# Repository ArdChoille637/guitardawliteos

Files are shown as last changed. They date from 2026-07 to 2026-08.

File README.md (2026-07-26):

# GuitarDAWLiteOS

Bare-metal **Raspberry Pi 5** loop recorder / guitarist workbench. I²S audio (PCM1808 ADC + PCM5102A DAC), SD recording, a plain display (no touch) with **5 rotary-encoder knobs + a sustain-pedal footswitch** as the interface — **no OS, no USB in the audio path.** Built on the [Circle](https://github.com/rsta2/circle) bare-metal framework (GPLv3).

> **This is the project front door.** Everything links from here.

## Status — 2026-07-10
- 🎉 **FIRST HARDWARE BOOT — success, first try.** Pi 5 (2GB) booted the M3 audio-engine kernel over HDMI: all 4 cores up, `I2S full duplex (TXRX): RUNNING`, capture counting **exactly 48,000 frames/s**, zero drops, zero ring overruns, storage drain at exactly the audio rate, thermal loop live. Milestone 0 ✅, Spike A ✅ (RP1 proven by the running I²S DMA itself), M3 engine verified live (codecs still to wire).
- ✅ **Research verified.** 29 load-bearing claims checked against primary sources. 6 were wrong; 3 of those change the build. → [docs/claim-verification.md](docs/claim-verification.md)
- ✅ **Spike B done.** Internal MCLK route impossible (`clk_i2s` is claimed by BCLK); an Arduino Nano ESP32 generates 12.2880 MHz instead, bench-verified via its own PCNT peripheral. → [esp32-mclk/](esp32-mclk/)
- ✅ **Milestone 3 code live** — full-duplex I²S monitor path (~1.0 ms worst-case in→out), lock-free SPMC broadcast ring (seqlock reserve/commit; host tests caught a real torn-read bug pre-hardware; passes plain + ThreadSanitizer), 4-core split. Adversarially reviewed (5 lenses, 2 rounds); the review caught a critical `KERNEL_MAX_SIZE` boot-blocker before first boot. → [src/](src/), [tests/](tests/), [planning/build-plan.md](planning/build-plan.md)
- ⏭️ **Next: Milestone 2 wiring** — breadboard the codecs + front-end per [docs/breadboard-build.md](docs/breadboard-build.md) (DAC playback first for the fastest win), Nano ESP32 → PCM1808 SCKI, then the M3 gate: clean tone in→out, 10 min, zero underruns.

## The 6 things verification changed (read before building)
1. **No `≤128` DMA chunk cap** — it's a constructor arg, default **8192**. Ring-buffer/SD batching gets *easier*. The doc was wrong.
2. **Pi 5 SD = BCM2712 SDHCI (`CEMMCDevice`, `0x1000FFF000`), not RP1, not `CSDHCIDevice`.** Tested & supported.
3. **Do NOT add `pciex4_reset=0`** with Circle — Circle brings up the PCIe root complex itself. Stock `config.txt`.
4. **MCLK cannot come from the Pi 5's own GPIO while I²S is running.** `clk_i2s` — the only RP1 clock generator with `pll_audio` as a parent — is already claimed for BCLK. **→ external MCLK generator (Nano ESP32), see Spike B above.**
5. **The two "MIT" libs (simplecodec3, Yin-Pitch-Tracking) are unlicensed** (all-rights-reserved). YIN patent is **expired** → clean-room reimplement from the 2002 paper.
6. **(2026-07-09)** Even the *revised* internal-MCLK mechanism from correction #4 (`clk_i2s→clk_gp0→GPIO4`) turned out to be a resource conflict, not just missing Circle code — see [claim-verification.md](docs/claim-verification.md).

## Hardware (Phase 1)
- Raspberry Pi 5 · microSD (Class-10/UHS-I) · HDMI monitor ≤1080p · USB-serial for the UART debug console.
- PCM1808 ADC (**bus master**, strap-only) · PCM5102A / GY-PCM5102 DAC (strap-only).
- **Arduino Nano ESP32** — external MCLK generator (see [esp32-mclk/](esp32-mclk/)), electrically independent of the Pi 5 except for the MCLK line + shared ground.

**Verified pin map** ([details](planning/build-plan.md#milestone-2--hardware-bring-up-i²s-loopback)) — **the PCM1808 masters the I²S bus** (2026-07-10 pivot: two free-running crystals can't stay fs-locked, so the ADC divides the Nano's MCLK into BCK/LRCK and the Pi runs I²S slave — see [docs/claim-verification.md](docs/claim-verification.md)):

| Source | Signal | → |
|--:|---|---|
| **PCM1808 BCK** | BCLK 3.072 MHz (ADC-driven) | Pi GPIO18 + DAC BCK |
| **PCM1808 LRCK** | LRCLK 48 kHz (ADC-driven) | Pi GPIO19 + DAC LCK |
| PCM1808 DOUT | data IN (capture) | → Pi GPIO20 |
| Pi GPIO21 | data OUT (playback) | → PCM5102A DIN |
| **Nano ESP32 D2/GPIO5** | MCLK 12.288 MHz | → PCM1808 SCKI only |

⚠️ **PCM5102A breakout: set the XSMT pad HIGH (unmute)** — ships muted. ⚠️ **PCM1808: strap MD1=MD0=HIGH (master 256fs), FMT=GND, before power-on** — board-specific pin table in [docs/adc-hookup.md](docs/adc-hookup.md).

## Map
- **[planning/build-plan.md](planning/build-plan.md)** — milestones 0–6, tasks with effort, risk register, pinned dependencies.
- **[docs/claim-verification.md](docs/claim-verification.md)** — full verdict table + 6 consequential corrections with sources.
- **[docs/hardware-review.md](docs/hardware-review.md)** — datasheet-verified BOM, power tree, connection/netlist table, **guitar front-end design**, grounding, risk register.
- **[docs/schematic.md](docs/schematic.md)** — buildable schematic: refdes BOM, net-by-net netlist, **SPICE-verified** front-end, build order, ERC self-check (netlist = rev-A Pi-as-master; see its pivot banner). Sheets: [front-end 5 V](docs/frontend-schematic.svg) · [front-end 9 V TL072 (as-built)](docs/tl072-frontend-schematic.svg) · [codec & clocks (as-built)](docs/codec-power-schematic.svg). Sim: [sim/](docs/sim/).
- **[docs/wiring-diagram.svg](docs/wiring-diagram.svg)** — as-built bench wiring overview (Nano MCLK → PCM1808 **bus master** → Pi 5 slave + PCM5102A; clocks/data/power domains).
- **[kicad/](kicad/)** — openable **KiCad project** (`guitardawliteos.kicad_pro`, KiCad-10-verified) + generated netlist/symbols/BOM from `gen.py` (ERC-checked). See [kicad/README.md](kicad/README.md).
- **[docs/pcb-learning-path.md](docs/pcb-learning-path.md)** — **follow-along PCB-design curriculum + open-hardware roadmap** (M1 board-from-netlist → M4 Pi 5 HAT → M6 rev-B HAT+ → M7 faceplate → M8 retro deck → M9 CM5 carrier), hackability + licensing.
- **[docs/parts-order.md](docs/parts-order.md)** — **DigiKey prototyping order** (verified live 2026-07-01): breadboard + codecs + front-end + tape Level A + Touch Display 2, with MPNs, quantities, substitutions for dead parts, and the not-DigiKey list.
- **[docs/retro-deck-design.md](docs/retro-deck-design.md)** — **Phase-2 architecture (verified; UI pivot 2026-07-23)**: **5 rotary encoders + sustain pedal + display-only panel** (TD2 via `rp1dsi` with `bEnableTouch=FALSE`, zero GPIO — or plain HDMI; SPI TFT ruled out), cassette tape loop as analog insert (Level A ships in rev B, VINR return + REM punch-in), three-layer retro mechanicals, recomputed rev-B GPIO budget (J8 fully allocated + MCP23017 expander).
- **[docs/breadboard-build.md](docs/breadboard-build.md)** + [breadboard-layout.svg](docs/breadboard-layout.svg) — solderless build with the GY modules + a DIP op-amp; placement + step-by-step + gotcha checklist.
- **[docs/adc-hookup.md](docs/adc-hookup.md)** — **bench card: every wire for Pi 5 + PCM1808 + Nano ESP32 capture hookup** (power, ground, straps, clocks, data, order of operations).
- **[docs/tl072-frontend.md](docs/tl072-frontend.md)** — **drawer-parts front-end variant: TL072 on 9 V** (SPICE-verified; two changes from the canonical schematic) + CD4053BE rev-B notes. Schematic sheet: [tl072-frontend-schematic.svg](docs/tl072-frontend-schematic.svg).
- **[docs/build-setup.md](docs/build-setup.md)** — toolchain, build, SD flash, UART.
- **[docs/debug-probe.md](docs/debug-probe.md)** — **Raspberry Pi Debug Probe on the Pi 5**: UART console (mode A) vs. SWD breakpoint debugging of all four cores (mode B), cabling, and the GPIO14/15 conflict with the encoder pinout.
- Original Phase-1 research reference: project `CLAUDE.md` (the GuitarDAWLiteOS research doc).

## Build foundation (pinned)
Circle `develop` @ `22722a7` · `RASPPI=5` → `kernel_2712.img` · FatFs R0.16 (`addon/fatfs`) · YIN clean-room.

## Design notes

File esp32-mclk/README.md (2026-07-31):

# esp32-mclk

Standalone MCLK generator for the PCM1808 ADC, running on an **Arduino Nano
ESP32** (ESP32-S3). This is the resolution to Spike B — the Pi 5 cannot
generate a `pll_audio`-locked 12.288 MHz clock on any GPIO while its I²S
peripheral is running (see [../docs/claim-verification.md](../docs/claim-verification.md),
"Update 2026-07-09"). This board sidesteps the problem entirely by generating
MCLK off-chip.

**✅ Bench-tested 2026-07-09**, without a scope — see "How it was verified"
below. Measured **12.2880 MHz**, exact match to target.

## What it does

`esp32-mclk.ino` configures the ESP32-S3's `i2s_std` peripheral as an
MCLK-only clock source:
- Sample rate 48 kHz, `mclk_multiple = I2S_MCLK_MULTIPLE_256` → 12.288 MHz,
  using the driver's default clock source (`I2S_CLK_SRC_DEFAULT` = the
  general-purpose `PLL_160M`). **Correction:** an earlier version of this
  file said ESP32-S3 has a dedicated Audio PLL (APLL) and that the code
  explicitly selected it. Neither is true — APLL is original-ESP32-only
  (confirmed against the installed SDK's `soc/clk_tree_defs.h`); the S3's
  `i2s_std` clock source options are just `PLL_160M`/`PLL_240M`/`XTAL`. The
  code now just uses the driver's sane default rather than requesting a
  clock source that doesn't exist on this chip.
- BCLK/WS/DATA GPIOs are all `I2S_GPIO_UNUSED` — only the MCLK pin is driven.
  Since the 2026-07-10 clock pivot the **PCM1808 divides this MCLK into
  BCLK/LRCLK** (it straps as bus master) and the Pi 5 runs I²S *slave* on
  GPIO18/19/20/21 — see [docs/adc-hookup.md](../docs/adc-hookup.md); this
  board never touches those signals either way.
- A built-in **self-test**: the ESP32-S3's PCNT (pulse counter) peripheral
  counts edges on D3 (GPIO6) and prints the measured frequency once a
  second — see below.

## How it was verified (no oscilloscope on hand)

Jumper **D2 → D3** (GPIO5 → GPIO6) so the MCLK output loops back into the
chip's own PCNT counter input, then watch the Serial Monitor at 115200 baud:
a fresh reading prints every second, e.g. `Measured MCLK: 12.2880 MHz
(target 12.288000 MHz)`. This confirms the output frequency is correct; it
does **not** characterize jitter or duty cycle the way a real scope would —
not expected to matter for a consumer-grade ADC like the PCM1808, which per
`[CORR-4]`/E2 only needs fs-sync, not phase-lock. **Remove the D2–D3 jumper**
before wiring the board to the real PCM1808 — the self-test loopback isn't
part of normal operation.

## Build & flash

1. Arduino IDE (or `arduino-cli`) with the **esp32:esp32 core v3.x**
   (Espressif's own board index, not Arduino's `arduino:esp32` package —
   that one tops out at ESP-IDF 4.4 and lacks the `driver/i2s_std.h` /
   `driver/pulse_cnt.h` APIs used here). Board index URL:
   `https://raw.githubusercontent.com/espressif/arduino-esp32/gh-pages/package_esp32_index.json`
2. Board: **`esp32:esp32:nano_nora`** ("Arduino Nano ESP32" in the IDE's
   board list under the Espressif index — a different FQBN from the
   Arduino-index entry of the same display name).
3. Open `esp32-mclk.ino`, select the board's port, upload.
   - **This board's native USB has no auto-reset circuit** — uploads don't
     "just work" the way they do on boards with an FTDI/CH340 chip.
     Uploading via `arduino-cli upload` / the IDE's dfu-util path may fail
     with "No DFU capable USB device available." If so, flash directly with
     `esptool` instead (see below) while the board is in **Native Boot
     mode**: short pin **B1 to GND**, press **RESET** once, confirm the
     onboard RGB LED goes solid **purple**, then flash. Afterward, remove
     the B1–GND jumper and press RESET once (single tap) to boot normally.
4. Open the Serial Monitor at 115200 baud — expect a startup banner
   followed by a `Measured MCLK: ...` line every second.

### Manual esptool flash (if dfu-util upload fails)
```sh
arduino-cli compile --fqbn esp32:esp32:nano_nora --build-path /tmp/esp32-mclk-build .

PLATFORM=<arduino15>/packages/esp32/hardware/esp32/3.3.10   # find via: arduino-cli core list
BUILD=/tmp/esp32-mclk-build
PORT=<port shown while the board is in Native Boot mode / solid purple LED>

esptool --chip esp32s3 --port "$PORT" --before default-reset --after hard-reset write-flash -z \
  --flash-mode dio --flash-freq 80m --flash-size 16MB \
  0x0      "$BUILD/esp32-mclk.ino.bootloader.bin" \
  0x8000   "$BUILD/esp32-mclk.ino.partitions.bin" \
  0xe000   "$PLATFORM/tools/partitions/boot_app0.bin" \
  0xf70000 "$PLATFORM/variants/arduino_nano_nora/extra/nora_recovery/nora_recovery.ino.bin" \
  0x10000  "$BUILD/esp32-mclk.ino.bin"
```

## Wiring (to the PCM1808, after the self-test jumper is removed)

| Nano ESP32 pin | Signal | → |
|---|---|---|
| D2 (GPIO5) | MCLK 12.288 MHz | PCM1808 **SCKI (pin 6)** only |
| GND | common ground | tie to the Pi 5 / breadboard ground |

**On the bench: power the Nano ESP32 from its own USB-C.** Do **not** feed the
5 V breadboard rail into VIN — the VIN regulator wants 6–21 V, so 5 V is out of
spec. On the bench it is electrically independent of the Pi 5 audio board except
for the MCLK line and a shared ground.

*(Target build: VIN from the rig's +9 V rail, 7809 off the central 18 V pack —
`docs/power-tree-18v.md`. Not raw 18 V: a fresh pack sits near 20.5 V, too close
to the 21 V ceiling.)*

## Why not the Pi 5 / a Pico / a Si5351

- **Pi 5 GPCLK0 (internal):** ruled out — `clk_i2s` (the only RP1 clock
  generator with `pll_audio` as a parent) is already claimed by the I²S
  peripheral for BCLK the whole time audio runs; no other RP1 clock
  generator can source `pll_audio` at all. See claim-verification.md.
- **Si5351A:** viable alternative (I²C-configured clock-gen chip), but a new
  part to source; not chosen here since a Nano ESP32 covers the same job
  through a documented high-level driver call (`i2s_std`'s `mclk_multiple`)
  instead of hand-computing register values from a datasheet.
- **RP2040/Pico:** also viable — its GPOUT clock divider is functionally
  in the same category as what ESP32-S3 actually has (a plain divider, not
  a dedicated audio PLL — that APLL advantage was a mistaken claim, see
  above). The real reason to prefer the Nano ESP32 here is the same one as
  vs. the Si5351: less hand-rolled clock-register code, not superior clock
  hardware.

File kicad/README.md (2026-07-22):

# GuitarDAWLiteOS — KiCad project files

> ⚠️ **This netlist is rev-A (Pi-as-master) and predates the 2026-07-10 clock pivot.** `gen.py` still routes
> **MCLK from Pi header pin 7 (GPIO4)** into the PCM1808 SCKI and **straps MD0/MD1 to GND (slave)**. The
> as-built bench is the opposite: **MCLK from the Nano ESP32 D2**, **MD0/MD1 to +3.3 V (ADC = bus master)**,
> Pi = I²S slave. Use this project as a **PCB-design learning vehicle only** — do **not** fab a board from it
> until `gen.py` is re-generated for the pivot (rev-B). The as-built truth is [../docs/adc-hookup.md](../docs/adc-hookup.md)
> + the wiring/codec SVG sheets. "Same I²S/clock topology either way" below refers to the *breadboard vs
> bare-chip* choice, **not** to master/slave — that pivot post-dates this board.

An openable KiCad project for the Phase-1 audio board, plus the generated inputs that feed it.

> **To open in KiCad: open `guitardawliteos.kicad_pro`.** A netlist (`.net`) and a symbol library (`.kicad_sym`) are *not* openable projects — that's why the earlier files wouldn't load. New to this? Read [../docs/pcb-learning-path.md](../docs/pcb-learning-path.md).

| File | What it is |
|---|---|
| **`guitardawliteos.kicad_pro`** | **the KiCad project — open THIS** |
| `guitardawliteos.kicad_sch` | schematic (titled blank canvas; draw it per the learning path) |
| `guitardawliteos.kicad_pcb` | board (blank; import the netlist, or lay out from your schematic) |
| `sym-lib-table` | registers the `GuitarDAWLiteOS` symbol lib into the project |
| `gen.py` | generator: defines components + nets, runs ERC-lite, emits the files below. Re-run: `python3 gen.py` |
| `guitardawliteos.net` | **KiCad netlist** (Eeschema export format) — import into the PCB editor |
| `guitardawliteos.kicad_sym` | **custom symbol library** — PCM1808 + PCM5102A (not in stock KiCad libs) |
| `bom.csv` | bill of materials (ref, value, footprint) |
| `validate.py` | parses + schema-checks the `.net` and `.kicad_sym` (stdlib; stands in for `kicad-cli`) |

## What this design is
A **bare-chip carrier board**: discrete **OPA1662** guitar front-end + bare **PCM1808** ADC + bare **PCM5102A** DAC + **AP2112-3.3** LDO + a **2×20 header** to the Pi 5. 41 components, 28 nets. Pinouts are datasheet-verified; the front-end matches [../docs/schematic.md](../docs/schematic.md) and is SPICE-verified.

> **Differs from the breadboard build** ([../docs/breadboard-build.md](../docs/breadboard-build.md)): that one uses the **GY-PCM5102 module** (onboard LDO + output filter). This PCB uses the **bare PCM5102A**, so it includes what the module hides — the AP2112 LDO (5 V→3.3 V), the charge-pump caps (C10/C11 on CAPP/CAPM/VNEG), the LDOO cap (C14), and the output RC (Rol/Col, Ror/Cor). Same I²S/clock/front-end topology either way.

## Use it — two paths

**A. PCB-first (fastest):** the netlist already carries footprints (all stock KiCad libs), so you can skip drawing a schematic.
1. Open `guitardawliteos.kicad_pro` → open the **PCB Editor**.
2. **File → Import → Netlist…** → select `guitardawliteos.net` → *Update PCB*. All 41 parts drop in with footprints + ratsnest.
3. Arrange and route. Keep the analog front-end (U1, J1, the front-end R/C) away from the I²S clocks; single-point star ground; FB1 + C2/C3 right at U2 VCC.

**B. Schematic-first:** to draw the full schematic.
1. **Preferences → Manage Symbol Libraries → add** `guitardawliteos.kicad_sym` (it provides `PCM1808` and `PCM5102A`).
2. Draw using those two symbols + stock `Device:R/C`, `Amplifier_Operational:OPA1662` (or `Device:Opamp_Dual`), `Connector_Generic:Conn_02x20_Odd_Even` (Pi), `Regulator_Linear:AP2112K-3.3`.
3. Annotate → assign footprints (see `bom.csv`) → **Tools → ERC** → generate netlist → PCB.

## Footprints (defaults — reassign freely)
| Part | Footprint |
|---|---|
| U1 OPA1662 | `Package_SO:SOIC-8_3.9x4.9mm_P1.27mm` |
| U2 PCM1808 | `Package_SO:TSSOP-14_4.4x5mm_P0.65mm` |
| U3 PCM5102A | `Package_SO:TSSOP-20_4.4x6.5mm_P0.65mm` |
| U4 AP2112-3.3 | `Package_TO_SOT_SMD:SOT-23-5` |
| R / C | `R_0805` / `C_0805` (10 µF/2.2 µF → `C_1206`) |
| RV1 | `Potentiometer_THT:Trimmer_Bourns_3296W_Vertical` |
| J1/J2 | `PinHeader_1x03` (swap for an audio-jack footprint) |
| J3 Pi | `PinHeader_2x20_P2.54mm` |

Prefer hand-soldering? Reassign R/C to `Resistor_THT` / `Capacitor_THT` in the footprint assignment step.

## Notes & caveats
- **gen.py ERC-lite** checks: every component pin on exactly one net, every net ≥2 nodes, unique refs, footprints present, s-expr balanced. It is clean (it caught two real omissions during authoring — PCM5102A FMT and an unused Pi 3V3 pin). `python3 validate.py` re-parses + schema-checks the outputs (41 components / 28 nets / 129 nodes / 2 symbols — all resolve). Still run **KiCad's own ERC** after drawing the schematic.
- **Validation status: ✅ KiCad-verified.** `kicad-cli` (KiCad **10.0.4**) loaded the symbol library via `sym upgrade` (parsed + re-saved, no warnings) and `sym export svg` rendered both `PCM1808` and `PCM5102A` with all pin names — so the symbols open cleanly in KiCad. The netlist is schema-checked by `validate.py` (41 comp / 28 nets / 129 nodes, all refs resolve); KiCad imports netlists only through the Pcbnew GUI (no CLI path), so confirm that import in the app. The committed `.kicad_sym` uses the portable `20211014` format (reads in KiCad 6–10).
- The Pi header's **3V3 pin is intentionally unused** — this board makes its own 3.3 V via U4 (so don't also wire Pi 3V3 in).
- U4 **EN (pin 3) is tied to VIN** (always enabled).
- Confirm your exact op-amp's pinout matches the standard dual layout (1=OUTA…8=V+) before committing copper.
- This is a **netlist + symbols**, not a finished PCB layout — placement/routing is yours (see the breadboard guide for the placement strategy, which applies to the PCB too).

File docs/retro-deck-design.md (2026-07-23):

# GuitarDAWLiteOS — Retro Deck Design (Phase 2 architecture)

**Date:** 2026-06-30. The three Phase-2 directions — **display**, **cassette analog tracking**, **retro-gear form factor** — researched against primary sources (Circle source at our pinned commit, TI/Tascam datasheets, the official HAT+ spec, maker-community practice) with adversarial verification on the two architecture-deciding claims. Both **confirmed**.

> **UI pivot (2026-07-23, Michael's decision): NO touch.** The interface is **5 rotary encoder knobs
> (with push) + a sustain-pedal footswitch + a plain display**. Touch is dropped as an input method —
> which fits the retro-deck concept better anyway (real knobs on a tape deck). §1 and §1b below are
> rewritten to the new facts (all verified against the pinned Circle tree, 2026-07-23); the GPIO budget
> in §4 is recomputed and now closes only with a zero-GPIO display (DSI display-only or HDMI).

**The product in one sentence:** a cassette-deck-styled open-hardware guitar workstation — Pi 5 + audio HAT+ inside a folded-metal/wood-cheek chassis, a PCB faceplate with real VU meters, illuminated transport keys, **five rotary knobs and a footswitch jack as the interface**, a display as the "cassette window," and an *optional real cassette tape loop* as a lo-fi analog insert.

---

## 1. Display (no touch) — two zero-GPIO options; SPI TFT ruled out ✅ (re-verified 2026-07-23)

**The display is output-only.** Verified against the pinned Circle tree after the UI pivot:

- **Option A (product default): Touch Display 2 as a *display-only* panel.** Circle's `addon/rp1dsi`
  supports this first-class: `CRPiTouchScreen(pInterrupt, nDepth, nDisplay, bEnableTouch=FALSE)`
  (`rpitouchscreen.h:40-42`) — with `FALSE` the GT911 is **never even powered** (CTP_RESET stays
  deasserted, no touch I²C traffic, `rpitouchscreen2.cpp:100-136`), while panel init, DSI DPI-DMA
  autonomous scanout, I²C backlight control, and the vsync callback all still work. LVGL runs fine
  without touch (`CLVGL(CDisplay*)`; the `touch1` lookup is optional/non-fatal, `lvgl.cpp:151`).
  **Zero J8 GPIOs** (video + control I²C ride the dedicated DISP FFC on RP1 bus 6/4; only 5 V/GND from
  pins 2/6) — the property the whole GPIO budget in §4 now depends on. Still portrait-native 720×1280 →
  LVGL 90° software rotation. Yes, we pay for a touch layer we don't use — there is **no non-touch
  official DSI panel**, and `rp1dsi` supports **only** the official panels (hard-coded regulator
  auto-detect at I²C 0x45, `rpitouchscreen.cpp:62-100`; third-party DSI would need a new panel driver).
- **Option B (dev bench, works today): HDMI.** The M3 kernel already renders on HDMI via
  `CScreenDevice`, headless-safe. Unlimited panel choice, zero GPIO, but: firmware framebuffer path is
  the one Circle marks "limited", mode fixed at boot (no hotplug), bulkier inside the chassis, and the
  documented WLAN-vs-HDMI interaction (irrelevant — we use no WLAN). Fine until the faceplate forces
  the decision.
- **SPI TFT: RULED OUT (2026-07-23).** Circle does have ST7789/ILI9341 drivers (`addon/display/`), but
  the pin budget cannot close: 5 encoders + pedal need 16 GPIOs, and a TFT needs SPI0 CE/DC/RST on pins
  the encoders now own — plus the APA102 bargraph shares SPI0 and has **no chip select** (it clocks in
  all bus traffic), so TFT-on-SPI0 corrupts it electrically. Dead option, not a fallback.

**Spike C (re-scoped): display-only + controls bring-up.** Build `sample/28-touchscreen` with
`DSI_DISPLAY=0` and `bEnableTouch=FALSE` on the TD2, then `addon/lvgl/sample` with 90° rotation and
**encoder-driven navigation** (LVGL encoder input group). Gate for committing the faceplate cutout
dimensions. HDMI path needs no spike — already proven live.

---

## 1b. Control surface — 5 rotary encoders + sustain-pedal footswitch (NEW 2026-07-23, verified)

**Hardware on hand:** five digital rotary encoder knobs with integrated push switches (EC11-class or
KY-040-class modules) + (planned) a Yamaha sustain pedal as the footswitch.

**Encoder electrical facts (verified in the pinned Circle tree):**
- RP1 internal pull-ups exist and work: `SetMode(GPIOModeInputPullUp)` (`gpiopin2712.cpp:257-299`).
  Also enable the RP1 **Schmitt trigger** per input (`SetSchmittTrigger`, `gpiopin2712.cpp:301-319`) —
  `SetMode` does *not* do it automatically.
- **KY-040 module gotcha:** the boards carry 10 k pull-ups on A/B to their "+" pin — power "+" from
  **3.3 V only** (5 V would drive 5 V into RP1 pads through those pull-ups). The SW pin usually has
  **no** onboard pull-up → still enable the internal one. Bare EC11: common → GND, internal pull-ups on
  A/B/SW, nothing else needed.
- All pins must be configured on **core 0 during `CKernel::Initialize`** (RP1 southbridge assert,
  `gpiopin2712.cpp:185`), before the secondary cores start.

**Read strategy (decided): poll from core 3, no GPIO interrupts.** Circle *has* full RP1 GPIO IRQ
machinery, but all peripheral IRQs land on **core 0** — the audio DMA/mix core — and 5 fast-turned
encoders emit O(10³) edges/s plus bounce bursts; each would be a PCIe-latency ISR stealing audio
headroom for zero benefit. Instead:
- One `CGPIOPin::ReadAll()` returns the **entire GPIO bank 0 in a single register read**
  (`gpiopin2712.cpp:594-597`) — all 16 inputs in one ~1 µs PCIe round-trip, never 16 separate reads.
- Core 3 (currently the 2 s stats loop) restructures into a **2 kHz tick** (worst-case flicked EC11 ≈
  400 edges/s → ≥1 kHz needed; 2 kHz safe). Cost: **≈0.2–0.5 % of one core** — negligible.
- Quadrature decode via the 16-entry transition table (bounce between adjacent Gray states cancels —
  no time-debounce needed); gate to one count per detent. Push switches + pedal: ~10 ms
  consecutive-sample debounce on the same tick. Events → small SPSC queue to the UI (same pattern as
  the audio ring).

**Sustain pedal (Yamaha FC5/FC4A) — verified facts, incl. the polarity gotcha:**
- ¼″ **TS** plug, passive momentary leaf switch, nothing else inside (no debounce — do it in software).
  (FC3A is the TRS half-damper — different animal, don't buy that one.)
- **Yamaha is NORMALLY CLOSED at rest — pressing OPENS the contact** (teardown + FC4A spec sheets +
  measurement consensus; much web folklore says the opposite and is wrong; Roland DP-series is the
  *same* NC convention, Korg/Casio are the NO camp; Boss FS-5U has a polarity slide).
- **Firmware handles polarity by auto-calibration, like every commercial keyboard:** sample the GPIO at
  boot (and on jack insertion) and latch that level as RELEASED — works for Yamaha NC, Korg-style NO,
  and either FS-5U slide position with zero config. (Yamaha's own FAQ documents this exact power-on
  sampling; a manual invert setting is the fallback, per Roland's "Damper Polarity" menu precedent.)
- Wiring: jack sleeve → GND, tip → GPIO25 with internal pull-up + Schmitt. Caveat: an **unplugged jack
  reads identical to "pressed"** for an NC pedal — use a switched-contact jack on the faceplate if
  plug-detection matters.

**Suggested knob map (v0, Michael's to override):** K1 input trim · K2 monitor/output level · K3 loop
select (push = arm rec/overdub) · K4 feedback/decay · K5 menu-navigate (push = confirm). Pedal =
classic looper semantics: tap = record/overdub toggle, double-tap = stop, hold = clear.

---

## 2. Cassette analog tracking — ship Level A, provision Level B, defer Level C ✅ (skeptic-confirmed w/ corrections)

**Architecture: the tape path is an optional analog *insert*, not the recording medium.** The dry 24-bit loop always stays in DSP; `TAPE OUT` sends the mix to tape, the deck's output returns into the PCM1808's **currently-unused VINR channel**, and the UI blends wet/dry. Cassette S/N (~59 dB) and wow/flutter (0.25 %) are the *product* — hiss, HF saturation, chorus-like warble — exactly the effect the market already validates (Onde Magnetique OM-1, Chase Bliss Generation Loss).

### Level A — external deck interface (**ships in rev B**, ~$5–8 BOM)
| # | Provision | Detail (skeptic-corrected values) |
|---|---|---|
| 1 | **TAPE OUT** RCA pair | PCM5102A 2.1 Vrms → **~17.5 dB pad** to consumer −10 dBV. A 5.6k/1k L-pad alone gives only 16.4 dB → **include the trim pot** (not optional) to hit deck nominal (Tascam 202MKVII: −9 dBu = 0.28 Vrms in, 33 kΩ). |
| 2 | **TAPE IN** jack | → mono-sum → AC-couple → **VINR**, selected by a **jumper** (default = AC-ground, so rev-A behavior is untouched). Deck return ~0.46 Vrms from 1 kΩ drives the 60 kΩ / 3 Vpp input directly with ~7.3 dB headroom. |
| 3 | **REM jack** (2.5 mm TS) | optoMOS relay on **1 GPIO** = contact closure in series with the deck motor supply → **hardware punch-in from the footswitch**, exactly like a Portastudio. Works on portable/Portastudio-class decks (component hi-fi decks don't have REM — hence #4). |
| 4 | **IR-LED footprint** (unpopulated) | second GPIO; for hi-fi decks that only take IR remotes (e.g. 202MKVII's RC-1331). |
| 5 | **TRANSPORT header** (8-pin, unpopulated) | `SOLENOID_DRV, MOTOR_EN, TACH_IN, SW1(tape-present), SW2(rec-inhibit), SW3(stop-pos), V_TRANSPORT(6V/12V jumper), GND` — pin budget proven by the AVRTapeControl project against exactly our candidate mechanisms. |

### Level B — embedded mechanism (**provisioned, populate later**)
New-manufacture Tanashin TN-21ZLG-clone transports are purchasable (~$10–20, AliExpress; the same clone family ships in current TEAC/Tascam dual decks), plus TA7668-based record/play head boards (~$10). Boombox-grade fidelity — which *suits* the lo-fi bus. Level B = mount a mech in the chassis, drive it from the TRANSPORT header, feed it from TAPE OUT/IN. No HAT respin needed.

### Level C — our own record path (**deferred; future daughter-board**)
Playback preamp is well-trodden (Rod Elliott P247-style NAB 3180 µs/120 µs EQ, ~40–46 dB gain, modern op-amps); the **bias/erase oscillator (60–100 kHz) + record amp + calibration** is the genuinely hard analog-tape part. Not on the HAT. Keep the VINR path clean so a future head-preamp board can drop in.

**Firmware:** tape insert = wet/dry blend UI + REM punch-in mapping; Level B adds transport state-machine (solenoid pulse timing, tach-based end-of-tape stop — logic portable from AVRTapeControl).

---

## 3. Retro form factor — three-layer mechanical architecture ✅

The HAT+ spec (2023-12, current 2024-12) **deprecates the rigid 65×56 rule**: a HAT+ needs only the 40-pin connection, ≥1 aligned mounting hole, and the ID EEPROM for branding. Oversized boards are explicitly legal — the **Blokas Pisound (100×56 mm)** is the decade-proven precedent for exactly our use case (¼″ jacks exiting the rear wall).

```
┌──────────────────────────────────────────────────────┐
│  ENCLOSURE  — folded-metal U-chassis + wood cheeks   │  ← open DXF, classic hi-fi build
│  ┌────────────────────────────────────────────────┐  │
│  │ FACEPLATE PCB — the entire front cosmetics     │  │  ← 2.0 mm FR4, silkscreen art,
│  │ VU meters · transport keys · TD2 window ·      │  │    parts' nuts clamp it (no visible
│  │ knobs · (optional cassette door)               │  │    fasteners); rear component PCB
│  └────────────────────────────────────────────────┘  │
│   Pi 5 + Active Cooler + [AUDIO HAT+] + cassette mech │  ← 16 mm standoffs/stacking header
└──────────────────────────────────────────────────────┘
```

1. **Audio core = "GuitarDAW Audio HAT+"** — the rev-B board. Either strict 65×56.5 or a **Pisound-style stretch (~100×56)** so guitar/line/tape jacks exit the rear wall directly. Requirements adopted:
   - **CAT24C32 ID EEPROM** @ I²C 0x50 (Standard class) on ID_SD/ID_SC, 3.9 kΩ pull-ups, nothing else on those pins. Costs <$1; buys the HAT+ wordmark **and** a published Linux device-tree overlay (`simple-audio-card` for PCM1808/PCM5102A) — the same open board then works plug-and-play on Linux too. Bare-metal Circle ignores it at runtime.
   - **16 mm standoffs + 16 mm stacking header** → the official **Active Cooler fits underneath** (this is also the thermal answer, see below).
   - **Left-edge cutout** aligned to the Pi 5 PCIe FFC (keeps NVMe/Hailo expansion open); PoE keep-out per spec; all four holes on the 58×49 grid.
   - Exports to the panel: **buffered L/R line taps** (for meters) + an **SPI + GPIO control bus** connector.
2. **Faceplate PCB** — 2.0 mm FR4 (or copper-poured 1.6 mm against flex), the standard eurorack/pedal-DIY faceplate technique: solder-mask + silkscreen retro graphics, exposed-gold "brushed metal" accents, cutouts for the meters and the TD2 window; pots/jacks/switch nuts clamp faceplate to a rear component PCB carrying switches/LEDs — fastener-free face.
3. **Enclosure** — folded sheet-metal chassis + **wood side cheeks** (both as open DXF for any sheet-metal/CNC service). Hammond 1456CWW (real walnut sides) is a fine *v1 prototype* shell but the walnut line is being discontinued — don't make it the open-hardware dependency.

**Panel hardware (all current-production, open-BOM-safe):**
- **VU meters: real 200 µA moving-coil movements** (sub-$5, current production; the strongest retro cue). Drive: TL072 precision full-wave rectifier off the HAT's buffered line taps, **on the panel PCB**, with damping caps (cheap movements are underdamped — budget up to ~440 µF). 
- **LED bargraph (alternative/addition): NOT LM3915** — discontinued, wrong for an open BOM. Use **APA102/SK9822 SPI-clocked addressable LEDs** driven by firmware (we own the sample stream → true dBFS ballistics), behind silkscreen segment windows = convincing '80s bargraph.
- **Transport keys:** real interlocking piano-key banks are NOS-only → design around **NKK UB-series illuminated square pushbuttons** (current production, momentary; "latching" + lamp state in firmware, which a loop recorder wants anyway) + standard 3PDT footswitches.
- **Thermal:** Pi 5 soft-throttles at 80 °C — a closed box with passive cooling *will* throttle mid-take. **Active Cooler under the HAT** + period-correct **vent grilles** (cassette decks always had them — free styling) + firmware fan curve; the guitar signal path is analog+DMA, so fan PWM noise stays out of the audio.

---

## 4. Rev-B GPIO budget (recomputed 2026-07-23 for the knob-UI pivot — finalize at rev-B schematic)

**The math:** 28 J8 GPIOs − 2 (EEPROM) − 4 (I²S) − 2 (I²C1) − 2 (APA102 data/clk) = 18 native pins;
the new controls need **16** (5 × {A, B, SW} + pedal). It closes **only** because the display is
zero-GPIO (§1) — and only by reclaiming the SPI-TFT fallback pins (7/8/9), the header-UART breakout
(14/15 — the JST-SH debug connector is unaffected), and moving the slow tape-transport signals to an
**MCP23017 expander on I²C1** (the "panel expander option" from the old table, now exercised).

| GPIO | Assignment | Was |
|---|---|-----|
| 0/1 | ID EEPROM (ID_SD/ID_SC) — nothing else (HAT+ rule) | unchanged |
| 2/3 | I²C1 → **MCP23017 panel expander** (transport slow signals + NKK keys + lamps) | "expander option" |
| 4 | **ENC1_A** | free (reclaimed from MCLK) |
| 5 / 6 | ENC1_B / ENC1_SW | REM → 26 · IR_TX → 27 |
| 7 / 8 / 9 | ENC2_A / ENC2_B / ENC2_SW | SPI0 CE1/CE0/MISO (SPI-TFT fallback — **dropped**) |
| 10 / 11 | SPI0 MOSI / SCLK → **APA102 bargraph** (data + clock) | unchanged |
| 12 / 13 | ENC3_A / ENC3_B | spare PWM (lamp dimming → expander or APA chain) |
| 14 / 15 | ENC3_SW / ENC4_A | header UART0 breakout (reclaimed; JST debug console unaffected) |
| 16 / 17 | ENC4_B / ENC4_SW | SOLENOID_DRV / MOTOR_EN (→ expander) |
| 18–21 | I²S (ADC-driven BCK/LRC + data; Pi slave) | unchanged, fixed |
| 22 / 23 / 24 | ENC5_A / ENC5_B / ENC5_SW | aux block |
| 25 | **SUSTAIN_PEDAL** (¼″ TS jack, pull-up + Schmitt, boot auto-polarity — §1b) | aux block |
| 26 | REM optoMOS (punch-in relay) | was 5 |
| 27 | IR_TX footprint (38 kHz carrier — needs a native pin, can't come from the expander) | was 6 |

**On the MCP23017:** SOLENOID_DRV, MOTOR_EN, TACH_IN, SW1–3 (tape-present / rec-inhibit / stop-pos),
NKK UB transport keys, lamp on/off. All slow; acceptable because Level-B tape is "provision, populate
later."

**Honest consequences of closing the budget:**
- **J8 is 100 % consumed — zero spare native GPIOs.** "Broken-out spares" hackability now lives on the
  I²C1 expander bus instead. (Optional recovery: REM is slow — moving it to the expander frees GPIO26
  as the single spare.)
- Solenoid pulse timing and TACH edge-timing from an I²C expander are degraded (poll-only; no free
  native INT pin) — flagged for the rev-B schematic if Level B ever populates.
- PWM lamp dimming is gone; NKK lamps go on/off via expander or ride the APA102 chain.

**Standing rule (amended 2026-07-23):** never reassign 18–21; keep **10/11** for the APA102 (SPI0
data/clock). The old "keep all of 7–11 for SPI0" rule died with the SPI-TFT option; GPIO4's
reservation died with the MCLK reclaim.

## 5. What changes where
- **Rev A (current KiCad project)**: unchanged — it's the learning vehicle. Everything above is **rev B**.
- **`kicad/gen.py`**: rev-B netlist additions (tape pads/jumper, REM optoMOS, TRANSPORT header, EEPROM, line-tap buffers, panel connector) get added behind a clearly-marked REV-B section when we cut that board.
- **Build plan**: Spike C (DSI bring-up) joins Spike A/B in Milestone 1; faceplate + enclosure become new milestones in the learning path (M7/M8).
- **CM5 carrier (phase 3)**: route the same 22-pin DSI FPC + 5 V display power; **rp1dsi is unconfirmed on CM5** (Circle lists CM5 as "reported to work") → its own validation spike.

## 6. Risk register (Phase 2)
| Risk | Severity | Mitigation |
|---|---|---|
| `rp1dsi` is young, unreleased | Med | Spike C (display-only, `bEnableTouch=FALSE`) before faceplate commit; plain-HDMI fallback already proven live |
| TD2 portrait-only scanout | Low | LVGL 90° rotation from day one (unchanged by the touch drop) |
| J8 100 % consumed by the knob UI | Med | Expander bus is the hackability escape hatch; REM→expander frees one spare if needed |
| REM punch-in only fits portable/Portastudio decks | Low | IR footprint + TRANSPORT header cover the rest |
| Piano-key/walnut parts are NOS/discontinued | Med | NKK UB keys + open-DXF wood cheeks in the open BOM; NOS only for personal builds |
| Pi 5 throttling in closed box | High | Active Cooler under 16 mm-standoff HAT + vent grilles + fan curve |
| LM3915 in old references | — | banned from BOM; APA102/SK9822 instead |

**Sources:** Circle `addon/rp1dsi/*`, `lib/usb/usbtouchscreen.cpp`, `lib/input/xpt2046touchscreen.cpp`, README/CHANGELOG @ `22722a76`; GitHub commits API (addon age); raspberrypi.com Touch Display 2 docs + HAT+ spec (2024-12 build) + Pi 5 mechanical drawing; TI SLAS859C / SLES177B; tascam.com 202MKVII specs; Dallas Makerspace REM-jack thread; Fagear AVRTapeControl; Rod Elliott P247; Blokas Pisound docs; Michael Fidler VU-meter measurements; DigiKey TechForum (latching switches); RPi thermal testing + Jeff Geerling case roundup.

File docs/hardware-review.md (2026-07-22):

# GuitarDAWLiteOS — Hardware Review & Wiring

> ⚠️ **Clock pivot (2026-07-10) — parts of this doc are rev-A (Pi-as-master) and were superseded.**
> The as-built bench runs the **PCM1808 as I²S bus master** (MD0=MD1=**HIGH/3.3 V**, 256 fs) driving
> BCK/LRCK, with the **Pi 5 as I²S slave** (`GDAW_I2S_SLAVE`, RP1 I2S1). Wherever this file still says
> *Pi I²S0 master*, *MD0/MD1 → GND / slave mode*, or *BCLK/LRCLK sourced from Pi GPIO18/19*, that is the
> **old topology** — the strap table and clock-direction columns below have been corrected inline, but the
> analog/power/front-end rationale (the reason this doc exists) is unaffected and still current.
> **Wire from [adc-hookup.md](adc-hookup.md) + the as-built SVG sheets; strapping MD0/MD1 to GND with the
> current kernel gives a dual-slave dead bus (no BCK/LRCK, capture frozen at 0).**

**Date:** 2026-06-29 *(strap/clock-direction tables corrected 2026-07-21 for the pivot).* Every electrical value here is datasheet-verified (TI PCM1808 SLES177B, PCM5102A SLAS859C, RP1 Peripherals datasheet, RPi "Using the I²S peripherals" white paper RP-009699-WP-1, RPi 3-pin Debug Connector spec) and the two highest-risk decisions (power rails, front-end gain/bias) were independently re-checked. See also the wiring diagram (rendered in chat / `docs/wiring-diagram.svg`).

## Headline findings
1. **The research doc had no analog front-end. You cannot wire a guitar straight to the ADC.** A passive pickup is ~hundreds of kΩ at its resonant peak and only ~0.1–0.7 Vpp; the PCM1808 input is 60 kΩ and wants ~3 Vpp on a 2.5 V bias. Direct connection = ~14 dB of tone-sucking loading **and** far too quiet. A buffer + gain stage is mandatory (designed below).
2. **PCM1808 analog VCC must be 5 V** (ROC min 4.5 V) — it *cannot* run all-3.3 V. Digital VDD = 3.3 V. Two rails.
3. **No level shifters needed** between PCM1808 (VDD=3.3 V) and Pi 5 3.3 V GPIO, either direction.
4. **Front-end op-amp runs on the 5 V rail**, not 3.3 V — its output must swing up to 4.0 V.
5. **Corrected front-end nominal gain = ×3 (+9.5 dB)**, not ×4 — ×4 clips a hot-humbucker transient.
6. **Don't power the analog side from header 3V3** (pins 1/17 are unspecified/shared/noisy). Take 5 V from header pin 2 and regulate locally.

---

## Bill of materials (Phase 1 audio board)
| Qty | Part | Role | Notes |
|----:|---|---|---|
| 1 | Raspberry Pi 5 | host | **I²S1 slave** (post-pivot), 3.3 V GPIO |
| 1 | PCM1808 (14-pin SSOP) **or** GY-PCM1808 breakout | stereo ADC (capture) | strap-only, **bus master** (256 fs) |
| 1 | GY-PCM5102 (PCM5102A) breakout | stereo DAC (playback) | strap-only, internal PLL |
| 1 | Dual op-amp, RRIO-ish, low-noise, 5 V | guitar front-end | **OPA1662** (best audio) or **OPA2353/OPA2350** (guaranteed single-5 V RRIO) |
| 1 | ¼" mono jack | guitar input | switched/unswitched |
| 1 | 3.5 mm jack or L/R/G pads | line output | on GY-PCM5102 already |
| 0–1 | *(optional)* 3.3 V LDO (MCP1700/LP5907) | clean-VDD upgrade | default = VDD from header 3V3 |
| 1 | Ferrite bead + RC | clean analog 5 V | for PCM1808 VCC + op-amp |
| — | Decoupling: 0.1 µF + 10 µF sets; 1 µF film coupling caps; 1 MΩ/10 kΩ/trimpot; 1 kΩ + 1 nF AA | passives | values below |

Currents are tiny: PCM1808 ≈ 9 mA (analog) + 6 mA (digital); op-amp ≈ 10 mA; PCM5102A ≈ 25 mA. The Pi's 5 V/5 A supply has ample headroom.

---

## Power tree (verified)
```
Header 5V (J8 pin 2) ──┬─► [ferrite + 10µF+0.1µF] ─► ANALOG 5V rail ─┬─► PCM1808 VCC (pin3, analog)
                       │                                            └─► Op-amp V+ (front-end)
                       ├─► PCM5102A module VIN (its onboard LDO → 3.3V)
Header 3V3 (J8 pin 1) ───► PCM1808 VDD (pin4) + U3 XSMT strap   [default; optional local LDO off 5V = extra-clean digital rail]
Header GND (J8 pin 6/9/…) ─► single-point star ground (AGND≡DGND under each chip)
```
- **Why a 5 V analog rail:** PCM1808 ROC = VCC 4.5/5/5.5 V. Full-scale (3 Vpp) and VREF (2.5 V) are *ratiometric to VCC*, so use a clean, stable 5 V (ferrite + bulk + 0.1 µF) — VCC ripple becomes gain error/noise.
- **Why not header 3V3 for analog:** Pi 5 docs publish **no** 3V3 header current spec; it's leftover from the Pi's own regulator and electrically noisy — bad for audio SNR, so the **analog 5 V rail never comes from it.** Digital VDD is different: ~6 mA, and its noise doesn't reach the audio path (VCC is the SNR-critical rail), so by default **VDD runs from header 3V3 pin 1 directly**; a local 3.3 V LDO off 5 V is an optional clean-rail upgrade.
- **Op-amp on 5 V:** the front-end output must reach 1.0–4.0 V (full-scale window). A 3.3 V rail tops out below 4.0 V → it would clip. Run the op-amp from the analog 5 V rail.

---

## Connection / netlist table
Pi physical pins are J8 (40-pin header, identical layout to Pi 4). PCM1808 pins are the 14-SSOP numbers.

### Clocks & data (RP1 **I2S1**, slave; ALT function **a4** — *post-pivot*)
**MCLK is no longer a Pi 5 GPIO signal** — see [claim-verification.md](claim-verification.md) ("Update 2026-07-09"): the Pi 5 has no on-chip path to a `pll_audio`-locked clock on any GPIO while its I²S peripheral is running BCLK. MCLK comes from a separate **Arduino Nano ESP32** board — see [../esp32-mclk/](../esp32-mclk/) — wired to the PCM1808's SCKI, with no Pi 5 GPIO involved. Bench-verified at 12.2880 MHz via the board's own PCNT self-test. **Post-pivot the PCM1808 (bus master) divides SCKI into BCK/LRCK and drives them; the Pi and DAC receive.**

| Signal | Source (drives) | → to (receives) |
|---|---|---|
| **MCLK** 12.288 MHz | Nano ESP32 **D2 / GPIO5** | PCM1808 **SCKI (pin 6)** *only* (PCM5102A self-clocks) |
| **BCLK** 3.072 MHz | **PCM1808 BCK (pin 8)** | → Pi GPIO18 (pin **12**) + PCM5102A **BCK** |
| **LRCLK/WS** 48 kHz | **PCM1808 LRCK (pin 7)** | → Pi GPIO19 (pin **35**) + PCM5102A **LCK** |
| **Capture data** | PCM1808 **DOUT (pin 9)** | → Pi GPIO20 (pin **38**) |
| **Playback data** | Pi GPIO21 (pin **40**) | → PCM5102A **DIN** |

Nano ESP32 and Pi 5 share a common ground (tie Nano ESP32 GND to the breadboard/Pi ground rail); the Nano ESP32 can be powered independently via its own USB.

### Power & ground
| Rail | Pi pin | → to |
|---|---:|---|
| 5 V | **2** | analog-5V (PCM1808 VCC pin 3 via ferrite, op-amp V+), PCM5102A VIN |
| 3.3 V (header pin 1; LDO optional) | 1 | PCM1808 VDD (pin 4) |
| GND | **6**, 9, 14, 20, 25, 30, 34, 39 | common star ground |

### PCM1808 strapping (set before power-on; internal 50 kΩ pulldowns) — *post-pivot: MASTER*
| Pin | Strap | Selects |
|-----|---|---|
| MD0 (10) | → **+3.3 V** | **master mode** (with MD1) |
| MD1 (11) | → **+3.3 V** | **master, 256 fs** → divides 12.288 MHz SCKI into 3.072 MHz BCK + 48 kHz LRCK |
| FMT (12) | → GND | **I²S, 24-bit** |

> The rev-A build strapped MD0/MD1 → GND (slave). Post-pivot that is **wrong**: with the Pi also slave
> (`GDAW_I2S_SLAVE`) nobody would drive the bus. Both mode pins go to **3.3 V**.

### PCM5102A (GY-PCM5102) config
| Item | Set | Why |
|---|-----|-----|
| SCK | → **GND** | enable internal PLL off BCK (no MCLK); needs BCK = 32fs/64fs — Circle gives 64fs (3.072 MHz @ 48k) ✓ |
| FLT pad (H1L) | **L** | normal-latency filter |
| DEMP pad (H2L) | **L** | de-emphasis off |
| **XSMT pad (H3L)** | **H** | **UNMUTE** — ships LOW = silent; #1 gotcha |
| FMT pad (H4L) | **L** | I²S |

### Decoupling (place at the pins)
- PCM1808: **VCC, VDD, VREF each → 0.1 µF + 10 µF**. VREF (pin 1) → AGND. Do **not** drive VREF.
- PCM5102A (module already populates): AVDD/CPVDD/3.3V → 0.1 µF + 10 µF; charge-pump flying caps 2.2 µF; output RC **470 Ω + 2.2 nF** per channel.
- AGND ≡ DGND tied directly under each chip; single return to a Pi GND pin physically near the I²S pins.

---

## Guitar analog front-end (the missing piece)
Mono guitar → **VINL** only. Single 5 V supply, everything biased to an independent **VBIAS = 2.5 V** mid-rail (its own 10k/10k divider + cap — **not** the ADC's VREF pin, which is decouple-only). VBIAS and the ADC's internal 2.5 V are equal, so the AC-coupled handoff to VINL is seamless.

```
 ¼" tip ─┤(Cin 0.1µF)├─┬─────────────[+]\
                       │              op-amp A ── buffer out ──┤(Rg 10k)├──[-]\
                    [R 1MΩ to VBIAS]  (×1, Zin≈1MΩ)                           op-amp B ──┬─┤(Cout 1µF)├─[Rs 1k]─┬─► VINL (pin13)
                       │                                       VREF─[-]ref   (×3 nom)   │                     │
                      VBIAS(2.5V)                              Rf=10k+100k trimpot (×2..×12)              [Ca 1nF to AGND]
 VINR (pin14) ─┤(1µF)├─ AGND   (AC-ground unused R channel; keep its internal 2.5V bias)
```

**Stage roles & values (verified):**
1. **High-Z buffer** — AC-couple the jack (`Cin` 0.1 µF) into a **1 MΩ bias resistor to VBIAS**, then a unity-gain op-amp. The 1 MΩ (not the ADC's 60 kΩ) is what the pickup sees → mimics a guitar amp, preserves the resonant-peak treble. HPF = 1/(2π·1 M·0.1 µF) ≈ **1.6 Hz** (well below low-E 82 Hz).
2. **Trimmable gain** — non-inverting, referenced to VBIAS. `Av = 1 + Rf/Rg`, `Rg = 10 kΩ` fixed, `Rf = 10 kΩ + 100 kΩ trimpot (RV1)` → **×2…×12 (+6…+21.6 dB)**. **Default ×3 (+9.5 dB).**
3. **AC-couple to ADC** — `Cout` 1 µF into VINL (which self-biases to 2.5 V). HPF ≈ 2.7 Hz into 60 kΩ.
4. **Gentle anti-alias** — `Rs` 1 kΩ + `Ca` 1 nF at VINL → fc ≈ 159 kHz (the ΔΣ + on-chip 1.3 MHz AA does the real work; this is just RF cleanup). Keep Rs ≪ 60 kΩ.

**Headroom (×3, output centered at 2.5 V, FS window 1.0–4.0 V):**
| Source | level | at ×3 | % FS |
|---|---:|---:|-----:|
| Single-coil normal | ~0.2 Vpp | 0.6 Vpp | 20% |
| Single-coil hard | ~0.4 Vpp | 1.2 Vpp | 40% |
| Humbucker hard | ~0.7 Vpp | 2.1 Vpp | 70% |
| Hot-HB transient | ~1.0 Vpp | 3.0 Vpp | **100% (exactly FS — no clip)** |

→ Default ×3 is clean even for hot humbuckers; trim **up** for quiet single-coils, **down** if a clip LED triggers. (×4 would put the hot-HB transient at 4 Vpp = 33% over FS → clipping. That's the corrected item.)

**Op-amp:** dual, **5 V single supply**, output must reach within ~1 V of each rail at the load. **OPA1662** (low-noise audio) preferred; **OPA2353/OPA2350** if you want guaranteed input+output rail-to-rail on a single 5 V. Avoid NE5532/TL07x here (won't swing to 1 V on a single 5 V rail).

---

## Level & compatibility summary
- All I²S links are 3.3 V ↔ 3.3 V, either direction (post-pivot the ADC drives BCK/LRCK into the Pi; the Pi drives only DIN→DAC). Pi VOH/PCM1808 outputs all sit at ~3.3 V ≫ the 2 V VIH min. ✓ No level shifters. (SCKI/MD/FMT are 5 V-tolerant; the PCM1808's clock pins are *not*, but nothing here exceeds 3.3 V.)
- PCM1808 DOUT (VOH ≥ 2.8 V) → Pi GPIO (reads >2.0 V high). ✓
- RP1 GPIO is **3.3 V CMOS, not 5 V tolerant** — never feed a 5 V logic signal back into GPIO20. Default drive 4 mA is fine for short traces; bump to 8–12 mA for longer runs / fan-out.

## Risk / gotcha register
| Item | Severity | Mitigation |
|---|---|---|
| Wiring guitar straight to VINL | **High** | front-end buffer+gain (above) — never direct |
| PCM5102A XSMT pad = mute | High | bridge **H3L = HIGH** |
| PCM1808 analog on 3.3 V | High | analog VCC = **5 V**, clean |
| Front-end op-amp on 3.3 V | High | op-amp on **5 V** rail (needs 4.0 V swing) |
| Fixed/high front-end gain clips | Med | **×3 default**, trim + clip LED |
| Header 3V3 for analog | Med | 5 V + local LDO; star ground |
| 5 V on BCK/LRCK/DOUT | Med | never — all from 3.3 V Pi |
| MD/FMT/SCK set after power-on | Low | strap before power-on |

## Sources
TI PCM1808 SLES177B (Pin Functions, §6.1/6.3/6.5, §8.2 Fig 26, §9, §10 Fig 27); TI PCM5102A SLAS859C (Pin Functions, §9.3.5 BCK-PLL, Table 11, output 2.1 Vrms, Fig 33); RP1 Peripherals datasheet §3.1/§3.1.1 Table 4 (I²S0=a2, GPCLK0=a0), §3.1.3 pads; RPi white paper RP-009699-WP-1 Table 3/5; RPi 3-pin Debug Connector spec RP-003139-SP; GY-PCM5102 pad map (mt32-pi wiki, arduino-audio-tools #773, makerguides). Plus this project's [claim-verification.md](claim-verification.md) for the digital-side facts (MCLK, strapping, pin map).

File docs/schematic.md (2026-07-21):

# GuitarDAWLiteOS — Schematic, Netlist & BOM (Phase 1 audio board)

**Date:** 2026-06-29. Buildable schematic for the Pi 5 + PCM1808 (capture, with guitar front-end) + PCM5102A (playback) board. All pins/values are datasheet-verified; the analog front-end is **SPICE-verified** (ngspice, deck in [sim/frontend.cir](sim/frontend.cir), results in [sim/frontend-results.txt](sim/frontend-results.txt)).

> ⚠️ **Clock pivot (2026-07-10):** the netlist below is the **rev-A, Pi-as-master** design and predates the pivot. The as-built bench runs the **PCM1808 as I²S bus master** (MD0=MD1=HIGH, 256 fs) with the **Pi 5 as slave** — straps, BCK/LRCK directions, and the Pi's I²S instance in this doc are stale until rev B is redrawn. Wire from **[adc-hookup.md](adc-hookup.md)**, [wiring-diagram.svg](wiring-diagram.svg), and the as-built sheets below instead.

**Sheets**
- **Front-end (canonical 5 V)** — [frontend-schematic.svg](frontend-schematic.svg): guitar ¼″ → buffer → ×3 gain → AA → VINL, with the VBIAS mid-rail.
- **Front-end (as-built bench, 9 V TL072)** — [tl072-frontend-schematic.svg](tl072-frontend-schematic.svg): drawer-parts variant per [tl072-frontend.md](tl072-frontend.md).
- **Codec & clocks (as-built bench)** — [codec-power-schematic.svg](codec-power-schematic.svg): **redrawn 2026-07-21 to the post-pivot topology** — Nano ESP32 MCLK → CJMCU-1808 master → Pi 5 slave + GY-PCM5102, per-pin with drive directions.
- Supersedes nothing; complements [hardware-review.md](hardware-review.md) (rationale) and [wiring-diagram.svg](wiring-diagram.svg) (overview).

---

## Bill of materials (reference designators)
| Ref | Value / Part | Notes |
|-----|---|---|
| U1 | **OPA1662** (audio) or **OPA2353** (RRIO) dual op-amp, SOIC-8 | front-end; single +5 V |
| U2 | **PCM1808** ADC, SSOP-14 (or GY-PCM1808 breakout) | capture, slave/strap-only |
| U3 | **GY-PCM5102** (PCM5102A) breakout | playback, internal PLL |
| J1 | ¼″ mono jack | guitar in |
| J2 | 3.5 mm jack / 3-pin terminal | line out (on U3 module) |
| RV1 | 100 kΩ trimpot | front-end gain trim |
| R1, R2 | 10 kΩ | VBIAS divider |
| Rbias | 1 MΩ | input bias / Z-in |
| Rg | 10 kΩ | gain set (to VBIAS) |
| Rf | 10 kΩ fixed (+ RV1) | feedback; ≈20 kΩ at ×3 nominal |
| Rs | 1 kΩ | anti-alias series |
| FB1 | ferrite bead (e.g. 600 Ω @100 MHz) | +5 V → U2 VCC |
| Cin | 0.1 µF film | input AC-couple |
| Cout, Cr | 1 µF film | output AC-couple / VINR AC-gnd |
| Ca | 1 nF C0G | anti-alias shunt |
| C1 | 10 µF | VBIAS reservoir |
| C2,C4,C6 | 0.1 µF ceramic | U2 VCC/VDD/VREF bypass |
| C3,C5,C7 | 10 µF | U2 VCC/VDD/VREF bulk |
| C8 | 0.1 µF ceramic | U1 op-amp V+ local bypass (to GND) |

U3 (GY-PCM5102) is self-decoupled and carries its own output RC (470 Ω + 2.2 nF/ch) and LDO.

---

## Netlist (by net)
**Power**
- `+5V` — Pi J8 **pin 2**; U1 V+ (pin 8, + local **C8** 0.1 µF→GND); U3 VIN; **FB1**→U2 VCC (pin 3).
- `+3V3` — Pi J8 **pin 1**; U2 VDD (pin 4); U3 **XSMT pad → H**.
- `GND` — Pi J8 **pin 6** (star); U1 V− (pin 4); U2 AGND(2), DGND(5), MD0(10), MD1(11), FMT(12); U3 GND, SCK, FLT/DEMP/FMT pads; J1 sleeve; all decoupling/bias returns. **AGND ≡ DGND**, single star to one Pi GND.

**I²S0 (RP1 ALT a2; BCLK/LRCLK/data from Pi master)**
- `MCLK` — ⚠️ **no longer from the Pi header.** `GPCLK0`/GPIO4 was ruled out 2026-07-09 (`clk_i2s` is already claimed by BCLK the whole time I²S runs — see [claim-verification.md](claim-verification.md)). MCLK now comes from an **Arduino Nano ESP32** (D2/GPIO5, [esp32-mclk/](../esp32-mclk/), bench-verified at 12.2880 MHz) → U2 **SCKI (6)**. *ADC only. Not SPICE/ERC-reviewed with this source yet — the analog front-end and power/ground nets below are unaffected, but the MCLK net in the KiCad project ([kicad/gen.py](../kicad/gen.py)) still shows the old Pi-header connection and needs updating before fab.*
- `BCLK` — Pi **p12/GPIO18** → U2 **BCK (8)** + U3 **BCK**.
- `LRCLK` — Pi **p35/GPIO19** → U2 **LRCK (7)** + U3 **LCK**.
- `CAPDAT` — U2 **DOUT (9)** → Pi **p38/GPIO20**.
- `PLAYDAT` — Pi **p40/GPIO21** → U3 **DIN**.

**Strapping (no nets — tie at the pin)**
- U2: MD0=MD1=FMT → GND (slave, I²S 24-bit). U2 SCKI driven by MCLK.
- U3 pads: FLT=L, DEMP=L, FMT=L, **XSMT=H (+3V3)**; SCK→GND (internal PLL off 64fs BCLK).

**Analog front-end (sheet 1)**
- `VBIAS` (2.5 V) — R1(+5V)–node–R2(GND); C1 node→GND; Rbias top; Rg bottom. *Independent of U2 VREF.*
- J1 tip → Cin → node nbi (Rbias→VBIAS) → U1A `+`; U1A out → U1A `−` (buffer) and → U1B `+`.
- U1B `−` = ninv: Rg→VBIAS, Rf→U1B out (`feo`).
- feo → Cout → Rs → node `VINL`; Ca: VINL→GND. `VINL` → U2 **VINL (13)**.
- U2 **VINR (14)** → Cr → GND (AC-ground unused channel).
- U2 **VREF (1)** → C6‖C7 → AGND (decouple only — do **not** drive/load).

**Output**
- U3 OUTL/OUTR/GND → J2 (line out, 2.1 Vrms, ground-centered).

---

## Front-end SPICE verification (ngspice)
Deck: [sim/frontend.cir](sim/frontend.cir). Reproduce: `ngspice -b docs/sim/frontend.cir`.

| Measurement | Result | Expected | ✓ |
|---|---|---|---|
| DC bias (vbias, buffer, gain, VINL) | 2.500 V | 2.5 V mid-rail | ✓ |
| Gain @ 1 kHz | **9.54 dB (×3.00)** | ×3 | ✓ |
| Flatness (100 Hz / 20 kHz) | 9.535 / 9.542 dB | flat | ✓ |
| Low −3 dB corner | **2.6 Hz** | ≪ 82 Hz (low-E) | ✓ |
| Hot-HB 1 Vpp transient | feo **0.997–3.997 V** | 1.0–4.0 V, no clip | ✓ |
| Overdrive 1.6 Vpp | clips 0.09 / 4.89 V | rails (validates trim) | ✓ |
| Real op-amp (0.6 V rail margin = OPA1662) | feo 0.996–3.997 V | still no clip | ✓ |

Re-running with `ngspice -b --define VMARGIN=0.6 docs/sim/frontend.cir` models OPA1662's worst-case 0.6–4.4 V swing — the transient is unchanged (0.996–3.997 V), so a real **non-RRIO** audio op-amp suffices (RRIO/OPA2353 is optional). High-frequency rolloff is the passive AA at fc = 1/(2π·1 kΩ·1 nF) ≈ **159 kHz** (the ideal-clamp sim op-amp is flat past 2 MHz, as expected).

---

## Build / assembly order (breadboard or perfboard)
1. **Power & ground first.** Bring in +5 V (Pi p2) and +3V3 (Pi p1); set the single star ground. Add FB1 + C2/C3 to U2 VCC.
2. **DAC playback path** (fastest win): wire U3 (VIN, GND, BCK, LCK, DIN, SCK→GND), set pads **L,L,H,L** (XSMT=H!). Test with Circle `sample/34-sounddevices`.
3. **MCLK (Spike B) — done:** Nano ESP32 D2/GPIO5 = 12.288 MHz → U2 SCKI. Runs independently of the Pi 5's `pll_audio`/BCLK — the PCM1808 only needs fs-sync, not phase-lock (`[CORR-4]`/E2). Frequency bench-verified at 12.2880 MHz (chip's own PCNT self-test, no scope available); remove the self-test jumper before wiring to U2.
4. **ADC capture path**: strap U2 (MD0/MD1/FMT→GND), wire SCKI/BCK/LRCK/DOUT, VCC/VDD/VREF + decoupling. Temporarily feed VINL a line signal to confirm capture (Circle `sample/42-soundinput`).
5. **Front-end last**: build VBIAS (R1/R2/C1), then U1A buffer, U1B gain (Rg, Rf+RV1), Cout/Rs/Ca → VINL; Cr on VINR. Set RV1 to ×3 and check on a level meter (hard strum ≈ −1…−3 dBFS).

## ERC self-check
- Every IC power pin has a net and local decoupling. ✓
- No output drives another output; U2 DOUT is the only driver of `CAPDAT`. ✓
- U2 BCK/LRCK are 3.3 V-domain (VDD) and only ever driven by the 3.3 V Pi (never 5 V). ✓
- VREF is decouple-only (not driven); front-end uses its own VBIAS. ✓
- All strap pins tied (no floating MD0/MD1/FMT or XSMT). ✓

*Adversarial ERC review (3 independent reviewers, 2026-06-29): **no blockers or majors.** I²S connectivity clean; power/ground and front-end minor-only. Applied: VDD from header 3V3 direct (LDO now optional), U1 bypass **C8** added, gain trim ×2…×12, MCLK/BCLK coherence noted. Hard build rule confirmed: U3 must be the GY-PCM5102 **module** (onboard LDO) on the 5 V VIN — never a bare PCM5102A, and never strap XSMT to 5 V.*

## Open option
Front-end is **mono guitar → VINL**; VINR is AC-grounded. To add a **line/aux or second input** (mic, stereo pedal → VINR), duplicate the front-end (or a simpler unity buffer) into VINR and read both I²S channels — ask and I'll extend both sheets.

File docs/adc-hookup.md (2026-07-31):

# ADC capture hookup — Pi 5 + PCM1808 breakout + Nano ESP32 (bench card)

> 🔒 **For the permanent soldered board, [solder-build.md](solder-build.md) overrides this card.**
> This file is the *solderless bench* procedure. Three things differ on the permanent build:
> the analog-5 V RC is **unconditional** (the "before adding parts, measure" gate below is
> unrunnable — the silence FFT needs a working capture path); the 5 V rail **splits**, with the
> DAC tapped upstream of the 10 Ω; and the Nano's **D2→D3 link stays** as a permanent MCLK health
> readout instead of being removed. Straps, pin map and clock topology below are unchanged and correct.

Every wire for the Milestone-2 **capture** side, written for the exact board
on hand: the **purple "CJMCU-1808" PCM1808 breakout** (Rakstore/HiLetgo,
~25×32 mm, four 10 µF electrolytics, two 6-pin headers, no input jack).
Board facts verified against the TI datasheet (SLES177B), the WLED
MoonModules line-in guide, and multiple project writeups (2026-07-10) —
no public schematic of this module exists, so anything single-source is
flagged. The DAC/playback side is in [breadboard-build.md](breadboard-build.md).

## ⚡ Clock topology (changed 2026-07-10 — read first)

**The PCM1808 is the I²S bus master, not the Pi.** It divides the Nano
ESP32's 12.288 MHz into BCK + LRCK itself and *drives* them; the Pi's I²S
runs as slave (already flipped in the kernel — `GDAW_I2S_SLAVE` in
[src/config.h](../src/config.h)). Why: in slave mode the PCM1808 demands
SCKI frequency-locked to LRCK — two free-running crystals (Nano vs Pi)
drift tens of ppm apart, and the chip's resync logic (datasheet §7.4.2)
would mute-and-fade the audio every fraction of a second. An RPi engineer
on the forums called the async arrangement a non-starter; ADC-as-master is
the community-standard fix. One clock domain, rooted in the Nano's crystal.
(The PCM5102A doesn't care — its PLL locks off whatever drives BCK.)

## The module's pins, mapped

| Silkscreen | Chip pin | Role in this build |
|---|---|---|
| **FMT** | 12 | → **GND** (I²S format) |
| **MD1** | 11 | → **3.3 V rail** (master mode…) |
| **MD0** | 10 | → **3.3 V rail** (…at 256 fs: 12.288 MHz ÷ 256 = 48 kHz) |
| **GND** (left) | AGND/DGND | → star ground |
| **3.3** | 4 (VDD) | ← **3.3 V INPUT** — there is **no onboard regulator**; both rails are required |
| **+5V** | 3 (VCC) | ← **5 V INPUT** (analog rail — genuinely needs 5 V; 3.3 V here causes random glitches) |
| **BCK** | 8 | → Pi **J8 pin 12** (GPIO18) — **ADC drives it** (3.072 MHz) |
| **OUT** | 9 (DOUT) | → Pi **J8 pin 38** (GPIO20) — capture data |
| **LRC** | 7 (LRCK) | → Pi **J8 pin 35** (GPIO19) — **ADC drives it** (48 kHz) |
| **SCK** | 6 (SCKI) | ← **Nano ESP32 D2** (12.288 MHz MCLK) |
| **GND** (right) | AGND/DGND | second ground pin — on the **soldered** build use it as the origin of the return conductor bundled with BCK/LRC/OUT ([solder-build.md](solder-build.md) §3); on a solderless bench one pin is enough |
| **3.3V** (right) | 4 (VDD) | duplicate of "3.3" |

⚠️ **Never feed 5 V into the 3.3/3.3V pins** — chip VDD absolute max is 4 V;
5 V risks permanent damage.

**Analog input:** the three plated holes on the board edge (between the
header rows), order **RIN / – / LIN** (right in, audio ground, left in) —
from a reverse-engineered footprint, single source, so **sanity-check
against your board's markings**. Inputs are AC-coupled on-board (two of the
electrolytics) and the chip self-biases them — feed line-level directly to
the pads:

| Pad | Connect to |
|---|---|
| **LIN** | the TL072 front-end output ([tl072-frontend.md](tl072-frontend.md)) via the CopperSound board's output jack. Keep **Rs 1 k + Ca 1 nF** at this pad. For a smoke test: any line-level source. |
| **–** | star ground (this is the input's reference) |
| **RIN** | leave unconnected for now (on-board cap AC-terminates it; rev-B tape return lands here) |

## Power & ground

**Two configurations. The bench runs A today; B is the target.**

**A — BENCH (current, three supplies):**

| Device | Powered by |
|---|---|
| Pi 5 | official 45 W USB-C PD |
| Nano ESP32 | **preferred:** Gator 9 V → **VIN** (in spec: VIN wants 6–21 V) · *fallback:* its own USB-C. **Never 5 V into VIN.** |
| PCM1808 module | **+5V** ← Pi J8 **pin 2** and **3.3** ← Pi J8 **pin 1** — both required |
| TL072 front-end | Gator 9 V → CopperSound DC jack (separate domain, shared ground) |

**B — TARGET (single 18 V pack):** see [power-tree-18v.md](power-tree-18v.md).
Only the *upstream* source differs; the codec rails below are identical in both.

> **Taking the Nano off USB.** The Gator already supplies 9 V on the bench, and
> the Nano's VIN window is 6–21 V, so tapping it for VIN frees the USB slot *and*
> rehearses the target topology (where VIN comes off the 7809 rail). Two
> consequences to plan for:
> 1. **You lose the 1 Hz MCLK health print**, which goes out over the Nano's USB
>    serial. That print is currently the only continuous proof the clock domain is
>    alive — see `esp32-mclk/esp32-mclk.ino`. Replace it with the Pi-side check in
>    [boot-selfcheck.md](boot-selfcheck.md) before unplugging.
> 2. **The Nano now shares the analog 9 V supply with the TL072.** Keep them as
>    separate spokes, rely on the `C_byp` 100 µF ∥ 0.1 µF at U1 pin 8, and disable
>    the ESP32's WiFi/BT radio — this board is a dedicated clock generator and the
>    radio buys nothing but current spikes on an audio rail.
>
> ⚠ **The three-supply bench inherits two rules that config B removes**: the
> power-up ordering in [Order of operations](#order-of-operations) below, and the
> load-bearing star-ground jumper — with independent supplies, a dropped ground
> jumper routes MCLK return plus inter-supply Y-cap leakage through the PCM1808's
> SCKI input clamp. Both matter **now**.

Star ground = Pi J8 **pin 6**: module GND, Nano GND, CopperSound GND rail,
input **–** pad — one **DC** point, no DC ground loops.

> **⚠ Analog-5V filter was dropped from this card — restore it (M2 review A1).** The
> PCM1808's full-scale is *ratiometric* (FS = 0.6·VCC, VREF = 0.5·VCC), so ripple on
> the +5 V pin multiplies onto every sample (Science: 50 mVpp/5 V ≈ −52 dBc sidebands;
> the chip's own floor is ~12 µVrms, so even faint in-band rail coupling can exceed it).
> The original power tree specified a **ferrite + 10 µF + 0.1 µF** at the VCC pin; it
> never made it onto the as-built sheets. **Before adding parts, measure:** record
> silence and FFT it — if the Pi rail is already quiet in-band, you're done. If not, a
> **ferrite alone is ≈0 dB in-band** (Science) — use an **RC (≈10 Ω + 470 µF ∥ 0.1 µF)**
> on the +5 V pin (≈90 mV drop at ~9 mA, still ≥ 4.5 V VCC min).

> **HF clock returns (M2 review A3) — a DC star is right for audio, wrong for MHz clocks.**
> "One point" is a *DC* rule. The 12.288 MHz MCLK (Nano D2→SCK) and the 3.072 MHz
> BCK/LRC/OUT wires want their return current running *beside* them, which the lone star
> spoke doesn't provide. Best practice, and it does **not** break the DC star: run a
> **dedicated ground wire paired/twisted with the MCLK line** (Nano→ADC) and another with
> the BCK/LRC/OUT bundle, each still landing at pin 6 — a paired HF return is *not* a
> forbidden "ground island." Add **~33 Ω series at the Nano D2 pin** (tames edge ringing
> and doubles as the fault-current limit if a ground jumper drops — review B2). Give the
> **Nano two ground wires** so a single dropped jumper never routes clock return through
> the SCK clamp. *(Science: the audio-band residue of this bounce is small — MHz energy
> folds out of band — so these are robustness/EMI hygiene, not a measured-noise fix.)*

## Order of operations

1. Wire everything **unpowered**. Straps: FMT→GND, **MD0 and MD1→3.3 V rail**
   (TI requires mode pins set before power-on). Double-check no 5 V touches
   a 3.3 pin — **and verify it**: with the module's two power leads *not yet
   landed*, bring the supplies up and meter the two rail rows (expect 5.0 V and
   3.3 V), then power down again and connect the module. J8 pins 1 (3.3 V) and 2 (5 V) are
   physically adjacent, so a one-row slip puts 5 V on the 4 V-abs-max VDD pin.
2. **Leave the D2→D3 link in place** — the frozen M2 wiring keeps it as a
   permanent MCLK health readout, tapped *before* the 33 Ω (see the banner at
   the top of this file). *(This step previously said to remove it; that
   predates the freeze.)*
3. **Config A (bench, three supplies) — order matters.** Power the **Nano
   first** (D2 carries 12.288 MHz), then the **Pi**, then the **Gator 9 V**.
   **Power down in reverse** (Gator, Pi, Nano). *(Nano-first is verified safe —
   review B1: the PCM1808's SCK/MD/FMT inputs are rated −0.3…+6.5 V independent
   of VDD, so 3.3 V into an unpowered ADC injects no fault current.)* Before
   touching any wire later, **kill all three supplies first.**
   *(Config B collapses this to one master switch —
   [power-tree-18v.md](power-tree-18v.md).)*
4. Boot log: `I2S full duplex (TXRX, slave - ADC masters the bus): RUNNING`.
   **`cap`/`play` only start counting once the ADC is wired, powered, and
   clocked** — a bare-board boot correctly shows 0s now (unlike the old
   master-mode kernel).
5. Feed LIN a signal → `peak %` comes alive. `starve`/`drop`/`laps` stay 0.

## Debug ladder (capture dead?)

> **Power down all three supplies before reseating any wire or strap.** This ladder
> sends your hands to live rows; a strap jumper slipping from the 3.3 V row into the
> adjacent 5 V row is the exact way the ADC's 4 V-abs-max VDD pin dies.

1. `cap` frozen at 0 → no bus clocks: check SCKI wire (Nano D2), Nano power,
   then MD0/MD1 straps (both must be HIGH or the ADC never masters the bus).
2. `cap` counting but `peak 0%` → clocks fine, no signal: check LIN wiring,
   front-end power, input **–** pad grounded.
3. Interrupting SCKI even briefly auto-powers-down the chip; on resume DOUT
   stays zero for ~1024 SCKI + 8960/fs and then **fades in** over ~1 ms —
   a beat of silence after clock glitches is the chip, not your wiring.
4. Quality caveat from the field: some batches of these modules shipped with
   wrong solder jumpers — if all else fails, inspect the board against the
   pin table above.

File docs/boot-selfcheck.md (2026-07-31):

# Boot landing + clock-domain self-check

**Status: proposal (2026-07-28).** Nothing here is implemented yet.

## The problem it solves

Today `CKernel::Run()` starts the audio engine and reports:

```
I2S full duplex (TXRX, slave - ADC masters the bus): RUNNING
slave mode: cap/play stay 0 until the PCM1808 is wired, powered and fed MCLK - that is expected
```

`RUNNING` here means *the Pi's own I2S peripheral configured itself successfully*
— nothing more. Because the Pi is now the **slave**, that message is printed
identically whether the rest of the rig is perfect or entirely absent. A dead
Nano, an unplugged SCKI wire, an unpowered ADC, a mis-strapped MD0/MD1, and a
correct-but-idle board all produce the same log line and the same `cap/play = 0`.

The one thing that currently distinguishes them is the Nano's 1 Hz PCNT print
over **USB serial** (`esp32-mclk/esp32-mclk.ino`) — which disappears the moment
the Nano is powered from VIN instead of USB, as the bench is moving toward
(see [adc-hookup.md](adc-hookup.md)). Removing the USB cable removes the only
continuous evidence that the clock domain is alive.

So the self-check is not a nicety: it is what replaces that evidence.

## The key observation — no new wires needed

**The ADC masters BCK. BCK only toggles if SCKI is present.**

That makes GPIO18 (J8 p12) an end-to-end health probe for the entire clock
chain — Nano MCLK → 33 Ω → SCKI → PCM1808 divider → BCK — using a pin the
design already owns. Before configuring the I2S peripheral, the landing phase
can claim GPIO18 as a plain input and sample it:

| GPIO18 | Meaning |
|---|---|
| toggling ~3.072 MHz | clock domain healthy — proceed to start I2S |
| static high/low | clock domain dead — Nano stopped, SCKI open, ADC unpowered, or MD0/MD1 strapped wrong |

Then, once I2S is running:

| BCK | frames | Diagnosis |
|---|---|---|
| toggling | counting | healthy |
| toggling | 0 | clock fine, **data path** broken — DOUT wire, DMA, or format |
| static | 0 | clock domain dead — do not blame the data path |

That split is the whole value. It converts "cap/play stay 0, that is expected"
into a specific, actionable diagnosis, and it costs zero hardware.

Sampling detail: at 3.072 MHz a poll loop will alias badly, so sample for a
fixed window (say 1 ms) and look for *any* edge, rather than trying to measure
frequency. Presence/absence is all that is needed — the Nano's own PCNT already
verifies the frequency at source.

## Phase 2 — the reset line (this is the "reboot command")

Detection alone tells you the clock is dead; it cannot fix it. One wire adds
recovery:

```
Pi GPIO ──► Nano ESP32 RST      (active low, pulse ~10 ms)
```

The landing sequence becomes:

1. Sample BCK. If alive → start I2S, done.
2. If dead, wait ~1 s (the Nano's Arduino boot is slower than the Pi's
   bare-metal boot — on a single master switch the Pi *will* usually win the
   race), re-sample.
3. Still dead → pulse Nano RST, wait for its boot, re-sample.
4. After N attempts → stop and display a specific fault on the landing screen
   rather than booting into a silently dead rig.

Step 2 matters more than it looks: **it removes the power-up ordering rule as a
correctness requirement.** The current "Nano first, then Pi, then Gator" exists
precisely because nothing downstream tolerates a late clock. A retry loop makes
the order a convenience rather than a constraint — which is exactly what the
single-master-switch 18 V target needs.

### GPIO cost — and the honest problem with it

`retro-deck-design.md` §4 allocates **all 28** J8 GPIOs. There is no free pin.
Three options, in order of preference:

1. **Borrow GPIO10 or 11** while the APA102/SK9822 bargraph is deferred
   (2026-07-28). Free today, but it collides with the standing rule to keep
   10/11 for SPI0, and would have to move when the strip returns.
2. **Put RST on the MCP23017 expander** (I²C1, GPIO2/3). Costs no J8 pin. The
   objection is bootstrap ordering — the expander must be up before the clock
   check can recover anything — but I²C is cheap to bring up early in bare
   metal, and this is a slow signal.
3. **Skip phase 2 entirely.** Phase 1 alone delivers the diagnosis; a human can
   press the Nano's reset button. Worth considering, since a wedged ESP32 has
   not actually been observed — the failure this guards against is
   hypothetical, while the *detection* it depends on is not.

**Recommendation: build phase 1 now, defer phase 2** until either a wedged Nano
is observed in practice or the expander lands. Phase 1 is free, has no GPIO
argument to settle, and is what restores the visibility lost when the Nano's USB
cable comes out.

## What "landing" should show

A boot screen that reports each check pass/fail before entering the audio loop:

| Check | Method | Failure means |
|---|---|---|
| Screen / serial | existing `m_bScreenOK` / `m_bSerialOK` | no console — already handled |
| **Clock domain** | BCK edge probe on GPIO18 | Nano, SCKI wire, ADC power, or MD straps |
| I2S peripheral | existing `m_AudioEngine.Start()` | Pi-side config fault |
| **Frames advancing** | `cap`/`play` counters non-zero after ~100 ms | data path: DOUT, DMA, format |
| Thermal | existing `CCPUThrottle` | cooling |

Failing checks should not necessarily halt — the existing design deliberately
lets the thermal loop run with dead audio — but they must be **stated**, not
inferred from a zero counter.

## Open questions

1. Does the Circle bare-metal GPIO API allow claiming GPIO18 as an input and
   then handing it to the I2S peripheral cleanly, or does the I2S driver need to
   own the pin mux for the whole run? This decides whether the probe can be a
   pre-flight step or has to be a one-shot at the very start.
2. Is a wedged-Nano failure mode real, or hypothetical? That decides phase 2.
3. If phase 2 goes ahead: borrow GPIO10/11, or expander?

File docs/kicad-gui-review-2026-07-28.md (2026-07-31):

# KiCad GUI review — 2026-07-28

Findings from opening the KiCad project for a visual review of the prototype
wiring. **Three problems, one of them electrical.**

## 1. There is no schematic

`kicad/guitardawliteos.kicad_sch` is **455 bytes**: a title block, an empty
`(lib_symbols)`, and nothing else. No symbols, no wires, no sheets.

```
(title "GuitarDAWLiteOS audio HAT")
(comment 2 "Draw the schematic by following docs/pcb-learning-path.md")
```

It is a deliberate placeholder for the learning exercise, not a drawing. So
there is no GUI schematic to review, and `gen.py` really is the only electrical
representation the project has — which is what
[pinmap-plan-revB.md](pinmap-plan-revB.md) concluded from the other direction.

## 2. RV1 is missing from the board — and it breaks the gain network

`gen.py` emits RV1 (100 k gain trimmer) correctly and it is present in
`guitardawliteos.net`. It is **absent from `guitardawliteos.kicad_pcb`**, so the
board carries 40 footprints against the netlist's 41. Consequences:

| Net | gen.py rev A | On the board |
|---|---|---|
| `FEO` | U1.7, RV1.2, RV1.3, Cout.1 | U1.7, Cout.1 — **RV1 gone** |
| `MIDF` | Rf.2, RV1.1 | Rf.2 only — **one-node net, Rf feeds nothing** |

`MIDF` reduced to a single node means the gain-setting rheostat leg is dangling:
the front-end's feedback network is incomplete on the board. This is not a
cosmetic staleness issue.

The netlist is right, so the loss happened at **import time in KiCad**, not in
`gen.py`. The likely cause is the `Potentiometer_THT:Trimmer_Bourns_3296W_Vertical`
footprint failing to resolve during "Import Netlist", which skips the component
silently.

**Nothing in the repo would have caught this.** `gen.py`'s `erc()` proves the
netlist is self-consistent and `validate.py` checks the `.net` — but neither
looks at the board. Added [`check_pcb.py`](../kicad/check_pcb.py) to close that
gap; it fails on exactly this today.

## 3. The board is an unrouted import, not a layout

0 track segments, 0 vias, no `Edge.Cuts` outline. The 40 footprints sit in the
default import grid, never arranged. What the GUI shows is a ratsnest over a
component pile — useful as a connectivity check, not as a layout.

PCB rev A as imported

## Rev A vs rev B on the board

The board is rev A and is **3 components and 6 nets** away from rev B
(`GDAW_REV=B`):

- missing `J4` (Nano MCLK header), `R_mclk` (33 Ω), and `RV1`
- still carries `U4`/`Cli`/`Clo` (the AP2112K LDO that rev B drops)
- `MD0`/`MD1` still on `GND` instead of `+3V3`
- `MCLK` still sourced from `J3.7` (Pi GPIO4), the route ruled out 2026-07-09

## Tooling note

The project files are **KiCad 10** (`generator_version "10.0"`); this container
only had KiCad 7 available, which refuses them outright
(`Unknown token 'generator_version'`). The KiCad PPA and `downloads.kicad.org`
are both blocked from this environment, so the review was done with two
purpose-built stdlib scripts rather than the GUI:

- [`render_pcb.py`](../kicad/render_pcb.py) — parses the board and draws
  footprints, pads and the ratsnest to SVG
- [`check_pcb.py`](../kicad/check_pcb.py) — diffs board against `gen.py` for
  either rev; `--rev A` currently exits 1

Run on a machine with KiCad 10, the GUI will show the same thing.

## Recommended order

1. **Re-import the netlist** in pcbnew and confirm RV1 lands. If it does not,
   fix the footprint library reference in `gen.py` — that is the root cause.
2. Run `python3 kicad/check_pcb.py --rev A` until it exits 0.
3. Only then consider laying out or moving the board to rev B.

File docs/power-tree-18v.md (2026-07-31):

# Power tree — single 18 V source

> ## Status: TARGET architecture — **not** what the bench runs today
>
> The bench currently runs **config A**: official 45 W USB-C PD → Pi, Gator 9 V →
> TL072, Nano ESP32 on its own USB-C. That is documented in
> [adc-hookup.md](adc-hookup.md) and is the configuration to follow for bench
> work, **including its power-up ordering (Nano → Pi → Gator, down in reverse)
> and its load-bearing star-ground jumper.** No 18 V source exists yet.
>
> Everything below describes **config B**, the target once an 18 V pack is on
> hand. Adopt it as a unit — the ordering relief and the ground-hazard relief
> described here are consequences of having a *single* source, and do not apply
> to the three-supply bench.

**Design decision (2026-07-28):** when built, the rig runs from **one** central
18 V tool battery — no Gator 9 V, no USB-C bricks. Every rail derives on-board.

Codec rails are identical in both configurations; only the *upstream* source
differs, so bench results carry over unchanged.

## The tree

```
Ryobi 18 V pack  (15.0–20.5 V over discharge)
  │
  ├─ FUSE 3–5 A blade, within 10 cm of the pack
  ├─ low-voltage cutoff module, trips at 15.0 V
  ├─ MASTER SWITCH (SPST, ≥3 A)
  │
  ├──► 7809 linear regulator ──► +9 V rail
  │        (100 nF in, 10 µF out, clip-on heatsink)
  │        ├──► TL072 front-end V+ (pin 8)        [was: Gator 9 V]
  │        └──► Nano ESP32 VIN                    [was: its own USB-C]
  │
  └──► 5 V buck converter, ≥5 A, input rated ≥24 V
           └──► Pi 5                              [was: 45 W USB-C PD]
                  └─ Pi J8 p2 (5 V)  → PCM1808 VCC, PCM5102A VIN
                     Pi J8 p1 (3.3 V) → PCM1808 VDD, MD0/MD1 straps, XSMT
                     Pi J8 p6         → star ground
```

The codec rails are unchanged: they still come off the Pi's header exactly as
[adc-hookup.md](adc-hookup.md) specifies. Only the *upstream* source changed.

## Why each choice

**Nano ESP32 from the +9 V rail, not from 18 V and not from 5 V.** Its VIN
regulator wants **6–21 V**. 5 V is below the minimum — the long-standing "never
feed the 5 V rail into VIN" rule still holds. Raw 18 V is nominally inside the
window, but a freshly charged pack sits near 20.5 V, which is uncomfortably
close to the 21 V ceiling. The 9 V rail sits mid-window at every state of
charge. Cost: the Nano's onboard regulator drops 9 V → 3.3 V at ~50–100 mA,
so ~0.6 W in a small package — expect it warm, not hot.

**Pi 5 via header pins 2/4 — with eyes open.** Two ways to get the pack's
energy into the Pi:

| | Header injection (p2/p4) | 18 V → USB-C **PD source** board |
|---|---|---|
| Parts | one buck | buck + PD-source module |
| PD negotiation | none | real 5 V/5 A handshake |
| Pi input protection / polyfuse | **bypassed** | retained |
| USB peripheral budget | firmware caps total USB at 600 mA unless `usb_max_current_enable=1` | full |

Header injection is documented here as the default **because this build hangs
nothing off USB** — the audio path is I²S, and the design rule is explicitly "no
USB in the audio path." The 600 mA cap therefore costs nothing today. If USB
peripherals are ever added, switch to the PD-source board rather than raising
the cap.

What header injection *does* cost is the Pi's input protection. Compensate with
the pack-side fuse, the low-voltage cutoff, and wiring that cannot be reversed
by construction (keyed connector or polarised header).

**Buck sizing.** Spec **≥5 A** even though this workload will draw far less.
The Pi 5 pulls large current transients, and a buck sized to the average will
brown it out on a spike. Add bulk capacitance at the Pi end of the 5 V run.

## What got better

Collapsing three supplies into one **removes a hazard** the M2 bench review
flagged. Previously the star-ground jumper was load-bearing for the Nano→ADC
clock line: if it dropped, MCLK return current plus inter-supply Y-capacitor
leakage had to find its way home through the PCM1808's SCKI input clamp. With a
single supply there is no second supply to leak against, and no inter-supply
potential to develop.

The paired/twisted HF returns (MCLK, and the BCK/LRC/OUT bundle) and the ~33 Ω
series resistor at the Nano's D2 are still wanted — those are EMI hygiene, not
supply-isolation fixes, and they are unaffected by this change.

## What got worse

**Everything now shares one ground and one source**, so the analog front-end no
longer enjoys any isolation from the Pi's current transients or the buck's
switching residue. Two consequences:

1. Keep the 9 V branch and the 5 V branch as **separate spokes from the star**,
   not daisy-chained through each other.
2. The analog-rail R on the PCM1808's VCC is **no longer conditional** — the
   frozen M2 wiring already splits J8 p2 into *branch A → DAC VIN direct* and
   *branch B → 10 Ω → ADC +5 V*. Keep that split. Consolidating supplies makes
   it more valuable, not less, and the companion bulk (470 µF ∥ 0.1 µF) is now
   worth fitting rather than deferring. **Never run the DAC through the 10 Ω:**
   34 mA × 10 Ω = 340 mV, which drops ADC VCC to 4.41 V on a sagged rail —
   under its 4.5 V minimum.

## Runtime

| Load | Draw |
|---|---|
| Pi 5, bare-metal audio workload | ≈ 6–8 W |
| Nano ESP32 + analog front-end | ≈ 1 W |
| **Total, current build** | **≈ 9 W** → ~1.9 h on a 2 Ah pack (36 Wh), ~3.8 h on 4 Ah |

### Deferred — not in the current build (2026-07-28)

- **SK9822 / APA102 LED bargraph** — parked. When it returns it needs **its own
  buck branch off the 18 V rail**, never the Pi's header: 60 LEDs at full white
  is ≈ 3.6 A / 18 W, which would dominate this entire budget and roughly halve
  runtime. It also needs a 3.3 → 5 V buffer (74AHCT125) on data and clock, since
  the part's V<sub>IH</sub> ≈ 0.7 × V<sub>DD</sub> = 3.5 V and the Pi drives
  3.3 V. Pin reservation (SPI0, GPIO10/11) stays as-is in
  [retro-deck-design.md](retro-deck-design.md) — nothing here reassigns it.
- **SN74HC595 shift register** — parked; no role assigned. Note for whenever it
  is picked up: it is **HC**, not AHCT, so its own V<sub>IH</sub> at 5 V is
  ≈ 3.5 V. It cannot serve as a 3.3 V → 5 V level shifter, for the LED strip or
  anything else.

Stop discharging at **15.0 V**. The cutoff module is not optional on a lithium
tool pack.

## Order of operations

Unchanged in principle — the Nano must clock before the ADC is expected to
master the bus — but there is now **one switch** instead of three supplies to
sequence:

1. Wire everything **unpowered**. Straps first: FMT→GND, MD0/MD1→3.3 V.
2. **Leave the D2→D3 link in place** — the frozen M2 wiring keeps it as a
   permanent MCLK health readout, tapped *before* the 33 Ω.
3. **Meter the rails before landing the codec leads.** With the module's two
   power leads *not yet connected*, close the master switch and confirm +9 V,
   +5 V, and the Pi's J8 p1/p2 at 3.3 V/5.0 V. J8 pins 1 and 2 are physically
   adjacent and VDD is 4 V abs-max — a one-row slip kills the ADC.
4. Open the master switch, land the codec leads, close it again.
5. Before touching any wire later: **open the master switch first.** One switch
   now kills every rail, which is the main ergonomic win of this change.

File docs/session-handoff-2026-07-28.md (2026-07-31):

# Session handoff — 2026-07-28

State of the hardware-documentation work at the end of this session, for
whoever (or whatever) picks it up next. Delete this file once its contents have
been absorbed into the permanent docs.

## Landed on `main`

| Commit | What |
|---|---|
| `6d259fb` (#3) | `kicad/gen.py` rev-B variant behind `GDAW_REV=B`; `kicad/test_rev.py` gate (23/23, mutation-tested) |
| `f2a9662` (#4) | Single-18 V power tree + `docs/power-tree-18v.md` |

**Rev A is still the default and regenerates byte-identically** —
`retro-deck-design.md` §5 keeps it as the learning vehicle, so rev B lives
behind a flag and writes its own `-revB` artifacts. Run
`GDAW_REV=B python3 kicad/gen.py`; verify with `python3 kicad/test_rev.py`.

Encoded in rev B: MD0/MD1 → `+3V3` (ADC is bus master), MCLK from Nano
`J4.1` → 33 Ω → `U2.6` SCKI, GPIO4 removed from J8, 3.3 V from **J8 pin 1**
(user decision), AP2112K LDO not populated.

## Open pull requests

| PR | State | Blocker |
|---|---|---|
| **guitardawliteos#5** | bench power restore, 45 W PSU, Nano-off-USB, `boot-selfcheck.md` | ready to merge; nothing pending |
| **guitardawliteos#2** | `docs/pinmap-plan-revB.md` — the pin-for-pin diagram plan | **stale**: written before #3/#4. Its §1 step 1 (the `gen.py` patch) is now **done**. Its power references still describe three supplies. Rebase + reconcile before merging. |
| **guitardawliteos#1** | analog pedal wiring docs moved in from `pedal-workshop` → `docs/pedal-wiring/` | **decision pending** (below), and stale for the same reason |
| **pedal-workshop#2** | removes `docs/wiring/gdawlitos/` from the app repo | land guitardawliteos#1 **first** so the docs are never absent from both |

## Decisions still needed

1. **guitardawliteos#1, figs 5–6.** They were drawn assuming a USB-powered Pi
   recording through a **USB audio interface** — which contradicts this project
   outright (bare metal, I²S, "no USB in the audio path"). They are currently
   *flagged* with a banner, not corrected. Either rework them to the real
   architecture or drop them and keep figs 1–4, which are architecture-neutral
   (analog stompbox harness only) and stand on their own.
2. **Circle GPIO/I²S pin mux.** Does Circle allow claiming GPIO18 as a plain
   input and then handing it to the I²S driver, or must I²S own the mux for the
   whole run? This decides whether the clock-domain probe in
   [boot-selfcheck.md](boot-selfcheck.md) can be a pre-flight step or must be a
   one-shot at startup. **Blocks implementing phase 1.**
3. **Boot self-check phase 2** (Pi → Nano RST line). J8 has no free GPIO —
   `retro-deck-design.md` §4 allocates all 28. Borrow GPIO10/11 while the
   bargraph is deferred, put it on the MCP23017, or skip. Recommendation: skip
   for now; a wedged Nano has not been observed.
4. **Power-up order in `wiring-diagram.svg`.** It previously read
   `1. Pi · 2. Nano · 3. Gator`, contradicting `adc-hookup.md`'s **Nano-first**
   rule and its review-B1 justification. Resolved toward Nano-first. Confirm
   Pi-first was not deliberate.

## Bench vs target — do not conflate

The bench runs **three supplies**: official **45 W** USB-C PD → Pi, Gator 9 V →
TL072, Nano on its own USB-C (moving to Gator 9 V → VIN). No 18 V source exists
yet. The three-supply bench keeps its **power-up ordering** and its
**load-bearing star-ground jumper** — both of those rules are relieved *only* by
having a single source. `power-tree-18v.md` carries a status banner saying so.

Codec rails are identical in both configurations, so bench measurements carry
over unchanged.

## Parked

- **SK9822 / APA102 bargraph** — needs its own buck branch off 18 V (≈3.6 A at
  full white) and a 74AHCT125 buffer (part V<sub>IH</sub> ≈ 3.5 V vs the Pi's
  3.3 V). SPI0 GPIO10/11 reservation stands.
- **SN74HC595** — no role assigned. It is **HC, not AHCT**, so it cannot
  level-shift 3.3 V → 5 V.
- **CD4053BE** — in the drawer, notes in `tl072-frontend.md`, not in any netlist.
- **2N2222A** — suited to NKK transport lamps (low-side switch), not to the
  `SOLENOID_DRV` on the TRANSPORT header.
- **4N35** — suited to the REM jack punch-in (`retro-deck-design.md` item 3),
  with the caveat that it is a phototransistor output: DC-only and
  polarity-sensitive, where a true optoMOS (AQY212/TLP222A) is bidirectional.

## Largest outstanding gap

The **physical module survey** is still unwritten. `pinmap-plan-revB.md`
identified **23 pin-level facts no document states** — chiefly the GY-PCM5102
module's header pin order, the Nano's D2/GND header positions, and the as-built
status of the M2 hardening items. A bench photo of the layout exists but was
never captured into a doc. Until that survey lands, any "pin-for-pin" wiring
diagram is partly guesswork at the module level.

Also outstanding: the `.kicad_pcb` is stale even for rev A (RV1 footprint
absent) and was not touched by #3.

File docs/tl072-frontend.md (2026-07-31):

# TL072 front-end variant — single 9 V (drawer-parts build)

The canonical front-end ([schematic.md](schematic.md)) runs an MCP6002/OPA1662
on the Pi's 5 V rail. A **TL072 cannot do that** — but on a **9 V pedal supply
or battery** (its natural habitat) it works beautifully, and the topology is
otherwise identical. SPICE-verified: [sim/frontend-tl072-9v.cir](sim/frontend-tl072-9v.cir)
→ [sim/frontend-tl072-9v-results.txt](sim/frontend-tl072-9v-results.txt).

## Why the TL072 can't run the 5 V design

Three independent dealbreakers on a 5 V single rail (classic TL072CP specs):
1. **Minimum supply ~7 V** — 5 V is simply out of spec.
2. **JFET input common-mode must stay ≥ V− + 4 V** — the 2.5 V mid-rail bias
   sits 1.5 V below that; risk of the notorious TL07x phase-reversal.
3. **Output swings only to ~1.5 V from each rail** — the design needs 4.0 V
   peaks on a 5 V rail; the TL072 tops out around 3.5 V.

## The 9 V variant — two changes from schematic.md

| What | 5 V canonical | 9 V TL072 |
|---|---|---|
| U1 supply (pin 8 / pin 4) | +5 V / GND | **+9 V** / GND |
| VBIAS divider R1/R2 | 10 k / 10 k → 2.5 V | **10 k / 12 k → 4.9 V** (keeps the JFET inputs ≥ 4 V from ground with margin) |

Everything else is unchanged: Cin 0.1 µF → Rbias 1 M → U1A buffer → U1B
non-inverting ×3 (Rg 10 k to VBIAS, Rf 10 k + trim), Cout 1 µF → Rs 1 k +
Ca 1 nF → VINL. **Cout isolates the 9 V domain from the ADC** — the PCM1808
self-biases its input after the cap, so the ADC side doesn't know or care
what rail the op-amp runs on. TL072 is pin-compatible with the MCP6002
(standard dual op-amp DIP-8), so the breadboard layout is unchanged too.

## Add a supply bypass cap (M2 review, 2026-07-22)

**`C_byp` = 100 µF electrolytic ∥ 0.1 µF ceramic at U1 pin 8 → GND.** The as-built
docs had *no* supply bypass, and the SPICE deck modeled the 9 V supply as ideal,
so rail ripple was never analyzed. **This matters more since 2026-07-28**, because
the 9 V now comes from a 7809 fed by the same pack that runs the Pi's buck, rather
than from an isolated wall PSU. It matters more than it looks anyway, because
**VBIAS ripple is not common-mode here** — at 120 Hz Cin (0.1 µF ≈ 13 kΩ) shunts the
gain stage's + input toward the low-impedance guitar, so ripple on VBIAS gets
*inverting-amplified* by Rf/Rg, not cancelled.

Cross-checked in ngspice (rail → ADC-pin transfer, ideal low-Z source = plugged-in guitar):

| Trim | rail → ADC transfer | 10 mVpp rail ripple → |
|---|---|---|
| default ×3 (Rf = 20 k) | **−31.7 dB** | ~−81 dBFS (inaudible) |
| max trim ×12 (Rf = 110 k) | **−16.9 dB** | ~−66 dBFS (audible hum) |

So the hum only bites when you crank the trim for a weak pickup — but that's a real
operating point. `C_byp` at the op-amp pin cuts the switching-residual path outright
and is standard practice for an op-amp on the end of a wall-wart cable; add it.
*(This corrects the review's own "common-mode ×1" downgrade — the ×1 assumption only
holds for an open input; a plugged-in guitar sees the Rf/Rg path.)*

## SPICE results (ngspice-46, 2026-07-10)

| Check | Result | Pass bar |
|---|---|---|
| DC bias | 4.909 V, all nodes centered | ~4.9 V |
| Gain | 9.54 dB (×3.00), flat 100 Hz–20 kHz | ~9.5 dB |
| Low corner | 2.7 Hz | ≤ 20 Hz |
| Hot humbucker 1 Vpp → ADC pin | **1.02–3.97 V** | inside 1.0–4.0 V full-scale |
| JFET common-mode minimum | 4.41 V | ≥ 4.0 V (guaranteed limit) |
| Op-amp headroom | no clip even at 1.6 Vpp overdrive | ADC full-scale clips first → set the trim so hard strums peak just under it |

## Bench notes

- **Power:** 9 V pedal PSU (preferred) or battery. ⚠️ Boss-style pedal supplies are
  **center-negative** — check polarity before it checks you. ⚠️ **Keep the rail ≥ 8.3 V.**
  VBIAS = 0.545·V_rail, so below ~8.3 V a 1 Vpp hot-humbucker drives the JFET input
  under its guaranteed common-mode floor (V− + 4 V) → progressive distortion first,
  and the notorious TL07x output latch-up only at a much lower rail. A fresh 9 V is
  fine; a half-dead battery drifts into the distortion zone — prefer the PSU, or
  swap the battery early.
- **Ground:** the 9 V negative terminal joins the same star ground as
  everything else (Pi pin 6 rail). Two supply domains, one ground.
- The 9 V rail powers **only U1**. The PCM1808's VCC stays on the Pi's 5 V
  per [adc-hookup.md](adc-hookup.md) — do not put 9 V anywhere near the ADC.

## Bench setup: CopperSound DIY breadboard (medium) + Gator 9 V PSU

The whole front-end lives on the CopperSound board — it exists for exactly
this kind of circuit:

- **Gator 9 V →** the CopperSound board's **DC jack**. Both sides are
  standard Boss-style center-negative, so polarity is handled by using
  them as intended. Its power rails become the front-end's +9 V and GND
  (check the board's own rail labels).
  *(Target build swaps the Gator for a 7809-derived +9 V rail off the
  central 18 V pack — [power-tree-18v.md](power-tree-18v.md). Everything
  downstream of the DC jack is identical either way.)*
- **Guitar →** the board's **input jack** → Cin 0.1 µF → Rbias 1 M →
  TL072 buffer → ×3 gain stage → **Cout 1 µF → the board's output jack**.
- **Output jack → PCM1808 side** with a regular instrument cable (or a
  wire pair). Put **Rs 1 k + Ca 1 nF at the ADC end**, right at the VINL
  pin — the anti-alias RC belongs at the pin it protects, not on the
  pedal board.
- **One explicit ground wire** from the CopperSound GND rail to the star
  ground (Pi pin 6 rail). The cable's sleeve nominally carries ground
  too, but the audio reference shouldn't hang off a patch cable.

On the bench: two supply domains, one ground — the Gator 9 V feeds only the
TL072 board; the Pi's 5 V/3.3 V feed the PCM1808 per
[adc-hookup.md](adc-hookup.md). In the target build both rails come off the same
18 V pack and must stay **separate spokes from the star**, not daisy-chained
([power-tree-18v.md](power-tree-18v.md)).

This rig doubles as the pedal-development platform for the Pedal Workshop
merge — same board, pedals prototyped between the guitar and this front-end.
A pedal under test wants its own 9 V feed or a dedicated rail spoke, not a
daisy-chain through the front-end's.

## Also in the drawer: CD4053BE

Not needed for the M2 capture path — **park them for rev B**, where they're
a great fit (GPIO-controlled analog switching: the tape-insert wet/dry path,
input source select, punch-in routing — and they're the classic
Boss/Ibanez-style bypass-switching chip, relevant to the pedal-workshop
merge). One catch to remember when that day comes: at VDD = 5 V a CD4053's
select pins want VIH ≈ 3.5 V, which the Pi's 3.3 V GPIO doesn't reach — run
the 4053 at VDD = 3.3 V (fine, but signals must then stay within 0–3.3 V) or
level-shift the select lines.

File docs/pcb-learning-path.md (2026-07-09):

# GuitarDAWLiteOS — PCB design learning path & open-hardware roadmap

A follow-along curriculum that teaches PCB design **by turning GuitarDAWLiteOS into a hackable open-hardware board**. Each milestone is a real, finishable step with a deliverable.

---

## First: how KiCad files actually work (this is why the earlier files wouldn't open)
KiCad's **File → Open** wants a **project**, not a netlist or a symbol library:

| File | What it is | How you use it |
|---|---|---|
| `*.kicad_pro` | **the project** — open *this* | double-click / File → Open |
| `*.kicad_sch` | the schematic | opens inside the project (Eeschema) |
| `*.kicad_pcb` | the board | opens inside the project (Pcbnew) |
| `*.kicad_sym` | a **symbol library** (parts you place) | registered via a sym-lib-table, *not* opened |
| `*.net` | a **netlist** (connections export) | *imported* into a board, not opened |

`kicad/` now contains a real, openable project (verified with `kicad-cli`): **open [`kicad/guitardawliteos.kicad_pro`](../kicad/guitardawliteos.kicad_pro)**. It comes up to a titled blank schematic with the `GuitarDAWLiteOS` symbol library (PCM1808, PCM5102A) already registered, plus the generated `guitardawliteos.net` / `bom.csv` as inputs.

---

## Two ways in
- **See it instantly (5 min):** open the project → **PCB Editor** → *File → Import → Netlist…* → `guitardawliteos.net` → all 41 footprints drop in with a ratsnest. Great for seeing what a board *is*.
- **Learn it (the path below):** draw the schematic yourself from the reference, then lay out the board. This is where the skills come from.

Your reference / "answer key" while you draw: [schematic.md](schematic.md) (net-by-net), [frontend-schematic.svg](frontend-schematic.svg), [codec-power-schematic.svg](codec-power-schematic.svg), [bom.csv](../kicad/bom.csv).

---

## Curriculum (each milestone = one sitting)

### M1 — KiCad orientation & a board from the netlist  ·  *learn the tool end-to-end*
Open the project, tour Eeschema/Pcbnew, import `guitardawliteos.net` to a board, draw a rectangular **Edge.Cuts** outline, run **DRC**, export **Gerbers** (`File → Fabrication Outputs`). You won't route yet — the goal is the full loop: project → board → fab files.
**Deliverable:** a zip of Gerbers for a (blank-routed) board. You'll have touched every KiCad area once.

### M2 — Draw the schematic  ·  *the core skill*
Start with the **front-end** (the SPICE-verified part): place `Device:R`/`Device:C`, the op-amp (`Amplifier_Operational:OPA1662` or `Device:Opamp_Dual`), wire it per [frontend-schematic.svg](frontend-schematic.svg). Then add `PCM1808`/`PCM5102A` (from the `GuitarDAWLiteOS` lib), the `AP2112K-3.3`, and the Pi header (`Connector_Generic:Conn_02x20_Odd_Even`). Use **global labels** for `+5V`, `+3V3`, `GND`, `MCLK`, `BCLK`, `LRCLK`, `CAPDAT`, `PLAYDAT` instead of long wires. Annotate, **assign footprints** (see bom.csv), run **ERC** to zero.
**Deliverable:** your own `.kicad_sch` that ERCs clean — compare its netlist to `guitardawliteos.net`.

### M3 — Layout & routing  ·  *the craft*
Update PCB from schematic. Place: keep the **analog front-end and its star ground away from the BCLK/LRCLK/MCLK** runs; `FB1`+`C2`/`C3` hard against U2 VCC. Route power first (use the **Power** net class = wider tracks), then signals; add a **ground pour**. Run **DRC** to zero.
**Deliverable:** a routed 2-layer board + 3D view (`Alt+3`).

### M4 — Make it a Raspberry Pi HAT  ·  *the form factor*
Set the board outline to the **HAT mechanical spec** (65 × 56 mm, the 4 mounting holes at the standard coordinates), align the 2×20 header to the Pi, and add the optional **ID EEPROM** (24Cxx on GPIO0/GPIO1 = ID_SD/ID_SC) so the HAT self-identifies. Add the hackability features below.
**Deliverable:** a mountable HAT that physically fits a Pi 5 and **ships with GuitarDAWLiteOS** (HAT + Pi 5 + the SD card you already built).

### M5 — Open-hardware release  ·  *ship it*
Add a `LICENSE` for the hardware (recommend **CERN-OHL-S v2** — strongly reciprocal, the hardware analogue of the GPLv3 your Circle firmware already uses). Export the release set: schematic PDF, Gerbers + drill, BOM, pick-and-place, a 3D render, and the **editable KiCad sources**. Tag a version.
**Deliverable:** a `hardware/releases/v0.1/` folder anyone can fabricate from — true open hardware.

### M6 — Rev B: the "GuitarDAW Audio HAT+"  ·  *your second board*
Re-spin the audio HAT with the Phase-2 features from [retro-deck-design.md](retro-deck-design.md): the **tape loop** (TAPE OUT pad + trim, TAPE IN→VINR jumper, REM optoMOS jack, unpopulated TRANSPORT header + IR footprint), the **ID EEPROM** (CAT24C32 @0x50 — makes it an official HAT+ *and* Linux-dual-use), buffered line taps + panel connector, 16 mm stacking for the Active Cooler, and optionally the **Pisound-style 100×56 stretch** so jacks exit the rear wall. This is where `gen.py` earns its keep: add the rev-B section, regenerate, re-import.
**Deliverable:** rev-B board — the one that ships in the deck.

### M7 — Faceplate PCB + panel electronics  ·  *the retro face*
A 2.0 mm FR4 faceplate (silkscreen retro graphics, exposed-gold accents) with cutouts for **real VU meters** (200 µA movements + TL072 rectifier drivers), **NKK UB illuminated transport keys**, knobs, and the **Touch Display 2 window** (portrait panel mounted sideways); rear component PCB carries switches/LEDs/APA102 bargraph, clamped by the panel hardware — no visible fasteners. PCB-as-front-panel is standard synth-DIY practice; this milestone is where the deck gets its face.
**Deliverable:** faceplate + panel PCB pair.

### M8 — Enclosure + integration  ·  *the deck*
Folded sheet-metal U-chassis + CNC wood side cheeks (both published as open DXF), Active Cooler venting through period-correct grilles, Pi 5 + HAT+ + panel + (optionally) a Tanashin-clone cassette mechanism inside. Hammond 1456CWW is a fine prototype shell (walnut line is being discontinued — not an open-BOM dependency).
**Deliverable:** the assembled retro deck, shipping GuitarDAWLiteOS.

### M9 — (stretch) Embed the Pi: CM5 carrier  ·  *advanced*
Once HAT skills are solid, design a carrier for the **Compute Module 5** (the real "embedded Pi"). Genuinely advanced — high-speed differential pairs, power sequencing, the two 100-pin connectors — a *phase 3*, not a first board. Route the same 22-pin DSI FPC + display power; note `rp1dsi` is **unconfirmed on CM5** (validation spike required). Same audio subcircuit, now on your own mainboard.

---

## Designing for hackability (build these into M3–M4)
- **Break out the spares:** spare GPIO, the I²C bus, and UART to a labeled header — invite hacking.
- **Test points** on `VBIAS`, `MCLK`, `BCLK`, `VINL`, `+5V`, `+3V3` — so the board is probeable (and you can scope Spike B).
- **Option jumpers:** input-source select, front-end bypass, gain-range — so behavior is reconfigurable without a respin.
- **Sockets:** an SOIC-8 socket (or DIP + adapter) for the op-amp lets people roll their own front-end.
- **Silkscreen everything:** pin-1 dots, net names at headers, the XSMT/MD-strap reminders — the board should be self-documenting.
- **Publish editable sources**, not just Gerbers. Open hardware = others can *modify*, which needs the `.kicad_*` files + this repo.

## Workflow you now have (and how to refine it)
- **Circuit-as-code:** [`kicad/gen.py`](../kicad/gen.py) defines components + nets in Python and emits the netlist/symbols/BOM with a built-in ERC. Edit the circuit there → `python3 gen.py` → re-import. Pairs code review with schematic capture.
- **Headless validation:** `kicad-cli sch erc` / `pcb drc` / `sch export svg` let you check designs from the terminal or CI — no GUI needed. (`kicad/validate.py` does the same for the generated files.)
- **Version control:** commit the `.kicad_*` sources; KiCad files are text and diff reasonably. Keep `gen.py` as the source of truth for the netlist.
- **Next refinement:** add a `make` target that runs gen.py + kicad-cli ERC/DRC + Gerber export, so a board release is one command.

## Recommended direction
**Start at M1→M4 as a Pi 5 HAT.** It's the right first PCB (beginner-feasible, immediately ships with the OS, genuinely open hardware), and the audio subcircuit is identical to what a future CM5 carrier (M6) would carry — so nothing is wasted. "Embedded Pi" (CM5) is a great *phase-2 goal* once the HAT skills land. If you'd rather aim straight at CM5, say so and I'll restructure M4 around the CM5 connectors instead — but I'd still prototype the audio as a HAT first.

> Licensing stack for the open-hardware release: **hardware** → CERN-OHL-S v2 · **firmware** → GPLv3 (Circle) · **docs** → CC-BY-SA 4.0.

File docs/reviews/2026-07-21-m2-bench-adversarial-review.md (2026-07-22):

# M2 Bench — Adversarial Review (2026-07-21)

Adversarial review of the **as-built M2 bench package** (post clock-pivot `f524c7d`, sheets redrawn
`40a6248`): the wiring diagram, the two schematic sheets, `adc-hookup.md`, and the supporting docs the
builder wires from. Method: a 6-lens multi-agent finder fan-out (clocking · analog · power · firmware
contract · doc-consistency · bench-procedure) → per-finding refuting verifiers → completeness critic.

## ⚠️ Read this first — the run was incomplete

The session token limit was hit mid-run (resets nightly). **Only 3 of 6 finder lenses completed** —
`power`, `consistency`, `procedure`. The **`clocking`, `analog`, and `firmware-contract` lenses died before
returning**, as did the completeness critic and **most of the refuting verifiers**. Consequences:
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

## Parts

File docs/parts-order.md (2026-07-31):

# GuitarDAWLiteOS — DigiKey Prototyping Order

**Verified against live DigiKey listings 2026-07-01** (stock counts are snapshots — reverify at checkout). Search DigiKey by the **MPN** column. Covers: breadboard prototype (Milestone 2), spikes A/B/C, guitar front-end, tape-loop Level A, and a rev-B PCB stock-up. Skip any section you don't need yet.

## 1. Pi platform & debug *(skip what you already own)*
| Qty | MPN | Item | ~$ | Note |
|--:|---|---|---:|---|
| 1 | **SC0889** | Raspberry Pi Debug Probe | 12 | **Get this** — the UART console via the Pi 5 3-pin JST-SH debug connector; cables included. Replaces a generic USB-serial + guesswork. |
| 1 | **SC1148** | Pi 5 Active Cooler | 5 | Needed for the closed retro box later; nice on the bench now. |
| 1 | — | official **45 W** USB-C PD supply | — | **In use on the bench** (supersedes the 27 W SC1158 originally listed). Target build replaces it with a 5 V buck off the 18 V pack (`docs/power-tree-18v.md`); keep it for bench work either way. |
| (1) | SC1432 | Raspberry Pi 5, 8 GB | **175** | ⚠️ DRAM-shortage pricing (was $80 MSRP). **If you already have a Pi 5, skip**; if buying spares for the project, decide whether to wait out the memory price surge. |

## 1b. MCLK generator (Spike B, added 2026-07-09)
| Qty | MPN | Item | ~$ | Note |
|--:|---|---|---:|---|
| 1 | **ABX00083** | Arduino Nano ESP32 (ESP32-S3, with headers) | ~19 | **Skip if you already own one.** Generates the 12.288 MHz MCLK for the PCM1808 off-board — the Pi 5's internal `GPCLK0` route was ruled out (`clk_i2s` conflicts with BCLK). See [claim-verification.md](claim-verification.md), [../esp32-mclk/](../esp32-mclk/). Price is a search-derived estimate, not checkout-verified like the rest of this doc — reverify at DigiKey before ordering. |

## 2. Breadboard infrastructure
| Qty | MPN | Item | ~$ | Note |
|--:|---|---|---:|---|
| 1 | **BB830** | 830-pt solderless breadboard | 9 | ⚠️ Order DigiKey PN **4526-BB830-ND** (DigiKey-direct) — there's a marketplace duplicate listing of the same MPN. |
| 1 | **2028** (Adafruit) | Pi T-Cobbler Plus + ribbon, 40-pin | 8 | Only 68 in stock — order early. |
| 1 | TW-E012-000 | 140-pc jumper wire kit | 7 | |
| 2 | A 08-LC-TT | DIP-8 socket | 0.4 | For the MCP6002 (MPN really has the space). |
| 3 | PRPC040SAAN-RC | 1×40 breakaway male header | 1.7 | Snap to length for the TSSOP adapters. |

## 3. Audio codecs + adapters (breadboard path = bare chips on adapters)
| Qty | MPN | Item | ~$ | Note |
|--:|---|---|---:|---|
| 3 | **PCM1808PWR** | ADC, TSSOP-14 (cut tape) | 4.8 | ×3 = soldering practice spares. 4,990 in stock. |
| 3 | **PCM5102APWR** | DAC, TSSOP-20 (cut tape) | 11.4 | PWR cut-tape is ~half the tube price. |
| 1 | **1210** (Adafruit) | TSSOP-14→DIP adapter, 6-pack | 5 | For the PCM1808. |
| 1 | **1206** (Adafruit) | TSSOP-20→DIP adapter, 3-pack | 4.5 | For the PCM5102A. ⚠️ 1207 is the 16-pin version — wrong. Only 61 in stock. |
| 1 | 111X (Switchcraft) | ¼″ mono guitar jack, panel | 4.6 | The classic amp jack. |

> Alternative if you'd rather not solder TSSOP yet: **Adafruit 6250** (PCM5102 breakout) is in DigiKey's channel; the GY-PCM5102/GY-PCM1808 modules themselves are **AliExpress/Amazon only** (see §8).

## 4. Guitar front-end
| Qty | MPN | Item | ~$ | Note |
|--:|---|---|---:|---|
| 3 | **MCP6002-I/P** | dual RRIO op-amp, DIP-8 (breadboard) | 1.2 | 11k+ in stock. |
| 3 | **OPA1662AID** | dual audio op-amp, SOIC-8 (rev-B PCB) | 8.2 | In stock (tube). ⚠️ The fallback "OPA1678AID" doesn't exist and OPA1678ID is backorder-only — OPA1662 is the part. |
| 1 | **3296W-1-104LF** | 100 k 25-turn trimmer (RV1 gain) | 2.4 | |
| 1 | 3296W-1-102LF | 1 k trimmer (tape-out level, §6) | 2.4 | |

## 5. Passives (audio path + decoupling) — all verified in stock
| Qty | MPN | Item | ~$ | Note |
|--:|---|---|---:|---|
| 5 | **MKS2D031001A00MSSD** | 0.1 µF/100 V WIMA box film (Cin) | 2.8 | ⚠️ The ±10 % sibling (…KSSD) is discontinued — order this ±20 % one. |
| 5 | **B32529C0105K000** | 1 µF/63 V TDK box film (Cout, Cr) | 3.3 | ⚠️ **All WIMA MKS2 1 µF variants are dead at DigiKey**; this EPCOS/TDK is the stocked 5 mm part. |
| 3 | FG28C0G1H102JNT06 | 1 nF C0G disc (Ca anti-alias) | 0.8 | |
| 3 | C320C222J1G5TA | 2.2 nF C0G (DAC output RC) | 1.6 | |
| 10 | ECA-1EM100 | 10 µF/25 V electrolytic (bulk decoupling, VBIAS) | 1.9 | |
| 2 | **74275022** | Würth THT ferrite bead (FB1) | 0.8 | Closest stocked TH ~600 Ω-class bead (512 Ω@100 MHz, 3 A). Only 282 in stock. |
| 10 ea | (generic) | 1 % ¼ W metal-film resistors: **1 M, 10 k, 5.6 k, 3.9 k, 1 k, 470 Ω** | ~6 | Commodity — e.g. Yageo MFR-25 series; or a resistor kit if you don't have one. 0.1 µF ceramic decoupling (0.1 µF X7R radial ×10) too if not on hand. |

## 6. Tape loop — Level A (rev-B provisions, breadboard-testable now)
| Qty | MPN | Item | ~$ | Note |
|--:|---|---|---:|---|
| 2 | **AQY212GH** | PhotoMOS relay (REM punch-in), 60 V/1.1 A | 5.6 | ⚠️ **TLP222A is obsolete** (whole family discontinued) — AQY212GH is the pick; TLP240A(F) is the cheaper stocked alt ($2.16). |
| 1 | SJ1-2503A | 2.5 mm jack (REM) | 0.7 | It's TRS (no true TS part stocked): wire **tip+sleeve**, leave ring floating. |
| 4 | **PJRAN1X1U01X** | Switchcraft RCA jack, PCB right-angle | 5.7 | Tape in/out pairs. ⚠️ Same Sky RCJ-014/041 are 0-stock/15-wk backorder — don't spec them. |

## 7. Rev-B PCB stock-up (optional now — cheap, and you'll need them)
| Qty | MPN | Item | ~$ |
|--:|---|---|---:|
| 3 | AP2112K-3.3TRG1 | 3.3 V LDO, SOT-25 | 0.7 |
| 2 | **CAT24C32WI-GT3** | HAT+ ID EEPROM, SOIC-8 | 0.9 |

## 8. Display
| Qty | MPN | Item | ~$ | Note |
|--:|---|---|---:|---|
| 1 | **SC1635** | **Touch Display 2, 7″** (720×1280 DSI) | 60 | The Spike-C / retro-deck default — **used display-only** (`bEnableTouch=FALSE`; UI pivot 2026-07-23: knobs, not touch). No non-touch official DSI panel exists and `rp1dsi` only drives the official panels, so the touch layer is paid for but unused. Plain HDMI = the $0 bench alternative. ⚠️ Earlier docs guessed SC1148 — that's the Active Cooler; **SC1635** is the 7″ TD2. |
| (1) | SC1975 | Touch Display 2, 5″ | 40 | Compact-build variant — optional (also display-only). |

### 8b. Control surface (UI pivot 2026-07-23 — knobs Michael already owns + pedal additions)
| Qty | Part | What | ~$ | Note |
|----:|---|---|---:|---|
| 5 | EC11-class encoder w/ push (e.g. Bourns **PEC11R-4215F-S0024**) | rotary knob + push | ~1.50 ea | **Michael already has 5 knob-button encoder modules** — buy nothing unless they prove to be 5 V-only boards. KY-040 modules: power "+" from **3.3 V only**; SW pin needs the internal pull-up. |
| 1 | ¼″ TS panel jack (Switchcraft 111X pattern) | sustain-pedal input | ~3 | Second ¼″ jack beyond the guitar input. Switched-contact tip if plug-detection wanted. |
| 1 | Yamaha **FC5** (or FC4A) | sustain-pedal footswitch | ~20 | TS momentary, **normally-closed at rest** — firmware auto-polarity at boot handles it (and any NO pedal). Avoid FC3A (TRS half-damper, not a switch). |
| 1 | **MCP23017-E/SP** | I²C1 panel expander (rev-B) | ~2 | Absorbs the slow tape-transport signals + NKK keys; required by the recomputed GPIO budget (J8 is fully consumed by the knob UI). |

## NOT from DigiKey (order elsewhere)
- **GY-PCM5102 / GY-PCM1808 modules** — AliExpress/Amazon (~$3–8). Fastest breadboard path; §3's bare-chips-on-adapters is the DigiKey-only equivalent.
- **Cassette mechanism** (Tanashin TN-21ZLG clone, ~$10–20) + **TA7668 head-preamp board** (~$10) — AliExpress. Level B, not needed yet.
- **200 µA VU meter movements** (~$5–15) — AliExpress/Amazon. M7 faceplate, not needed yet.
- **NKK UB illuminated switches** — DigiKey *does* carry them (~$10+ each) but they're M7 panel parts; don't buy until the faceplate design.
- **Bench tools**: Spike B (12.288 MHz MCLK) is **done** — frequency-verified 2026-07-09 via the Nano's own PCNT self-test, no scope needed. A scope/LA (≥25 MHz, e.g. Digilent or used) is now **optional**, only for the open *jitter-characterization* question (see the M2 review) — not required to build or bring up the bench.

## Rough totals
- **Core prototype** (§2–§6, no Pi/display): **~$95–110**
- **+ Debug Probe & Active Cooler** (§1, no Pi): +$29
- **+ Nano ESP32 MCLK generator** (§1b, skip if you already own one): +$19
- **+ 7″ Touch Display 2**: +$60
- Everything incl. a new Pi 5: ~$380 (of which $175 is shortage-priced Pi)

### Checkout gotchas recap
1. BB830: pick the **DigiKey-direct** listing (4526-…), not marketplace.
2. Low-stock items to grab first: Adafruit **1206** (61), T-Cobbler **2028** (68), Würth bead **74275022** (282).
3. TLP222A, WIMA 1 µF MKS2, Same Sky RCA jacks, ±10 % MKS2 0.1 µF: all dead/backordered — substitutes above are the verified picks.

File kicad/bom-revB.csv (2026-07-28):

Ref | Value | Footprint
C1 | 10uF | Capacitor_SMD:C_1206_3216Metric
C10 | 2.2uF | Capacitor_SMD:C_0805_2012Metric
C11 | 2.2uF | Capacitor_SMD:C_0805_2012Metric
C12 | 0.1uF | Capacitor_SMD:C_0805_2012Metric
C13 | 10uF | Capacitor_SMD:C_1206_3216Metric
C14 | 0.1uF | Capacitor_SMD:C_0805_2012Metric
C15 | 0.1uF | Capacitor_SMD:C_0805_2012Metric
C16 | 10uF | Capacitor_SMD:C_1206_3216Metric
C2 | 0.1uF | Capacitor_SMD:C_0805_2012Metric
C3 | 10uF | Capacitor_SMD:C_1206_3216Metric
C4 | 0.1uF | Capacitor_SMD:C_0805_2012Metric
C5 | 10uF | Capacitor_SMD:C_1206_3216Metric
C6 | 0.1uF | Capacitor_SMD:C_0805_2012Metric
C7 | 10uF | Capacitor_SMD:C_1206_3216Metric
C8 | 0.1uF | Capacitor_SMD:C_0805_2012Metric
C9 | 0.1uF | Capacitor_SMD:C_0805_2012Metric
Ca | 1nF | Capacitor_SMD:C_0805_2012Metric
Cin | 0.1uF | Capacitor_SMD:C_0805_2012Metric
Col | 2.2nF | Capacitor_SMD:C_0805_2012Metric
Cor | 2.2nF | Capacitor_SMD:C_0805_2012Metric
Cout | 1uF | Capacitor_SMD:C_0805_2012Metric
Cr | 1uF | Capacitor_SMD:C_0805_2012Metric
FB1 | FerriteBead | Inductor_SMD:L_0805_2012Metric
J1 | Guitar_6.35mm | Connector_PinHeader_2.54mm:PinHeader_1x03_P2.54mm_Vertical
J2 | Line_out | Connector_PinHeader_2.54mm:PinHeader_1x03_P2.54mm_Vertical
J3 | RPi5_GPIO | Connector_PinHeader_2.54mm:PinHeader_2x20_P2.54mm_Vertical
J4 | Nano_ESP32_MCLK | Connector_PinHeader_2.54mm:PinHeader_1x03_P2.54mm_Vertical
R1 | 10k | Resistor_SMD:R_0805_2012Metric
R2 | 10k | Resistor_SMD:R_0805_2012Metric
RV1 | 100k | Potentiometer_THT:Trimmer_Bourns_3296W_Vertical
R_mclk | 33 | Resistor_SMD:R_0805_2012Metric
Rbias | 1M | Resistor_SMD:R_0805_2012Metric
Rf | 10k | Resistor_SMD:R_0805_2012Metric
Rg | 10k | Resistor_SMD:R_0805_2012Metric
Rol | 470 | Resistor_SMD:R_0805_2012Metric
Ror | 470 | Resistor_SMD:R_0805_2012Metric
Rs | 1k | Resistor_SMD:R_0805_2012Metric
U1 | OPA1662 | Package_SO:SOIC-8_3.9x4.9mm_P1.27mm
U2 | PCM1808 | Package_SO:TSSOP-14_4.4x5mm_P0.65mm
U3 | PCM5102A | Package_SO:TSSOP-20_4.4x6.5mm_P0.65mm

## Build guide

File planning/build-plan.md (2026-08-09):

# GuitarDAWLiteOS — Build Plan & Task Tracker

**Phase 1 scope:** bare-metal Pi 5, I²S capture+playback (PCM1808 ADC + PCM5102A DAC), SD recording, HDMI framebuffer UI, GPIO footswitch. No USB in the audio path.
**Foundation:** [Circle](https://github.com/rsta2/circle) (GPLv3), `RASPPI=5`, `kernel_2712.img`.
**This plan supersedes the research doc's Build Sequence** where they conflict — corrections from [claim-verification.md](../docs/claim-verification.md) are folded in and flagged `[CORR-n]`.

Legend: `[ ]` todo · `[~]` in progress · `[x]` done · `[!]` blocked/risk.
Effort: S ≤ half-day · M ~1–2 days · L ~3–5 days.

---

## Milestone 0 — Toolchain & first boot
**Status: ✅ COMPLETE — first physical boot 2026-07-10** (Pi 5 2GB, revision `b04170`): the M3 kernel booted first try over HDMI, all 4 cores up, thermal loop live. See [docs/build-setup.md](../docs/build-setup.md).

- [x] **0.1 Cross-compile environment** (S) — `aarch64-elf-gcc 16.1.0` + binutils 2.46.1 via Homebrew (`brew install aarch64-elf-gcc aarch64-elf-binutils`), prefix `aarch64-elf-`. (Circle's blessed `aarch64-none-elf` 15.2.Rel1 is the fallback if an addon link-fails.)
- [x] **0.2 Clone & configure Circle for Pi 5** (S) — `develop` pinned to `22722a76` at `circle/`; `./configure -r 5 -p aarch64-elf- -f` → `RASPPI=5/AARCH=64`. **Core lib + `sample/03-screentext` built & linked clean → `kernel_2712.img` (108 KB).** Reproducible via `scripts/build.sh`.
- [x] **0.3 SD boot card** (S) — GDAWBOOT card (FAT32/MBR) flashed with [`sdcard/`](../sdcard/) contents, byte-verified. **Booted 2026-07-10.** Note: `config.txt` carries `device_tree_address=0x2000000` (keeps the firmware's DTB placement clear of the 16 MB kernel region) — build.sh preserves it.
- [x] **0.4 UART debug console** (S) — boot log shows `Serial: OK` alongside the screen (log target tty1); the documented `cmdline.txt.uart` switch stays available when a headless session needs it.

**Gate: ✅ PASSED** — boot log over HDMI, timestamped, all subsystems reporting.

---

## Milestone 1 — De-risking spikes (do these BEFORE wiring the full audio board)

These two spikes retire the highest-uncertainty items surfaced by verification. Cheap to do; expensive to discover late.

- [x] **1.1 `[SPIKE A]` RP1 peripheral access smoke test** (S) — **passed 2026-07-10, by a stronger proof than planned:** the first hardware boot ran the full M3 I²S0 engine (RP1 DMA + RP1 pin muxing) with stock `config.txt` — capture counted exactly 48,000 frames/s, confirming RP1 peripherals are fully live on entry to `main()`. Confirms `[CORR-3]` on our board/firmware.
- [ ] **1.15 `[SPIKE C]` Display-only + controls bring-up** (M) — *(re-scoped 2026-07-23: touch DROPPED — UI = 5 rotary encoders + sustain pedal + plain display)*. Build `sample/28-touchscreen` with `DSI_DISPLAY=0` and **`bEnableTouch=FALSE`** on the Touch Display 2 as a display-only panel (GT911 never powered; zero 40-pin GPIOs holds), then `addon/lvgl/sample` with **90° software rotation** and **LVGL encoder-group navigation**. Plus the input spike: 5× EC11/KY-040 quadrature + pedal read via one `CGPIOPin::ReadAll()` at a 2 kHz core-3 tick (transition-table decode, Schmitt on, boot auto-polarity for the pedal — [retro-deck-design.md](../docs/retro-deck-design.md) §1/§1b). Gates the faceplate cutout. Fallback: plain HDMI (already proven live).
- [x] **1.2 `[SPIKE B]` 12.288 MHz MCLK generation** (M) `[CORR-4]` **← highest-value spike — internal route ruled out 2026-07-09, resolved via external generator, frequency confirmed 2026-07-09.** The originally-planned `clk_i2s → clk_gp0 → GPIO4` route doesn't work: `clk_i2s` is a single physical clock generator already claimed exclusively by Circle's I²S peripheral for BCLK (`64fs` = 3.072 MHz @ 48 kHz, the whole time audio runs) — MCLK needs `256fs` = 12.288 MHz, 4× that rate, from the same block, at the same time. No other RP1 clock generator has `pll_audio` as an available parent either. Full writeup: [docs/claim-verification.md](../docs/claim-verification.md).
  - **Resolution:** generate MCLK **off-chip** on an **Arduino Nano ESP32** (ESP32-S3), wired directly to PCM1808 SCKI, independent of the Pi 5's `pll_audio`. Firmware: [esp32-mclk/](../esp32-mclk/). Note: ESP32-S3 has **no** dedicated Audio PLL (APLL is original-ESP32-only, confirmed against the installed SDK's `soc/clk_tree_defs.h`) — an earlier version of this note wrongly assumed it did. It uses the general-purpose `PLL_160M` source instead, via the ESP-IDF `i2s_std` driver's `mclk_multiple` config.
  - **Verified:** no scope on hand, so measured with the chip's own PCNT (pulse counter) peripheral instead — a self-test mode in the same firmware loops the MCLK pin (D2/GPIO5) back into a counter pin (D3/GPIO6) via a jumper and prints the measured frequency once a second. Result: **12.2880 MHz**, exact match to target, repeatable across multiple readings (some readings undercounted from a loose self-test jumper, not the generator — readings were exact whenever the jumper made solid contact). This confirms frequency correctness; it does **not** characterize jitter/duty-cycle, which still needs a real scope if that level of verification ever becomes necessary — not expected to matter for a consumer-grade ADC per `[CORR-4]`/E2.

**Gate:** ✅ met — the Nano ESP32's output pin carries a correct 12.288 MHz MCLK, confirmed via the firmware's own PCNT self-test (see above). Wire it to the PCM1808 whenever Milestone 2 hardware is on the bench.

---

## Milestone 2 — Hardware bring-up: I²S loopback
**Full electrical review + wiring diagram done:** [docs/hardware-review.md](../docs/hardware-review.md), [docs/wiring-diagram.svg](../docs/wiring-diagram.svg). Key additions beyond the pin map below: PCM1808 needs a **5 V analog rail** (not 3.3 V), a **guitar front-end** (buffer → ×3 gain → bias-to-VBIAS mid-rail → AA) is mandatory, op-amp runs on 5 V, no level shifters. Analog rail off header 5 V (**never** header 3V3 *for analog*); ADC digital VDD from header **pin 1 direct** — the CJMCU breakout has no onboard regulator and the "local LDO" applies only to the KiCad bare-chip board. **For the permanent soldered build see [solder-build.md](../docs/solder-build.md), which freezes every open choice.** **Buildable schematic** ([docs/schematic.md](../docs/schematic.md), SPICE-verified + ERC-reviewed), **KiCad netlist + symbols** ([kicad/](../kicad/), bare-chip, ERC-checked), and a **breadboard build guide** ([docs/breadboard-build.md](../docs/breadboard-build.md)) are done.

**Pin map (updated 2026-07-10 — ADC is the bus master; see claim-verification.md and [docs/adc-hookup.md](../docs/adc-hookup.md)):**

| Source | Signal | Direction | Connects to |
|---:|---|---|---|
| **PCM1808 BCK** | BCLK 3.072 MHz | **ADC → Pi + DAC** | Pi GPIO18, PCM5102A BCK |
| **PCM1808 LRCK** | LRCLK/FS 48 kHz | **ADC → Pi + DAC** | Pi GPIO19, PCM5102A LCK |
| PCM1808 DOUT | data **IN** (capture) | ADC → Pi | Pi GPIO20 |
| Pi GPIO21 | data **OUT** (playback) | Pi → DAC | **PCM5102A DIN** |
| **Nano ESP32 D2/GPIO5** | MCLK/SCKI 12.288 MHz | ESP32 → ADC | **PCM1808 SCKI** only |

The **PCM1808 is I²S master** (divides SCKI to BCK/LRCK); the Pi runs slave (`GDAW_I2S_SLAVE`, Circle RP1 **I2S1** instance, same GPIO18-21 pads via AltFn4). Rationale: two free-running crystals can't stay fs-locked; the chip's §7.4.2 resync would mute audio continuously in the Pi-master arrangement. `[CORR-2]` SD and HDMI are on the BCM2712 and independent of this bus.

- [ ] **2.1 PCM1808 strapping** (S) — **before power-on**: **MD1=HIGH, MD0=HIGH (MASTER, 256fs → SCKI/256 = 48 kHz)**, FMT=GND (I²S, 24-bit). SCKI←**Nano ESP32 D2**, BCK→Pi GPIO18, LRCK→Pi GPIO19, DOUT→Pi GPIO20. Board-specific pin table (purple CJMCU-1808 breakout: no onboard regulator — both 5 V and 3.3 V rails required; analog in = RIN/–/LIN edge pads): [docs/adc-hookup.md](../docs/adc-hookup.md).
- [ ] **2.2 PCM5102A (GY-PCM5102 module) strapping** (S) `[CORR-5]` — solder pads: FLT=L, DEMP=L, **XSMT=H (UNMUTE — the #1 silent-output gotcha)**, **FMT=L (I²S)**. SCK→GND (internal PLL; no MCLK needed). DIN←GPIO21, BCK←GPIO18, LCK←GPIO19. Power per module (3.3 V).
- [ ] **2.3 Playback smoke test** (S) — run Circle `sample/34-sounddevices` (I²S/PCM5102A) on Pi 5; confirm a test tone out of the PCM5102A. Validates `[CORR-5]` strapping + BCLK/LRCLK.
- [ ] **2.4 Capture smoke test** (M) — run/adapt Circle `sample/42-soundinput`; confirm the PCM1808 produces non-zero samples (depends on Spike B MCLK). Format is fixed standard-I²S 24-in-32 `[CORR C3]` — no format selection to get wrong.
- [ ] **2.5 Hardware I²S loopback** (M) — full-duplex `DeviceModeTXRX`: capture ADC → write straight to DAC. Confirms simultaneous in+out on the single **I²S1 (slave)** instance (post-pivot; `GDAW_I2S_SLAVE`).

**Gate:** clean tone in (PCM1808) → out (PCM5102A) with no dropouts.

---

## Milestone 3 — Audio engine core
**Status 2026-07-10: engine verified live on hardware** (no codecs yet). First boot ran the full engine: `I2S full duplex (TXRX): RUNNING`, capture counting **exactly 48,000 frames/s**, `starve` frozen at the one-time 16-frame startup priming, `drop 0`, `laps 0/0` (no ring overruns), storage drain at exactly 384 KB/s in 256 KB blocks, 48+ s observed clean. Remaining for the gate: real audio through real codecs (M2 wiring) + the 10-min soak. Source: [src/](../src/), host tests: [tests/](../tests/).

- [~] **3.1 Live monitor path** (M) — **implemented** in [src/audioengine.cpp](../src/audioengine.cpp): full-duplex `DeviceModeTXRX` on one `CI2SSoundBaseDevice` (the `test/sound-controller/soundshell.cpp` pattern — the only TXRX usage in the Circle tree), overriding `GetChunk`/`PutChunk` directly (lowest-latency path; both run on core 0 in DMA-completion IRQ context under the driver's spinlock). Chunk = 32 words = 16 frames = 333 µs → worst-case in→out ≈ 3 chunks = **1.0 ms**, inside the 0.67–1.33 ms target. Key driver contract honored: `GetChunk` must always return the full word count (returning short permanently stops the stream); starve/drop counters are the only underrun visibility (the RP1 cyclic DMA has none in hardware).
- [~] **3.2 Lock-free SPMC ring buffer** (M) — **implemented + host-verified** in [src/ringbuffer.h](../src/ringbuffer.h): single producer broadcasting to independent per-reader cursors, wait-free writer (never inspects readers, overwrites oldest), seqlock-style **reserve/commit index pair** for torn-read detection. The first version validated against the commit index only — the host stress test caught real torn reads (writer scribbles payload before publishing); the reserve index fixed it. [tests/ringbuffer_test.cpp](../tests/ringbuffer_test.cpp) passes clean under plain `-O2` and ThreadSanitizer (1 writer + 3 readers, 20 M words, forced overruns, zero corruption). Freestanding-safe: no std headers, GCC `__atomic` builtins only (no `<atomic>` in Circle's `-nostdinc++` build; no libc `<string.h>` either — that one silently broke the build via the `-MG` dep-file trap).
- [~] **3.3 Multi-core assignment** (S) — **implemented** in [src/cores.cpp](../src/cores.cpp): Core 0 = I²S IRQ callbacks + thermal/heartbeat loop (M0 behavior retained); Core 1 = analysis (level meter now, YIN in M6); Core 2 = storage drain in 256 KB blocks (FatFs lands in M4 — FatFs is spinlock-guarded but must never be called from IRQ); Core 3 = 2 s stats reporter (UI in M5). Workers hold on an atomic start flag until core 0 releases them. **Build-critical:** `ARM_ALLOW_MULTI_CORE` changes `CSpinLock`'s class layout and atomic strength, so it must cover the whole Circle tree — [scripts/build.sh](../scripts/build.sh) appends it to `Config.mk` and forces a clean lib rebuild the first time.

**Adversarial review (2026-07-10), applied:** a multi-agent review of the M3 code found one **critical boot-blocker** — the 4 MiB BSS ring pushed the kernel past Circle's default `KERNEL_MAX_SIZE` (2 MB), which would have put all four cores' stacks *inside* the ring buffer: a silent, pre-output boot crash on first hardware boot, invisible in the 146 KB `.img` (BSS is NOBITS). Fixed tree-wide with `-DKERNEL_MAX_SIZE=0x1000000` in `Config.mk` + a whole-tree clean rebuild, and [scripts/build.sh](../scripts/build.sh) now has a **post-link guard** (fails if `_end` ≥ `MEM_KERNEL_END`). Also applied: `src/*.o` now depend on `Config.mk` (stale-object trap), DEFINE/toolchain changes force a whole-tree clean (poisoned-archive trap that would otherwise bite at M4 when FatFs libs get linked), SD staging verifies the boot-critical DTBs/cmdline exist, and the ring tests gained a deterministic overrun/resync test, an exact value==absolute-index integrity invariant, anti-vacuous-pass assertions, and bounded-drain hang detection. `SignExtend24` was also corrected to the low-24-bit wire format (Circle `ConvertReadSoundFormat` + `GetRangeMin/Max` = ±(2²³−1) are the evidence).

**Gate (unchanged, needs hardware):** stable real-time monitor mix, measured latency, zero underruns over 10 min.

---

## Milestone 4 — SD recording

- [ ] **4.1 FatFs integration** (S) `[CORR F1]` — use Circle `addon/fatfs` (FatFs R0.16, 1-clause BSD) on **`CEMMCDevice`** (BCM2712 SDHCI @ `0x1000FFF000` — *not* `CSDHCIDevice`, *not* RP1).
- [ ] **4.2 Background block-write queue** (M) — Core 2 drains the ring buffer in large DMA-aligned blocks (64–256 KB) → `f_write`. Never write per-interrupt. Budget: 288 KB/s/track, 1.15 MB/s ×4, ~8.7× headroom on Class-10 `[CORR F3]`.
- [ ] **4.3 Session file format** (S) — `/sessions/session_NNN/{session.json, track_NN.pcm (24-bit signed interleaved 48k), notebook.txt}`; reserve `tabs/` for Phase 2.
- [ ] **4.4 Safe shutdown** (S) — GPIO power-button IRQ / watchdog flushes open handles. Raw PCM loss on crash = acceptable; JSON corruption = not.

**Gate:** record 4 tracks simultaneously for 10 min, files intact, re-importable.

---

## Milestone 5 — Display & UI

- [ ] **5.1 Framebuffer init** (S) `[CORR G1]` — `CBcmFrameBuffer` / `CScreenDevice` via VideoCore mailbox (not `CFrameBuffer`). 1024×600 or 1280×800, 32-bit. Wired HDMI ≤1080p avoids the "limited" caveats.
- [ ] **5.2 Waveform renderer** (L) — per pixel column, draw min→max peak of the sample window. Core 3, ~30 fps.
- [ ] **5.3 Session timeline UI** (M) — tracks, transport, record/play state.

**Gate:** live waveform + transport render at 30 fps with no audio impact.

---

## Milestone 6 — Guitarist tools

- [ ] **6.1 Tuner (YIN)** (M) `[CORR-6]` — **clean-room reimplement YIN from the 2002 JASA paper** (do *not* ship `ashokfernandez/Yin-Pitch-Tracking` as MIT — it's unlicensed). **No patent barrier** (FR2825505B1 expired). 2048-sample window @ 48k on Core 1 (~0.5–2 ms). Difference fn → CMND → threshold (0.1–0.15) → parabolic interp.
- [~] **6.2 Tuning-aware display** (S) — **implemented + host-verified** in [src/tuning.h](../src/tuning.h): open-string freq tables (Standard E, Drop D, DADGAD, Open G, Open D, D Standard — equal temperament, A4=440 Hz) plus `NoteFromFrequency()` (chromatic nearest-note + signed cents off a measured Hz) and `NearestString()` (nearest open string within a specific tuning, compared in cents so tunings that repeat a note across octaves — e.g. DADGAD's three D strings — aren't confused by note name alone). Freestanding-safe (`<stdint.h>`/`<math.h>` only, no libc++), same as ringbuffer.h/audiostats.h, so it also compiles host-side: [tests/tuning_test.cpp](../tests/tuning_test.cpp), wired into [tests/run-tests.sh](../tests/run-tests.sh). Not yet wired to a caller (needs 6.1's YIN output) or the display (M5).
- [ ] **6.3 Metronome** (S) — sample-accurate click mixed into the DAC on Core 0.
- [ ] **6.4 BPM tap + scale/chord/interval reference** (S) — static data, no audio dependency.
- [ ] **6.5 Session notebook** (S) — text buffer → `notebook.txt`.
- [ ] **6.6 Controls input handler** (M) — 5× rotary encoders (A/B/SW) + sustain-pedal footswitch: one `ReadAll()` bank read per 2 kHz core-3 tick, quadrature transition table + 10 ms switch debounce, SPSC event queue to the UI; pedal polarity auto-calibrated at boot (Yamaha FC-series is normally-closed — [retro-deck-design.md](../docs/retro-deck-design.md) §1b). Map: knobs = trim/level/loop-select/feedback/menu (draft), pedal = record/overdub tap · double-tap stop · hold clear.

**Gate:** tuner locks E2–E6 accurately; metronome sample-accurate; footswitches drive modes.

---

## Risk register (from verification)

| Risk | Severity | Status | Mitigation |
|---|---|---|---|
| Internal GPCLK MCLK route infeasible (`clk_i2s` shared with BCLK) `[CORR-4]` | High | **Mitigated 2026-07-09** | External MCLK: Arduino Nano ESP32 (ESP32-S3, **PLL_160M via `i2s_std`** — the S3 has *no* APLL) → PCM1808 SCKI, decoupled from Pi 5 `pll_audio` |
| PCM5102A XSMT shipped muted `[CORR-5]` | Med | Open | Verify XSMT=H pad at 2.2 |
| Accidentally adding `pciex4_reset=0` w/ Circle `[CORR-3]` | Low | Mitigated | Stock `config.txt`; documented |
| Shipping unlicensed YIN/board files `[CORR-6]` | Med (legal) | Mitigated | Clean-room YIN; simplecodec3 = study-only |
| Pi 5 framebuffer "limited" caveats `[CORR G1]` | Low | Mitigated | Wired HDMI ≤1080p |
| GPLv3 obligation (Circle) | Low | Accepted | Personal/open-source project |

## Dependencies pinned
- Circle `develop` @ `22722a7` (2026-06-08), `RASPPI=5` → GPLv3
- FatFs R0.16 (`addon/fatfs`) → 1-clause BSD
- YIN → clean-room from JASA 2002 (patent expired; no repo dependency)
- Hardware: PCM1808 (slave, strap-only) + PCM5102A/GY-PCM5102 (strap-only) — no driver code
- Hardware: Arduino Nano ESP32 (ESP32-S3) — external MCLK generator only, no data/BCLK/WS connection to Pi 5

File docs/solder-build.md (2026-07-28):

# M2 Audio Board — FINALIZED SOLDER SPEC

**Status: frozen 2026-07-28.** This is the single authoritative document for the permanent
soldered M2 audio board. Every value here is decided — nothing is gated on a later measurement,
nothing says "optional", nothing says "or". Where an earlier doc defers a choice, **this file
overrides it**.

**Build style (confirmed with Michael 2026-07-28):** breadboards are layout aids only; this is a
solder-first build. Modules are **soldered directly to perfboard**, not socketed. Front-end rail
stays **9 V** (no 12 V output available on the Gator).

Supersedes, where they conflict: `adc-hookup.md` (the "measure first" gate), `breadboard-build.md`
(single shared 5 V rail), `hardware-review.md` (ferrite filter, LDO option), `schematic.md`
(rev-A netlist — already bannered), `build-plan.md:39` (the "local LDO" line).

Prior review basis: [2026-07-21](reviews/2026-07-21-m2-bench-adversarial-review.md) ·
[2026-07-28 schematic review](reviews/2026-07-28-schematic-wiring-review.md) · plus a 19-agent
pre-solder freeze audit and a fresh ngspice re-verification of the front-end.

---

## ⛔ STOP — three things to do before the iron is hot

These are the irreversible ones. Because the modules are soldered down, each of these becomes a
desoldering job if you skip it.

### S1. Prove the I²S **slave** path boots — it has never run on this hardware

This is the single biggest risk in the build and it is not a wiring question.

The one recorded successful audio boot (`de2fb53`, 2026-07-10) ran the **master-mode** kernel —
it predates the clock pivot (`f524c7d`) that introduced `GDAW_I2S_SLAVE`. The log it recorded,
`I2S full duplex (TXRX): RUNNING`, does not even have the slave suffix the current kernel prints.
So **RP1 I2S1, AltFn4, slave clocking has never once executed on this Pi.** Every wire you are
about to make permanent assumes it works.

Do a temporary clip-lead hookup of the ADC first — Nano MCLK, the four I²S lines, both rails,
ground — and boot the current image. Pass criteria, both required:

```
I2S full duplex (TXRX, slave - ADC masters the bus): RUNNING
```
and the `gdawcores` stats line showing `cap` climbing by ~48,000/s between two 2-second reports.

If `cap` stays frozen at 0, **do not solder** — see D2 below, then the debug ladder.

### S2. Set the GY-PCM5102's config pads **before** the module goes down

The four config pads (FLT / DEMP / XSMT / FMT) are on the module's **underside** and ship bridged
**all-low**. XSMT low = **permanently muted DAC**. Once the module is soldered flat to perfboard
you cannot reach them.

They are 3-way pads (H island — centre — L island). Setting a pad high is **two operations**:

1. Wick away the factory **centre→L** bridge.
2. Bridge **centre→H** only. *Never bridge H to L — that shorts the module's 3.3 V to ground.*

| Pad | Set to | Meaning |
|-----|---|---|
| FLT | **L** (leave factory bridge) | normal filter roll-off |
| DEMP | **L** (leave factory bridge) | de-emphasis off |
| **XSMT** | **H** — wick centre→L, bridge centre→H | **UNMUTE. The #1 silent-output gotcha.** |
| FMT | **L** (leave factory bridge) | I²S format |

Verify with a meter **before mounting**: XSMT centre reads ~0 Ω to the module's 3.3 V node and
open to GND; FLT / DEMP / FMT centres each read ~0 Ω to GND. Also confirm `SCK` (a header pin, not
a pad) will be tied to GND.

> Set by **chip pin**, not by pad number, if there is any doubt: XSMT = PCM5102A pin 17,
> FMT = 16, FLT = 11, DEMP = 10. The H1L…H4L position map in `hardware-review.md:88-95` comes from
> third-party wikis, not the datasheet.

### S3. Meter the CJMCU-1808's straps and analog pads before wiring them

`adc-hookup.md:126` warns that some batches ship with wrong solder jumpers — but it buries this in
the *debug* ladder, i.e. after the board is built. Do it first, module unpowered and in your hand:

- **MD0, MD1, FMT to GND** must each read **~50 kΩ** (the chip's internal pulldowns). A reading
  near **0 Ω** means that pin is factory-bridged to ground and cannot be strapped high — that
  module will never master the bus. Reject it.
- **Analog pads (RIN / – / LIN):** the documented order is single-source and reverse-engineered.
  Ohm each of the three edge holes to a module GND header pin — **the one reading ~0 Ω is "–"**.
  The outer two are the inputs. Confirm which outer pad is LIN before soldering the front-end to it.

---

## 1. Nets — the complete solder list

Seven wires to the Pi, and that is all that touches J8.

| Net | From | To | Notes |
|-----|---|----|----|
| `MCLK` | Nano **D2** → **33 Ω** | ADC **SCK** | 12.288 MHz. Twist with its own ground return. |
| `BCLK` | ADC **BCK** → **100 Ω** | Pi **J8 p12** (GPIO18) **and** DAC **BCK** | 3.072 MHz, **ADC drives**. Two wires out of the ADC pin — star at the source, do not daisy-chain. |
| `LRCLK` | ADC **LRC** → **100 Ω** | Pi **J8 p35** (GPIO19) **and** DAC **LCK** | 48 kHz, **ADC drives**. Same star-at-source rule. |
| `CAPDAT` | ADC **OUT** | Pi **J8 p38** (GPIO20) | capture data |
| `PLAYDAT` | Pi **J8 p40** (GPIO21) | DAC **DIN** | playback data |
| `+5V_RAW` | Pi **J8 p2** | DAC **VIN** | **direct — never through the 10 Ω** |
| `+5V_ADC` | Pi **J8 p2** → **10 Ω** | ADC **+5V** | ADC analog only. See §2. |
| `+3V3` | Pi **J8 p1** | ADC **3.3** pin, ADC MD0, ADC MD1 | direct wire, no regulator, no series R |
| `GND` | star island | Pi **J8 p6** | one wire. See §3. |

**Straps** (set before power-on; tie directly, no series resistors — the internal 50 kΩ pulldowns
mean any series R above ~20 kΩ reads LOW = slave = dead bus; each strapped pin draws ~66 µA):

- ADC **MD0 → +3V3**, **MD1 → +3V3** (master, 256 fs), **FMT → GND** (I²S).
- DAC **SCK pin → GND** (hard tie, shortest link — internal PLL locks off BCK).
- DAC pads per **S2**.

### Why the 100 Ω on BCK and LRCK

`circle/lib/sound/i2ssoundbasedevice-rp1.cpp:164-165` selects the GPIO mode from a single boolean:
`m_bSlave ? GPIOModeAlternateFunction4 : GPIOModeAlternateFunction2`. In **non**-slave mode
GPIO18/19 become **push-pull outputs** — driving straight into the PCM1808's own push-pull clock
outputs. One wrong SD card, one stale kernel image, one undefined `GDAW_I2S_SLAVE`, and you have
two CMOS drivers fighting on a permanent board.

100 Ω at the **ADC pin end** caps that contention at ~16 mA per line. Cost: ~2.5 ns RC into ~25 pF
of pad and wire, against a 325 ns bit period. It buys damage protection for nothing.

---

## 2. Power — the 5 V rail splits into two branches

This is the change most likely to be got wrong, because every older doc draws **one** shared 5 V rail.

```
Pi J8 p2 (5 V) ──┬──────────────────────────────────► DAC VIN        (branch A, ~25 mA, RAW)
                 │
                 └── 10 Ω ──┬── node A ─────────────► ADC "+5V"      (branch B, ~9 mA, FILTERED)
                            │
                            ├── 470 µF / 16 V ──► star   (watch polarity)
                            └── 0.1 µF X7R ─────► star   (both physically AT the ADC's +5V pin)

Pi J8 p1 (3.3 V) ───────────┬──────────────────────► ADC "3.3" (VDD)
                            ├──────────────────────► ADC MD0, MD1 straps
                            └── 0.1 µF X7R ────────► star (at the ADC's 3.3 pin, leads < 10 mm)
```

**Never run the DAC through the 10 Ω.** Both loads together are 34 mA → 340 mV drop → ADC VCC
**4.41 V** on a −5 % sagged header, **below the PCM1808's 4.5 V minimum**. Worse, the DAC's
charge-pump current pulses would land on the rail the ADC uses as its *ratiometric* reference
(FS = 0.6·VCC), which is the exact mechanism the filter exists to stop.

Branch B alone: 9 mA × 10 Ω = **90 mV**, VCC ≈ 4.91 V. Comfortable.

**The filter is unconditional.** `adc-hookup.md:74` says "before adding parts, measure" — that
gate is unrunnable here, because the silence-FFT it calls for needs a working capture path, which
needs the soldered board. Build it in; run the FFT afterwards as verification, not as a gate.

**No ferrite, no LDO.** The Würth 74275022 beads are optional RF hygiene only — a ferrite alone is
≈0 dB in-band against this mechanism. The "optional local 3.3 V LDO" in `hardware-review.md` and
`build-plan.md:39` is **closed**: ADC VDD runs from J8 p1 direct. The "not header 3V3" rule in
those docs applies to the **analog** rail only and lost its qualifier.

---

## 3. Ground — build a real star island

Every doc names "Pi J8 pin 6" as the star. That is an *electrical* node, not a *physical* one, and
up to eight conductors are ordained to land on it. You cannot solder eight wires to one 0.1″
header pin.

**Build the star as a copper island on the board:** a length of bare 18–20 AWG solid wire (or
copper tape) bridging one contiguous perfboard row, ~25–40 mm, sited next to the ADC. Everything
returns there. **Exactly one** wire leaves the island for Pi J8 p6, kept short.

Tie order along the island, quietest first, closest to the ADC:

1. ADC `–` input-reference pad, and the ADC's **left** GND header pin
2. ADC decoupling returns (the 470 µF, both 0.1 µF)
3. ADC **right** GND header pin → this one is the origin of the return conductor bundled with the
   BCK/LRC/OUT wires *(use **both** ADC GND pins — the old "either one, one is enough" note
   predates the paired-return mandate and contradicts it)*
4. MCLK paired return (twisted with the D2 wire), and the Nano's second, separate ground
5. DAC GND
6. CopperSound 9 V-domain ground
7. → the single spoke to Pi J8 p6

Paired/twisted HF returns beside MCLK and the clock bundle are **required** and are *not*
forbidden "ground islands" — that wording is retired. The one-point rule is a **DC** rule.

---

## 4. Front-end — 9 V, values unchanged, one part added

**Keep every existing value.** `R1 = 10 k`, `R2 = 12 k` (VBIAS 4.91 V), `Rbias = 1 M`,
`Cin = 0.1 µF`, `Rg = 10 k`, `Rf = 10 k + trim`, `Cout = 1 µF`, **`Rs = 1 k`**, `Ca = 1 nF`.

**Add `C_byp` = 100 µF electrolytic ∥ 0.1 µF ceramic at U1 pin 8 → GND.** Mandated since the
2026-07-22 review but missing from the schematic sheet until today. Without it, VBIAS ripple is
*inverting-amplified* by Rf/Rg (−16.9 dB at max trim ≈ −66 dBFS of hum).

> **`Rs` stays 1 kΩ.** The "1 k → 1.5 k" upgrade was floated as optional and was **rejected on
> review**: 1 k is stated identically in nine places across every wire-from doc, both schematic
> sheets, and both SPICE decks. Changing only some of them desynchronizes the set for a margin
> improvement nobody needs.

### The headroom finding — set your trim accordingly

Re-verified in ngspice today (tanh macromodel validated against the repo's own deck to 5 significant
figures). **On 9 V there is no bias point that satisfies both constraints:**

| VBIAS | Output swing (guaranteed-min part) | JFET input CM floor |
|---|---|---|
| ≥ 4.5 V required | ≤ 4.5 V required | — |

The window is exactly zero wide. The as-built 4.91 V deliberately favours the **input common-mode**,
and that is the right call — CM violation on a TL07x means **phase inversion**, a far nastier
failure than clipping. Do **not** "fix" this by moving to 10 k/10 k.

The cost, measured:

| Part | Peak before op-amp clips | Usable level at the ADC |
|---|---|---|
| typical (swings 1.5 V from rail) | 6.41 V — no clip | full scale reachable |
| **guaranteed-min** (3.0 V from rail) | **6.00 V — clips** | **−2.9 dBFS**, positive peaks only |

**So: set the gain trim so hard strums peak at −6 dBFS.** You have comfortable margin there on any
part, and you should be tracking at −6 dBFS anyway. The docs' old unqualified "no clip even at
1.6 Vpp overdrive" was a *typical*-part result mislabeled as worst-case.

*(If a 12 V supply ever becomes available: change R2 12 k → 10 k for a 6.0 V mid-rail and every
constraint passes with 1.5 V margin, at zero cost in level. One resistor.)*

---

## 5. Nano ESP32 — reflash before mounting

Two firmware changes are already applied in [`esp32-mclk/esp32-mclk.ino`](../esp32-mclk/esp32-mclk.ino).
**Flash this version before the board goes in.**

1. `StartMclk()` moved to the **first** line of `setup()`. It previously ran after
   `Serial.begin()` + `delay(2000)`, leaving a **2-second dead-MCLK window on every reset,
   brownout and USB re-enumeration** — and interrupting SCKI auto-powers-down the PCM1808.
2. The two `ESP_ERROR_CHECK`s in `loop()` are now soft errors. `ESP_ERROR_CHECK` **panics and
   reboots**, which would drop the clock for the whole rig because a *diagnostic* counter hiccuped.

**Keep the D2→D3 link permanently** (tap on the Nano side of the 33 Ω, so the counter reads the
source while the resistor still damps the run to the ADC). `adc-hookup.md:99` says remove it —
that is right for a bench jumper and wrong here. On a soldered board with no scope, the sketch's
1 Hz `Measured MCLK: 12.2880 MHz` print is your **only** continuous proof the clock root is alive.

The Nano keeps its own USB-C supply. Mount it with the USB-C port overhanging the board edge and
put a cable-tie anchor behind it — that connector is now a permanent part of the system.

---

## 6. Parts you do not have yet

Verified against `parts-order.md` — **none of these are in any BOM in the repo.** A solder session
is one sitting; a missing 12 k stops it.

| Qty | Part | For |
|----:|---|-----|
| 10 | **12 kΩ** ¼ W metal film | **R2, the as-built VBIAS divider.** `parts-order.md:55` runs 1 M / 10 k / 5.6 k / 3.9 k / 1 k / 470 Ω — 12 k was never ordered |
| 10 | **100 Ω** ¼ W metal film | BCK + LRCK contention protection (§1) |
| 10 | **33 Ω** ¼ W metal film | Nano D2 series (§1) |
| 10 | **10 Ω** ¼ W metal film | analog-5 V RC (§2) |
| 4 | **470 µF / 16 V** low-ESR radial | analog-5 V RC bulk (§2) |
| 4 | **100 µF / 16 V** radial | `C_byp` at TL072 pin 8 (§4) |
| 20 | **0.1 µF X7R** ceramic | ADC VCC + VDD decoupling, `C_byp` HF half |
| 1 | 2×20 female header **or** IDC socket + ribbon | the only Pi J8 interface |
| 1 | 3.5 mm or ¼″ PCB-mount jack | front-end cable lands here |
| — | FR4 perfboard | prefer a **Perma-Proto-style board with etched power rails** — the rails give you the §3 star island for free and transfer your breadboard layout 1:1 |

---

## 7. Design in test points now

In slave mode `RunI2S()` has **no failure path** — its only `return FALSE` sits inside
`if (!m_bSlave)`. `Start()` returns TRUE with the ADC unpowered, unclocked, or miswired. At least
six distinct faults all produce the identical symptom: `cap` frozen at 0.

Solder an **8-way 0.1″ test header** before you mount the modules, tapping **SCKI, BCK, LRCK,
DOUT, DIN, +3V3, +5V, GND**. Put the SCKI/BCK/LRCK taps on the **ADC side** of the series
resistors so you measure what the chip actually sees. This is the cheapest thing in the build and
the difference between a five-minute diagnosis and pulling a soldered module.

---

## 8. Build order

1. **S1, S2, S3** above. Do not skip.
2. Perfboard: 2×20 header, then the §3 ground island, then the two 5 V branches and the 3.3 V wire.
3. Test header (§7).
4. ADC down: straps first (MD0/MD1 → 3V3, FMT → GND), then decoupling at its pins, then the four
   I²S lines with their series resistors and paired returns.
5. DAC down (pads already set per S2): VIN from raw 5 V, SCK → GND, BCK/LCK/DIN.
6. Front-end: `C_byp` at U1 pin 8, then Rs + Ca **at the ADC LIN pad**, not on the pedal board.
7. Nano: reflashed per §5, 33 Ω in the D2 lead, two ground wires, D2→D3 link kept.

**Power-up order: Nano → Pi → Gator 9 V. Power down in reverse.** Kill all three before touching
any wire. Nano-first is verified safe (PCM1808 SCK/MD/FMT inputs are rated −0.3…+6.5 V independent
of VDD).

**First boot expectation:** `I2S full duplex (TXRX, slave - ADC masters the bus): RUNNING`, `cap`
climbing ~48,000/s, `starve`/`drop`/`laps` at 0, `peak %` responding when you play.

---

## 9. If capture is dead — diagnosis step 0

Before suspecting a solder joint, check this. `write32(m_ulBase + CCR, 0x10)` — the register that
sets the I²S word-select size to 32 bits — sits **inside `if (!m_bSlave)`** at
`i2ssoundbasedevice-rp1.cpp:373-381`. In the as-built slave configuration **it is never written**,
so CCR keeps its reset value.

If the bus clocks are confirmed good at the test points (SCKI 12.288 MHz, BCK 3.072 MHz, LRCK
48 kHz) but `cap` is frozen or the data is misaligned, move that `write32` outside the `if` block,
rebuild and retry. It is harmless in master mode — the same value the master path already writes.

Then the normal ladder: SCKI wire → Nano power → MD0/MD1 straps (both must be HIGH or the ADC
never masters the bus) → LIN wiring → front-end power → `–` pad grounded.

---

*Frozen by Claude Code, 2026-07-28. Front-end numbers re-verified in ngspice-46 against a
macromodel validated to the repo's own published results. Firmware claims verified against the
Circle and `esp32-mclk` sources and the git record.*

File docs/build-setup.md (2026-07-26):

# GuitarDAWLiteOS — Build Setup, Flash & UART Guide

Records the working build environment (Milestone 0) and the hands-on steps to boot it on a Pi 5.

## Environment (verified working 2026-06-29, this Mac)
- **Host:** macOS 27 (arm64), GNU Make 3.81, Homebrew 6.0.5.
- **Toolchain:** `aarch64-elf-gcc` **16.1.0** + `aarch64-elf-binutils` (`ld` 2.46.1), via `brew install aarch64-elf-gcc aarch64-elf-binutils`. Prefix `aarch64-elf-`.
  - Circle's *blessed* toolchain is ARM's `aarch64-none-elf` 15.2.Rel1; the Homebrew `aarch64-elf` one is the "distro toolchain" Circle says "may work — test yourself." It **does** work here (full core lib + sample built & linked clean). If a future addon (e.g. `circle-stdlib`/newlib) link-fails, fall back to ARM's [aarch64-none-elf 15.2.Rel1](https://developer.arm.com/downloads/-/arm-gnu-toolchain-downloads) and re-`configure -p aarch64-none-elf-`.
- **Circle:** `rsta2/circle`, branch `develop`, pinned to commit **`22722a76`** (the commit verification was done against), at `circle/`.
- **Config:** `circle/Config.mk` → `RASPPI = 5`, `AARCH = 64`, `PREFIX64 = aarch64-elf-`.

## Build (reproducible)
```bash
scripts/build.sh                        # builds sample/03-screentext -> kernel_2712.img, refreshes sdcard/
scripts/build.sh sample/02-screenpixel  # any other sample
scripts/build.sh --libs                 # core lib only
```
Under the hood: `./configure -r 5 -p aarch64-elf- -f` → `cd lib && make -j` → `cd <sample> && make` → copies `kernel_2712.img` + `config.txt` into `sdcard/`.
**Output of the toolchain validation build:** `kernel_2712.img`, 108 KB, from `03-screentext` (renders text to the HDMI framebuffer; inits serial @115200 too).

## SD boot partition — what goes on it
Pi 5 boots its firmware from the on-board EEPROM, so the FAT partition needs only a few files. The complete, ready set is staged in **`sdcard/`**:

| File | Purpose |
|---|---|
| `config.txt` | from Circle `boot/config64.txt`; has `arm_64bit=1` + `[pi5] kernel=kernel_2712.img` |
| `kernel_2712.img` | the Circle application (currently the `03-screentext` demo) |
| `bcm2712-rpi-5-b.dtb` | device tree, original Pi 5 |
| `bcm2712d0-rpi-5-b.dtb` | device tree, D0-stepping Pi 5 (covers newer boards) |
| `overlays/bcm2712d0.dtbo` | required D0 overlay |
| `cmdline.txt.uart` | *not active by default* — see UART section |

DTBs/overlay were pulled from the firmware revision Circle pins (`0641c5bf…`); all three validated with the `d00dfeed` device-tree magic.

## Flash it (hands-on — your part)
1. Insert the microSD in the Mac. In **Disk Utility**, erase it as **MS-DOS (FAT)**, scheme **Master Boot Record**. (≥ 2 GB card; the whole card as one FAT partition is fine.)
2. Copy the **contents** of `sdcard/` (not the folder itself) to the root of the card, preserving the `overlays/` subfolder. e.g.:
   ```bash
   cp -R guitardawliteos/sdcard/. /Volumes/<YOUR_SD_NAME>/
   ```
   (Don't copy `cmdline.txt.uart` as-is unless you want the UART console — see below.)
3. Eject, insert into the Pi 5, attach an **HDMI monitor** (≤1080p), power on.
4. **Expected first boot:** within a couple seconds the screen shows Circle log text (compile time, system notices). That confirms Milestone 0 end-to-end: firmware → device tree → `kernel_2712.img` → framebuffer.

## UART debug console (Milestone 0.4 — optional, for headless/log capture)
The HDMI default needs no extra hardware. To route the log to a serial console instead:
1. Rename the staged file on the card: `cmdline.txt.uart` → **`cmdline.txt`** (contents: `logdev=ttyS11`). On Pi 5 the serial log device is **`ttyS11`**.
2. Connect the **Raspberry Pi Debug Probe** ("**U**" port) to the Pi 5's **dedicated 3-pin UART/debug connector** (the small JST connector, *not* the 40-pin header) using the JST-SH↔JST-SH cable from the Probe box. It is **straight-through, pin 1 to pin 1** — no TX/RX swapping, the crossover is built into the connector spec. No VCC. (A generic 3.3 V USB-serial adapter also works: adapter **RX ← Pi TX**, **TX → Pi RX**, **GND ↔ GND**, VCC unconnected.)
3. On the Mac, open the console at **115200 8N1**:
   ```bash
   ls /dev/cu.usbmodem*   # the Probe is a CDC device, e.g. /dev/cu.usbmodem11402
   screen /dev/cu.usbmodem11402 115200       # (quit: Ctrl-A then k)
   ```
4. Power on; the Circle log streams over serial. (Ref: Circle `doc/bootloader.txt`, `doc/cmdline.txt`.) If the dedicated connector gives nothing, the fallback is GPIO14=TXD/GPIO15=RXD on the 40-pin header.

> For SWD breakpoint debugging over the *same* connector (Probe "**D**" port, `enable_jtag_gpio=1`, OpenOCD + GDB on all four cores), see **[debug-probe.md](debug-probe.md)**. The two modes are mutually exclusive per boot.

## Notes / gotchas carried from verification
- **Do NOT add `pciex4_reset=0`** to `config.txt` — Circle brings up the PCIe RC itself (see [claim-verification.md](claim-verification.md) #3).
- For 4K HDMI you'd need `hdmi_enable_4kp60=1`; at ≤1080p the framebuffer "limited" caveats don't bite.
- The toolchain prefix lives in `Config.mk`; `scripts/build.sh` exports `/opt/homebrew/bin` on PATH so the brew toolchain is found in non-login shells.

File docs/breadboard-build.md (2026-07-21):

# GuitarDAWLiteOS — Breadboard / Perfboard Build Guide

The fast, solderless way to bring up the Phase-1 audio hardware before committing to the [KiCad PCB](../kicad/). Uses **breakout modules** (GY-PCM5102 DAC, GY-PCM1808 ADC or a bare PCM1808 on a TSSOP→DIP adapter) and a **DIP op-amp**, so everything plugs into a breadboard.

See the placement diagram (rendered in chat / [breadboard-layout.svg](breadboard-layout.svg)).

> ⚠️ **Clock pivot (2026-07-10): the PCM1808 is now the I²S bus master** — strap **MD0=MD1=HIGH (3.3 V)**, FMT=GND; the ADC divides the Nano's 12.288 MHz MCLK into BCK/LRCK and the **Pi 5 runs I²S slave** (`GDAW_I2S_SLAVE` in [src/config.h](../src/config.h)). The old MD-to-GND / Pi-as-master instructions are gone from this doc. For the as-built bench wire-by-wire card use **[adc-hookup.md](adc-hookup.md)** + [wiring-diagram.svg](wiring-diagram.svg) + [codec-power-schematic.svg](codec-power-schematic.svg); for the 9 V TL072 drawer-parts front-end use [tl072-frontend.md](tl072-frontend.md) + [tl072-frontend-schematic.svg](tl072-frontend-schematic.svg).

## Why this differs from the PCB
The [KiCad board](../kicad/) uses **bare** PCM1808 + PCM5102A and includes the DAC's charge-pump caps, LDO, and output filter. On the breadboard, the **GY-PCM5102 module hides all of that** (onboard 3.3 V LDO, charge pump, and a 3.5 mm output jack), so the breadboard parts count is much lower. Same I²S/clock/front-end topology.

## Parts (breadboard-friendly)
| Qty | Part | Note |
|----:|---|---|
| 1 | Raspberry Pi 5 | + a 40-pin **GPIO breakout / T-cobbler** + ribbon (much more reliable than 8 loose jumpers) |
| 1 | **GY-PCM5102** module | DAC; has onboard LDO + 3.5 mm out |
| 1 | **GY-PCM1808** module (or bare PCM1808 on a TSSOP-14→DIP adapter) | ADC |
| 1 | **MCP6002** (DIP-8) | op-amp; RRIO, single-5 V, breadboard-friendly. *(OPA1662/OPA2353 for the PCB.)* |
| 1 | ¼″ mono jack + short leads | guitar in |
| 1 | **100 kΩ** trimpot (RV1, e.g. Bourns 3296W) | gain trim — in series with Rf 10 k → ×2…×12 |
| — | R: 1 MΩ, 2×10 kΩ, 10 kΩ, 1 kΩ | Rbias, R1/R2, Rg, Rf, Rs |
| — | C: 0.1 µF×(Cin, C8, +PCM1808 VCC/VDD/VREF 0.1 µF), 1 µF×(Cout, Cr), 1 nF (Ca), 10 µF×(C1 + PCM1808 bulk) | film/ceramic + a couple electrolytics |
| 1 | breadboard + jumper kit | |

> A passive guitar pickup needs the front-end — **don't plug the guitar into the ADC directly** (see [hardware-review.md](hardware-review.md)).

## Power rails on the breadboard
| Rail | From | Feeds |
|---|---|---|
| **+5 V** (red) | Pi header **pin 2** | GY-PCM5102 VIN, PCM1808 VCC, op-amp V+ |
| **+3.3 V** (a spare row) | Pi header **pin 1** | PCM1808 VDD only (digital) |
| **GND** (blue) | Pi header **pin 6** | everything; single star tie |

(On the breadboard the GY-PCM5102's own LDO handles its 3.3 V, so header 3V3 only carries PCM1808's ~6 mA — well within budget.)

## Placement (left → right; keep analog away from the clocks)
1. **Pi cobbler / power-in** — left edge. Land +5 V→red rail, +3V3→a row, GND→blue rail.
2. **Guitar front-end** (analog zone) — ¼″ jack → `Cin` → `Rbias`(to VBIAS) → MCP6002 buffer → gain (`Rg`,`Rf`+`RV1`) → `Cout`→`Rs`→`Ca` → ADC VINL. `VBIAS` divider (`R1`/`R2`/`C1`) and `C8` bypass nearby. Keep this cluster **left and away** from the BCLK/LRCLK/MCLK jumpers.
3. **PCM1808 (ADC)** — middle. Straps **MD0/MD1→3.3 V** (master, 256 fs), FMT→GND. Decoupling 0.1 µF+10 µF at VCC, VDD, VREF.
4. **GY-PCM5102 (DAC)** — right. Pads **FLT=L, DEMP=L, XSMT=H, FMT=L**; SCK→GND. Out via its 3.5 mm jack.

## Build order (with test checkpoints)
Post-pivot the ADC drives every bus clock — **nothing plays or captures until the Nano + ADC are up**, so they come first.
1. **Rails + cobbler.** Wire +5 V / +3.3 V / GND. Double-check polarity before powering.
2. **MCLK (Spike B) — done:** the **Arduino Nano ESP32** ([esp32-mclk/esp32-mclk.ino](../esp32-mclk/)) generates 12.288 MHz on its own **D2 (GPIO5)** pin, independent of the Pi 5. Flashed and bench-verified via the chip's own PCNT self-test (no scope needed) at 12.2880 MHz, exact match. (The Pi-internal `GPCLK0` route was ruled out — `clk_i2s` is already claimed by BCLK the whole time I²S runs; see [claim-verification.md](claim-verification.md).)
3. **ADC (bus master):** strap **MD0/MD1→3.3 V, FMT→GND**; VCC←5 V (+0.1 µF&10 µF), VDD←3.3 V (+0.1 µF&10 µF), VREF→0.1 µF&10 µF to GND; SCKI←**Nano ESP32 D2**; the ADC then **drives** BCK→GPIO18, LRCK→GPIO19, DOUT→GPIO20. Boot the M3 kernel: the HDMI stats line's capture counter should tick at 48,000 frames/s. Temporarily feed VINL a line-level signal to see non-zero samples. (Wire-by-wire card: [adc-hookup.md](adc-hookup.md).)
4. **DAC playback:** GY-PCM5102 VIN←5 V, GND, **BCK/LCK ← the same ADC-driven bus** (rows shared with Pi GPIO18/19), DIN←GPIO21, **SCK→GND**, pads **L/L/H/L**. With the monitor path live you should hear the VINL signal at the 3.5 mm out. *No sound? Check **XSMT=H** first.*
5. **Front-end:** build VBIAS (R1/R2/C1 → 2.5 V), then the MCP6002 buffer + gain (Rg=10 k, Rf=10 k + RV1), Cin/Rbias, Cout→Rs→Ca→VINL, Cr on VINR, C8 bypass on the op-amp. Jack → Cin. Set RV1 to **×3**; check a hard strum peaks ≈ −1…−3 dBFS on a level meter.

## Common-mistake checklist
- [ ] **XSMT pad = HIGH** on the GY-PCM5102 (ships LOW = muted → silence).
- [ ] PCM1808 **MD0/MD1 HIGH (3.3 V), FMT to GND** *before power-on* (selects I²S **master**, 256 fs — the 2026-07-10 pivot; MD-to-GND slave mode is the old, wrong strap).
- [ ] PCM1808 **VCC = 5 V**, **VDD = 3.3 V** (not both 3.3 V — analog needs 5 V).
- [ ] **GPIO20 = capture-in** (ADC DOUT), **GPIO21 = playback-out** (DAC DIN) — not swapped.
- [ ] **MCLK from the Nano ESP32** present (12.288 MHz on its D2 pin) before expecting ADC data — this no longer comes from a Pi GPIO.
- [ ] Guitar goes through the **front-end**, never straight to VINL.
- [ ] Op-amp on **5 V** (so it can swing to 4.0 V); MCP6002 is RRIO so it's fine.
- [ ] Single **star ground**; AGND≡DGND on the PCM1808.

Once this works on the breadboard, the [KiCad netlist](../kicad/) turns it into a fabbable board.

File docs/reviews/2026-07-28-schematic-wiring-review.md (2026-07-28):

# Schematics & Wiring — Adversarial Review (2026-07-28)

Review of the drawing set a builder actually wires from: `wiring-diagram.svg`,
`codec-power-schematic.svg`, `tl072-frontend-schematic.svg`, `frontend-schematic.svg`,
`schematic.md`, `adc-hookup.md`, `breadboard-build.md`, `hardware-review.md`, the ngspice decks,
and the `kicad/` netlist. Method: 6 parallel finder lenses (wiring · power/ground · analog front-end ·
KiCad netlist · buildable schematic · clocking & logic levels) → merge/triage → one adversarial
refuting verifier per surviving finding.

**This run also closes the gap left by [2026-07-21](2026-07-21-m2-bench-adversarial-review.md)**, which
died on a token limit with the `clocking`, `analog`, and `firmware-contract` lenses never run and most
verifiers never executed. All three of those lenses ran to completion here, and every finding below
carries a real verifier verdict.

**Result: 8 findings triaged from 30 raw · 6 CONFIRMED · 2 REFUTED.** Nothing here blocks first light.
No finding is a wiring error: the post-pivot topology (Nano MCLK → ADC master → Pi slave + DAC), the
pin map, and the strap tables are consistent across every as-built sheet. The defects are **stale
guidance in the surrounding docs and two fixes that landed in prose but never on the drawings.**

---

## CONFIRMED

### 1. MAJOR — `C_byp` is missing from the TL072 sheet (regression from the 2026-07-22 fix)

[`tl072-frontend.md:32-52`](../tl072-frontend.md) mandates **`C_byp` = 100 µF ∥ 0.1 µF at U1 pin 8 → GND**,
added because the ngspice rail→ADC transfer is **−16.9 dB at max trim** (≈ −66 dBFS hum). That fix landed
in the prose only: `grep -i byp docs/tl072-frontend-schematic.svg` returns **zero hits**, and the sheet's
`+9V` node (line 71) runs straight into R1 10 k with nothing to ground. The sheet is indexed by
`schematic.md:9` as the as-built bench front-end — it is what gets wired.

Sharpening the finding: the 9 V sheet is not cap-less (it draws C1 10 µF on the VBIAS divider, lines 74-76),
which makes the absent rail cap read as deliberate rather than as an omission. The 5 V canonical sheet
*does* carry its bypass note (`frontend-schematic.svg:76`).

**Fix:** draw `C_byp` from `+9V` to GND on the SVG, or at minimum add it to the notes block beside the pin-8 line.

### 2. MAJOR — `build-plan.md:39` sends the builder to an LDO that does not exist in this build

The Milestone-2 preamble says power off **"header 5 V + local LDO (not header 3V3)"**. Milestone 2 *is* the
CJMCU-1808 breadboard bench — and that module has **no onboard regulator**. Every as-built doc requires
header **pin 1**: `adc-hookup.md:63` ("both required"), `breadboard-build.md:31`, `wiring-diagram.svg:71`,
and `hardware-review.md:46`/`:50` ("by default VDD runs from header 3V3 pin 1 directly; a local 3.3 V LDO
off 5 V is an optional clean-rail upgrade").

A builder trusting the M2 summary skips the pin-1 wire — **ADC digital VDD unpowered = dead capture** — and
hunts a part the bench BOM doesn't contain. The original rule was **analog-rail-only**; the summary dropped
the qualifier. `hardware-review.md` compounds it: headline 6 (line 20) says "regulate locally" and the risk
register (line 149) says "5 V + local LDO", while its own power tree shows no regulator on the analog path.

**Fix:** rewrite line 39 to "analog off header 5 V (never header 3V3 for *analog*); digital VDD from header
pin 1 direct; no onboard regulator on the CJMCU breakout." Verifier's correction to carry: the only LDO in
the project is `U4 AP2112K-3.3` on the **KiCad bare-chip board**, and there it is a **digital**-rail
regulator, not an analog one.

### 3. MAJOR — the TL072 SPICE deck labels a *typical* swing as "worst-case", and that inverts its own conclusion

[`sim/frontend-tl072-9v.cir:7`](../sim/frontend-tl072-9v.cir) reads `VMARGIN = 1.5 (TL072 worst-case output
swing limit from each rail)`. For the classic TL07xC (±15 V, RL ≥ 10 k) **VOM is typ ±13.5 V / min ±12 V** —
so 1.5 V from the rail is the **typical** swing and 3 V from the rail is the guaranteed minimum. The repo
demonstrably knows the difference: the 5 V sibling deck re-runs at `VMARGIN=0.6` explicitly "to model
OPA1662 worst-case" (`frontend.cir:7`, documented at `schematic.md:85`). The TL072 deck claims that rigor
in a comment but never performs the run.

The consequence is load-bearing. At a 3 V guaranteed-min margin the op-amp clips at feo = 6.00 V while the
ADC's 4.0 V full scale sits at feo = 6.434 V — so **the op-amp clips first, on positive peaks only**,
inverting the deck's own assertion at lines 75-77 ("the ADC's 1.0–4.0 V full-scale clips first"), which
`tl072-frontend.md:63` repeats as a pass. A builder would expect symmetric digital clipping and hear
one-sided analog clipping.

Verifier's narrowing, all worth keeping: **only the positive peak is at risk** (vmin = 3.406 V clears even a
3 V margin) — this is an asymmetry created by VBIAS = 0.545·V_rail, not a general headroom shortfall. The
≥ 8.3 V battery gate was derived from the input common-mode floor alone with no output-headroom term
(at 8.3 V, headroom is 2.28 V). And `cmmax` = 5.408 V is **measured but has no pass bar anywhere** — the
docs guard only the ≥ 4.0 V CM floor. Not a hardware hazard: Rf is "10 k + trim", so gain can be trimmed down.

**Open (needs the datasheet, not the repo):** the classic TL072 datasheet publishes no guaranteed swing at
9 V single-supply, and the real load here is light (~20 k), which helps. Whether a worst-case part actually
soft-clips at 9 V is genuinely unresolved.

**Fix:** re-run the transient at `VMARGIN=3`, relabel line 7 as "typical (VOM typ, RL ≥ 10 k)", document the
resulting margin honestly, and add an upper-CM pass bar beside the existing ≥ 4.0 V floor.

### 4. MINOR — both SVG sheets lack the adjudicated A3/B2 mitigations and still print the retired "no islands" wording

The 2026-07-21 review adjudicated A3/B2 with the fix "paired HF return + 33 Ω at D2 … two Nano grounds …
docs stop calling paired returns islands". `adc-hookup.md:79-89` complies. **Neither drawing does:**

| | `wiring-diagram.svg` | `codec-power-schematic.svg` |
|---|---|---|
| Nano grounds | one (`:23`) | one (`:14`) |
| 33 Ω at D2 | absent (grep for `33` hits only coordinates) | absent |
| paired/twisted HF return | absent | absent |
| retired wording | `:71` "one rail, no islands" | `:39` "one point, no ground islands" |

Both sheets are named as wire-from sources by other docs, so a builder working from either alone omits all
three mitigations — and would actively refuse the second Nano ground wire `adc-hookup.md` mandates.
Severity stays minor: Science graded these EMI hygiene and robustness, not a measured-noise or damage risk.

**Fix:** on both sheets, "D2 —33R→ MCLK; **two** GND wires (one twisted with MCLK) → star", a paired-return
note on the BCK/LRC/OUT bundle, and reword the star note to "one **DC** point (paired HF clock returns OK —
not islands)".

### 5. MINOR — `hardware-review.md:100` names a star-ground location that doesn't resolve to pin 6

"…single return to a Pi GND pin **physically near the I²S pins**" — but the I²S pins are J8 12/35/38/40,
whose nearest header grounds are **14/34/39**, while pin 6 sits beside the power pins. Every other as-built
doc names pin 6 explicitly (`adc-hookup.md:66`, `breadboard-build.md:32`, `schematic.md:46`,
`codec-power-schematic.svg:38`, `wiring-diagram.svg:72`).

**Downgraded from major** — the verifier refuted the larger half of the original claim, correctly:
line 76's "6, 9, 14, 20, 25, 30, 34, 39" is simply the complete set of GND pins on a 40-pin header
(an enumeration in a *Pi pin* column, pin 6 bolded and listed first), and both line 47 and line 100 say
"single-point"/"single return" — the doc never instructs landing grounds on multiple pins, so there is no
ground-loop hazard. The banner was also not overstated: line 8 scopes "still current" to the
analog/power/front-end *rationale*, and lines 9-10 hand wiring authority to `adc-hookup.md`.

**Fix:** rewrite line 100 to name pin 6; optionally caption line 76 as "header GND pins available; star at pin 6".

### 6. MINOR — the superseded ferrite-only analog filter is still prescribed by two docs and carried into `gen.py`

The adjudicated A1 verdict is that **a ferrite alone is ≈0 dB in-band** against the PCM1808's ratiometric
rail coupling, and the fix is a measurement-gated **RC (≈10 Ω + 470 µF ∥ 0.1 µF)**. That landed in
`adc-hookup.md:69-77` only. Still prescribing the old network as current: `hardware-review.md:43` (power
tree), `:49` ("clean, stable 5 V (ferrite + bulk + 0.1 µF)"), `:74` ("VCC pin 3 via ferrite"), and
`schematic.md:29`/`:44`/`:90` (FB1). `kicad/gen.py:51`/`:80` carries FB1 into any rev-B regeneration.
`codec-power-schematic.svg:36` nets analog VCC straight to +5 V with no filter and no pointer to the
pending measurement gate.

**Fix:** update those rows to the A1 verdict or annotate them "superseded — see `adc-hookup.md`"; add one
note line to the codec sheet pointing at the silence-FFT gate; put the FB1-vs-RC decision on the rev-B worklist.

---

## REFUTED

### R1. `schematic.md`'s build order is *not* a live rev-A hazard

The finding claimed step 3 had been refreshed post-pivot while step 4 still said "strap U2
(MD0/MD1/FMT→GND)", so the line-5 banner no longer reads as covering the build list. **`git blame -L 88,95`
kills it:** step 3 is commit `c237c24` (2026-07-09 18:25) — the Spike-B resolution, which *predates* the
pivot commit `f524c7d` (2026-07-10). `git diff c237c24 40a6248 -- docs/schematic.md` shows the post-pivot
commit touched only the banner and the Sheets bullets (5 insertions, 2 deletions). The entire numbered
list is uniformly pre-pivot rev-A behind a banner whose wording ("straps … **in this doc** are stale …
Wire from adc-hookup.md … instead") covers step 4 exactly. The "one maintained step" premise doesn't exist.

The secondary claim — that "the PCM1808 only needs fs-sync, not phase-lock" is a refuted rationale stated as
current fact — also fails *as a `schematic.md` defect*: it is verbatim `[CORR-4]`/E2 wording that still lives
un-bannered in `claim-verification.md:40`/`:79` and `build-plan.md:32`/`:114`, and its operative half is
*more* true post-pivot. If that wording is stale, it's stale over there, at info grade.

### R2. The DAC 5 V VIN "contradiction" — my error, not the repo's

A finding claimed every doc powers the GY-PCM5102 from 5 V while the as-built record says 3.3 V. **The
as-built record it was checking against was my own briefing text, and I wrote it wrong** — I compressed
`build-plan.md:54` ("Power per module (3.3 V)") into "3.3 V module power" and handed that to the reviewers
as ground truth. The repo is consistent: 5 V → VIN → the module's onboard LDO → 3.3 V internally, stated
in one line at `hardware-review.md:45` ("PCM5102A module VIN (its onboard LDO → 3.3V)") and confirmed as a
hard rule at `schematic.md:103` ("U3 must be the GY-PCM5102 **module** (onboard LDO) on the 5 V VIN").

Residual info-grade nit only: the two SVGs say bare "VIN ← 5 V" without that parenthetical. Adding four
words would stop the next reader making the same mistake I did.

---

## Carried forward (below the reporting cut, real, for the rev-B worklist)

- **`gen.py` rev-A items beyond the two the `kicad/README.md` banner names:** stale `I2S0 (RP1 alt a2)`
  comment; the GPIO4 declaration coupled into ERC; no Nano MCLK-in connector; docstring still claims it
  "matches docs/schematic.md". A complete regeneration list, not new defects.
- **Prior review's M2 (cable-sleeve ground loop) was never folded into `adc-hookup.md`** as promised —
  `wiring-diagram.svg:63` still reads "explicit GND wire to star (not just cable sleeve)", which keeps both
  return paths. The 2026-07-21 review listed it open; it stays open.
- `kicad/README.md` footprint table says the 2.2 µF caps are `C_1206`; the netlist and BOM say `C_0805`.
- `frontend-schematic.svg` (5 V canonical) carries no on-sheet marker distinguishing it from the 9 V bench
  sheet — both are current, for different builds, and only `schematic.md`'s index says which is which.

## Verified clean (no findings)

- **Topology and pin map.** `wiring-diagram.svg`, `codec-power-schematic.svg`, `adc-hookup.md`,
  `breadboard-build.md`, and `build-plan.md`'s M2 table agree wire-for-wire: MCLK Nano D2 → SCKI;
  BCK → p12/GPIO18; LRC → p35/GPIO19; OUT → p38/GPIO20; DIN ← p40/GPIO21; MD0/MD1 → 3.3 V, FMT → GND;
  DAC SCK → GND, XSMT = H.
- **Clock arithmetic.** 12.288 MHz ÷ 256 = 48 kHz LRCK, ÷ 4 = 3.072 MHz BCK — stated consistently everywhere.
- **Logic levels.** No 5 V signal reaches a Pi GPIO; the ADC's digital domain is on 3.3 V VDD and its
  outputs drive the Pi at 3.3 V.
- **KiCad netlist integrity.** `python3 validate.py` → 41 components, 28 nets, 129 nodes, all refs resolve;
  both custom symbols' pin counts check out. (Structurally sound — it validates the rev-A design, which the
  README correctly bans from fab.)

*Findings by 6 Fable-5 finder lenses, merged by a triage judge, each verified by an independent refuting
verifier that read the cited files. Two findings were killed on the evidence, one of them by catching an
error I introduced in the briefing.*

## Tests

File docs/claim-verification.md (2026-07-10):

# GuitarDAWLiteOS — Research-Claim Verification Report

**Date:** 2026-06-29
**Method:** 6 source/web finders + 13 independent adversarial skeptics (19 agents total).
Circle was **cloned on both `master` (release-51, 2026-05-05) and `develop` (HEAD `22722a7`, 2026-06-08)** and read directly; TI datasheets (PCM1808 SLES177B, PCM5102A SLAS859C), the RP1 Peripherals datasheet (RP-008370), the Raspberry Pi "Using the I²S peripherals" white paper (RP-009699-WP-1), RPi bare-metal forum threads, and the GitHub REST API were used for the rest.

**Bottom line:** The platform thesis holds — Circle has real, hardware-tested Pi 5 RP1 I²S (capture + playback), SD, and framebuffer support, and an exact 12.288 MHz MCLK for the PCM1808 is achievable. **But 6 claims are wrong or materially misleading, and 3 of those change the build sequence.** Read "Consequential corrections" before building.

---

## Status legend
- ✅ **Confirmed** — verified against primary source, survived refutation.
- 🟡 **Corrected/nuanced** — core idea right, but a detail is wrong or needs qualification. **Act on the corrected statement, not the doc.**
- ❌ **Refuted** — the claim as written is false.

---

## Summary table (29 claims)

| ID | Claim (abbrev.) | Verdict | One-line correction / confirmation |
|----|---|---|---|
| B1 | Circle has working Pi 5 RP1 I²S on master+develop | ✅ | `CI2SSoundBaseDevice` in `i2ssoundbasedevice-rp1.cpp`, byte-identical on both branches, built when `RASPPI=5`, tested on PCM5102A/PCM5122/WM8960. |
| B2 | Uses Synopsys DesignWare I²S + `pll_audio` clock | ✅ | Ported from Linux `dwc-i2s.c`; clocked from `GPIOClockSourcePLLAudio`. ("rev 1.11a" is asserted by the RP1 datasheet, not by Circle source.) |
| B3 | DMA chunk size capped at ≤128 (pll_audio "fix") | ❌ | **FALSE.** Chunk size is a constructor arg, **default 8192**, no ≤128 cap anywhere. See correction #1. |
| B4 | DMA mode + IRQ fallback both exist | ✅ | DMA is default; `#define USE_I2S_SOUND_IRQ` switches to programmed-I/O (2-ch only). |
| C1 | RP1 has 3 DW I²S; I²S0=master, I²S1=slave, I²S2 unconnected | ✅ | Confirmed via RPi white paper (3 instances, only 2 pinned, "Instance 2 not accessible"). Circle exposes I²S0/I²S1 only. |
| C2 | GPIO18-21 pinout; which line is capture vs playback | ✅ | **GPIO20 = capture-in (ADC DOUT→here), GPIO21 = playback-out (→DAC DIN).** Doc's two statements are both right once chip-side vs Pi-side naming is normalized. |
| C3 | RP1 I²S = standard I²S only (no LJ/RJ/TDM) | ✅ | Confirmed in driver **and** silicon (rev 1.11a, fixed 50:50 frame sync). Strap both codecs for I²S. |
| C4 | Memory map (I²S0/I²S1/GPIO0 bases) | ✅ | All five addresses match `bcm2712.h` exactly on both branches. |
| I5 | Circle is GPLv3 | ✅ | GPLv3-or-later (LICENSE + per-file headers). |
| D4a | Circle "ships a PCM5102A driver" | ✅ | No dedicated class — PCM5102A is a strapped I²S DAC needing no driver (works when no I²C address given). |
| D4b | Circle ships a WM8960 driver | ✅ | `CWM8960SoundController` (I²C), used by both legacy and RP1 I²S paths. |
| F1 | Pi 5 SD via `CSDHCIDevice`/EMMC | 🟡 | Class is **`CEMMCDevice`**, and Pi 5 SD is the **BCM2712 SDHCI at `0x1000FFF000` — NOT RP1**. Supported + tested. See correction #2. |
| F2 | FatFs (ChaN) under `addon/fatfs`, 1-clause BSD | ✅ | FatFs R0.16; `LICENSE.txt` literally says "equivalent to the 1-clause BSD license." |
| G1 | Pi 5 framebuffer via VideoCore mailbox | 🟡 | Class is **`CBcmFrameBuffer`** (not `CFrameBuffer`); mechanism confirmed; Pi 5 marked **"limited"** (firmware caveats, not a missing path). |
| A1 | `pciex4_reset=0` needed for RP1 access | 🟡 | Param is real/correct **for raw bare-metal**, but **Circle does NOT need or use it** — Circle brings up the PCIe RC itself. See correction #3. |
| A2 | Firmware resets PCIe RC; RP1 access before = data abort | ✅ | Confirmed (observed `dscr=0x03047e93` abort on early RP1 read). |
| A3 | Address translation `0x1F00000000 + (rp1−0x40000000)` | ✅ | Exact; UART0 `0x40030000`→`0x1F00030000` matches datasheet + Circle. |
| E1 | Pi 5 can emit ~12.288 MHz MCLK from `pll_audio` | 🟡 | **Feasible — ADC not broken** — but the doc's *mechanism* is wrong. See correction #4 (the most important one). |
| E2 | MCLK↔BCLK phase not guaranteed but OK for ADC/DAC | ✅ | Confirmed; PCM1808 needs only fs-synchronization, not fixed phase. |
| D2 | PCM1808 slave needs external MCLK 256fs=12.288 MHz | ✅ | Confirmed; no internal PLL. 384fs/512fs also valid. |
| D1 | PCM1808 strap-only; MD0/MD1/FMT; slave=all low | ✅ | Confirmed exactly: MD1=MD0=Low (slave), FMT=Low (I²S 24-bit); set before power-on; internal 50 kΩ pulldowns. |
| D3 | PCM5102A FMT→GND=I²S; modules may default LJ | ✅ | Confirmed + **added gotcha: the XSMT pad ships bridged LOW = MUTE; must be moved HIGH.** See correction #5. |
| I1 | `rsta2/minisynth` (Circle synth, PCM5102A, MIDI, HDMI GUI) | ✅ | Confirmed (GPL-3.0). PCM5102A is one of several supported DACs. |
| I2 | `probonopd/MiniDexed` w/ experimental Pi 5 | ✅ | Confirmed; Pi 5 experimental (no HDMI sound / USB-gadget yet). |
| I3 | `kmwebnet/simplecodec3` PCM5102A+PCM1808 board, **MIT** | ❌ | Board exists & pairs both chips, but **NOT MIT — no license at all** (all-rights-reserved). See correction #6. |
| I4 | diyelectromusic Pi 5 quad-PCM5102A on Circle | ✅ | Confirmed (May 27 2024 write-up, builds on Circle quad-lane I²S). |
| H1 | `ashokfernandez/Yin-Pitch-Tracking`, C, **MIT** | ❌ | Code exists (pure-C, embedded-oriented) but **NOT MIT — no license** (all-rights-reserved). See correction #6. |
| H2 | A YIN patent exists and "must be reckoned with" | 🟡 | A real patent existed (**FR2825505B1**, France Télécom/de Cheveigné) but is **EXPIRED (2018 lapse / 2021 term end) → public domain.** No live barrier. See correction #6. |
| F3 | Throughput math (288 KB/s/track, 1.15 MB/s ×4) | ✅ | Arithmetic confirmed; ~8.7× headroom on Class-10/UHS-I. |

---

## Consequential corrections (these change the build)

### 1. ❌ The "DMA chunk size ≤ 128" gotcha is FALSE — you have lots of headroom
The doc says to design the ring buffer around a ≤128-sample DMA chunk (interrupt every 2.67 ms). **Not true.** In `i2ssoundbasedevice-rp1.cpp` the chunk size is a constructor parameter `m_nChunkSize` that **defaults to 8192** `u32`-samples and directly sizes the DMA buffers; there is **no `128`/`MAX_CHUNK`/clamp anywhere** in the file, and nothing in the source or CHANGELOG ties `pll_audio` to a "chunk-size audio-quality bug fix." (The only per-transfer FIFO-half-depth limit is in the *optional* IRQ path, not the default DMA path.)
**Effect on plan:** Drop the ≤128 constraint. You can run larger DMA chunks, which *simplifies* SD-write batching and the Core-0 mix loop. Pick chunk size from your latency target, not a phantom cap. `pll_audio` is confirmed as the clock source (claim B2 stands) — just not for the reason the doc gave.

### 2. 🟡 Pi 5 SD card is on the BCM2712 (not RP1), via `CEMMCDevice` (not `CSDHCIDevice`)
On Pi 5, Circle drives the microSD through the **BCM2712's own SDHCI controller at physical base `0x1000FFF000`** (Broadcom labels it `sdio1`; Linux DT comment: *"SDIO1 is used to drive the SD card"*). It is **not** behind RP1/PCIe. The driver class is **`CEMMCDevice`** (an SDHCI-spec host) — there is no class literally named `CSDHCIDevice`. Pi 5 SD is implemented and **tested** (README marks it `x`, lists Pi 5 as "Tested"), not WIP.
**Effect on plan:** (a) Fix the class name in code/docs. (b) Architectural bonus: SD storage and the HDMI framebuffer (also BCM2712/mailbox) do **not** depend on the RP1 PCIe link — only I²S/GPIO do. With Circle this is moot (Circle brings up PCIe anyway), but it's useful if you ever bisect a bring-up failure.

### 3. 🟡 With Circle, do **NOT** add `pciex4_reset=0`
`pciex4_reset=0` is a real, current `config.txt` parameter (default 1; Pi 5 only) and **is** the correct workaround **for raw bare-metal projects that don't write their own PCIe root-complex driver.** **Circle is the opposite case:** it ships a full PCIe RC driver (`lib/bcmpciehostbridge.cpp`, ported from Linux `pcie-brcmstb.c`) driven by the RP1 southbridge driver, so **RP1 peripherals are live on entry to `main()` with a stock `config.txt`.** Circle's own `boot/config*.txt` contain no PCIe line, and its Pi 5 docs say "no specific action is necessary."
**Effect on plan:** Remove `pciex4_reset=0` from the Step-1 instructions **for the Circle-based build.** Keep it documented only as the fallback for a hypothetical no-Circle bring-up. (Claims A2/A3 — the *why* — remain correct.)

### 4. 🟡 MCLK for the PCM1808 is feasible, but Circle won't hand it to you — it's a real task
This is the single most important correction. The exact **12.288 MHz** SCKI is achievable on Pi 5 bare-metal because it comes from the **retunable Audio PLL** (1.536 GHz VCO ÷ 125 = 12.288 MHz, all integer), **not** the 200 MHz `pll_sys` (the "200/16=12.5, no clean divide" problem only applies to `pll_sys`-sourced GPCLKs). **ADC capture is not blocked.** But the doc's one-liner ("derive from a GPCLK output connected to `pll_audio`") is wrong in two concrete ways, both confirmed in Circle source *and* Linux `clk-rp1.c`:
- **GPCLK0/1/2 (GPIO4/5/6) cannot directly select `pll_audio` as parent.** `pll_audio` is an *exclusive parent of `clk_i2s`*. The valid route is **`pll_audio` → `clk_i2s` → `clk_gp0` → GPIO4 (Alt0)** (`clk_i2s` *is* a legal `clk_gp0` parent).
- **Circle's I²S sound device does not emit an MCLK pin** — it only drives BCLK (`64·fs` = 3.072 MHz @ 48 k) and LRCLK on GPIO18/19. To get 12.288 MHz on a header pin you must instantiate a **separate `clk_i2s` clock at `StartRate(12288000)`** and route it out via `clk_gp0`→GPIO4.
**Effect on plan:** MCLK generation becomes an explicit **early de-risking spike (Spike B)**, not a one-line assumption. Both SCKI (12.288 MHz, 256fs) and BCLK (3.072 MHz, 64fs) trace to the same `pll_audio` lock, so they stay frequency-coherent — verify the divider chain on the bench. (PCM5102A does **not** need MCLK — it has an internal PLL off BCLK, SCK tied low — so GPIO4 feeds the PCM1808 only.)

#### ⛔ Update 2026-07-09 — the `clk_i2s → clk_gp0 → GPIO4` route above does not actually work
Went to implement Spike B and found the mechanism this correction describes is blocked, in two layers:
1. **Circle doesn't implement the route at all.** `gpioclock-rp1.h`'s `TGPIOClockSource` enum has no value representing "clk_i2s"; `s_ParentAux[]` for `GPIOClock0/1/2` only lists `GPIOClockSourceXOscillator` and `GPIOClockSourcePLLSys` — never `clk_i2s`. (Confirmed against Circle `develop@22722a76`, `lib/gpioclock-rp1.cpp`.) The route *is* real in the RP1 silicon — upstream Linux `drivers/clk/clk-rp1.c` (`rpi-6.6.y`) lists `clk_i2s` as aux-index 10 of `clk_gp0`'s parent array — so this half is a genuine Circle API gap, not a hardware wall. Patchable in principle.
2. **The blocking problem: `clk_i2s` is a single physical clock generator already claimed exclusively by Circle's I²S peripheral for BCLK.** `CI2SSoundBaseDevice`'s constructor owns `GPIOClockI2S` and calls `m_Clock.StartRate(CHANS * CHANLEN * m_nSampleRate)` (`i2ssoundbasedevice-rp1.cpp:383`) — `64fs` = 3.072 MHz @ 48 kHz — for the entire time the sound device runs. MCLK needs `256fs` = 12.288 MHz, **4× that rate, from the same hardware block, at the same time.** One clock generator cannot output two frequencies simultaneously — patching in the `clk_gp0` route from item 1 would still fail the moment audio is actually running. Checked every other RP1 clock generator Circle/Linux expose (`clk_adc`, `clk_pwm0`, `clk_pwm1`, `clk_audio_in`, `clk_audio_out`) — `pll_audio` is disabled/unavailable as a parent for all of them in the real driver too. **There is no on-chip path to a `pll_audio`-locked signal on any GPIO while the I²S peripheral is active.**

**Effect on plan:** the internal-GPCLK approach for Spike B is dropped. **Resolution: generate MCLK off-chip**, on an **Arduino Nano ESP32** (ESP32-S3), wired to the PCM1808's SCKI pin, fully decoupled from the Pi 5's `pll_audio`/`clk_i2s`. ESP-IDF's `i2s_std` driver has first-class MCLK-out support (`mclk_io_num` / `mclk_multiple = I2S_MCLK_MULTIPLE_256`), so the driver computes the divider coefficients for us; BCLK/WS/DATA pins are left `I2S_GPIO_UNUSED` since the Nano ESP32 only needs to emit the MCLK tone. This keeps `[CORR-4]`/E2 intact — the PCM1808 only needs fs-sync, not phase-lock to the Pi 5's BCLK, which is exactly what an independently-clocked external generator gives it.

**Correction (still 2026-07-09, caught while getting the firmware to compile):** an earlier draft of this note claimed ESP32-S3 has a dedicated Audio PLL (APLL) that made it a better choice than a Pico for jitter. **That's wrong.** Checked the installed SDK's `soc/clk_tree_defs.h` directly: APLL only exists on the *original* ESP32 — `soc_periph_i2s_clk_src_t` on the S3 only offers `PLL_160M`/`PLL_240M` (the general-purpose SoC PLL, shared with other peripherals, not audio-dedicated) or `XTAL`. The firmware's attempt to request `I2S_CLK_SRC_APLL` failed to compile (`'I2S_CLK_SRC_APLL' was not declared in this scope`), which is what caught this. No bit-exact 12.288000 MHz is possible from any of these chips' crystals regardless (Pi 5 `pll_sys`/xosc, RP2040, and ESP32-S3's crystal all hit the same "needs a factor the crystal doesn't have" wall) — the ESP32-S3's genuine advantage here is just the high-level `i2s_std` driver API doing the divider math for us, not superior clock hardware.

**Verified 2026-07-09, no oscilloscope available:** the firmware includes a self-test using the ESP32-S3's own PCNT (pulse counter) peripheral — loop the MCLK pin back into a counter input with a jumper (D2→D3) and it prints the measured frequency once a second. Measured **12.2880 MHz**, exact match to target, repeatable whenever the loopback jumper made solid contact. This confirms frequency correctness; it does not characterize jitter/duty-cycle the way a real scope would, which isn't expected to matter for a consumer-grade ADC per `[CORR-4]`/E2 above.

#### ⛔ Update 2026-07-10 — E2's "async-but-fs-locked" reading was wrong; topology pivoted to ADC-as-master
E2 ("MCLK↔BCLK phase not guaranteed but OK") is true for **phase**, but was stretched to cover **frequency**: "fs-locked" is unachievable between two free-running crystals. With the Nano generating SCKI and the Pi generating BCK/LRCK independently, they drift tens of ppm apart; the PCM1808's clock-halt/resync logic (datasheet §7.4.2 — LRCK-vs-SCKI sync enforcement, mute + ~1 ms fade-in on every resync) would interrupt audio every fraction of a second. Corroborated by an RPi engineer (forum user 6by9) calling independently-clocked SCKI "a non-starter", and by the community-standard Pi wiring for this chip: **PCM1808 in MASTER mode with the external oscillator, Pi as I²S slave**.
**Effect on plan:** strap **MD0=MD1=HIGH** (master, 256 fs → SCKI/256 = 48 kHz; FMT=GND stays I²S); the ADC drives BCK/LRCK, the Pi consumes them (`bSlave=TRUE` → Circle's RP1 **I2S1** instance, same GPIO18-21 pads via AltFn4 — slave is a first-class Circle path, verified in `i2ssoundbasedevice-rp1.cpp` RunI2S). The PCM5102A is indifferent (BCK-PLL). Whole system is now one clock domain rooted at the Nano's crystal (absolute rate error ~±10 ppm — musically irrelevant for a self-contained looper). Kernel flipped via `GDAW_I2S_SLAVE` in src/config.h. Bench consequence: with no ADC wired there are no bus clocks, so the engine produces no callbacks — `cap`/`play` frozen at 0 on a bare-board boot is expected, not a fault. Sources: TI SLES177B §7.3.5/§7.4.2; raspberrypi.com forums (PCM1808 master-mode wiring, 6by9 comments); WLED MoonModules line-in guide; Circle `lib/sound/i2ssoundbasedevice-rp1.cpp`.

Firmware: [../esp32-mclk/](../esp32-mclk/). Sources: Circle `lib/gpioclock-rp1.cpp`/`include/circle/gpioclock-rp1.h` (`develop@22722a76`); Linux `drivers/clk/clk-rp1.c` (`rpi-6.6.y`, upstream Raspberry Pi fork); Espressif ESP-IDF I²S docs (`esp32s3/api-reference/peripherals/i2s.html`); installed `esp32:esp32` core 3.3.10 headers (`soc/clk_tree_defs.h`, `driver/i2s_std.h`, `driver/pulse_cnt.h`).

### 5. 🟡 PCM5102A breakout: the real gotcha is XSMT (mute), not just FMT
FMT→GND = I²S is confirmed. But on GY-PCM5102/HiLetgo modules the back-side solder pads ship bridged **all-low**, which is correct for FLT/DEMP/FMT but **wrong for XSMT (pad H3L): low = MUTE.** You must move **XSMT to HIGH (unmute)** or you'll get silence and chase a phantom wiring bug. Verify all four pads: FLT=L, DEMP=L, **XSMT=H**, FMT=L.

### 6. ❌/🟡 License reality: two "MIT" libraries are unlicensed; the YIN patent is expired
- **`kmwebnet/simplecodec3`** and **`ashokfernandez/Yin-Pitch-Tracking`** are **both unlicensed** (no LICENSE file, GitHub `spdx_id` null). They default to **all-rights-reserved**, which is *stricter* than MIT, not looser. → Use simplecodec3 as a **schematic study reference only** (don't redistribute the KiCad files); for the tuner, **reimplement YIN clean-room from the 2002 JASA paper** (or use a permissively-licensed lib) rather than shipping Ashok's code as MIT. Optionally, open an issue asking each author to add an OSI license.
- **YIN patent:** A real, numbered patent existed — **FR2825505B1 / WO2002097793A1**, inventor Alain de Cheveigné, assignee **France Télécom** (not "de Cheveigné/Kawahara," not CNRS/Ircam). It **lapsed in Feb 2018 and reached full term 2021-06-01; no US/EP grant ever issued.** → **No live patent barrier in 2026.** The only residual encumbrance is the **CNRS reference *code*'s research-only license**, which binds that specific source — avoided entirely by a clean-room reimplementation from the paper.

---

## Minor accuracy fixes (don't change the plan, fix in docs/code)
- Class names: `CSDHCIDevice` → **`CEMMCDevice`**; `CFrameBuffer` → **`CBcmFrameBuffer`** (`CScreenDevice` is correct).
- `ARM_I2S1_END` in `bcm2712.h` is defined as `ARM_I2S0_BASE+0xFFF` (harmless copy-paste; references I2S0).
- Pi 5 framebuffer "limited" caveats: 4K needs `hdmi_enable_4kp60=1`; headless init needs `SCREEN_HEADLESS`; WLAN is unreliable with HDMI active. None affect a wired HDMI monitor at ≤1080p.
- Circle Pi 5 I²S build dispatch: Makefile gates on `RASPPI==5`; the header dispatch is `#if RASPPI >= 5`. Build with `RASPPI=5`.
- "DesignWare rev 1.11a" is correct but sourced from the RP1 datasheet/white paper, not Circle's code.

---

## Primary sources (representative)
- Circle source, both branches: `lib/sound/i2ssoundbasedevice-rp1.cpp`, `include/circle/sound/i2ssoundbasedevice-rp1.h`, `lib/gpioclock-rp1.cpp`, `include/circle/bcm2712.h`, `include/circle/bcm2835.h`, `addon/SDCard/emmc.{cpp,h}`, `lib/bcmpciehostbridge.cpp`, `lib/southbridge.cpp`, `lib/bcmframebuffer.cpp`, `addon/fatfs/`, `README.md`, `CHANGELOG.md`.
- TI PCM1808 datasheet (SLES177B); TI PCM5102A datasheet (SLAS859C).
- RP1 Peripherals datasheet (RP-008370) §2.5.4 audio clocks, §3.7 I²S.
- Raspberry Pi white paper "Using the I²S peripherals on Raspberry Pi SBCs" (RP-009699-WP-1).
- RPi forum threads t=368402 (RP1 bare-metal access), t=359494/t=359512 (RP1 I²S/audio clocks), t=383613 (GPCLK divisors).
- Linux `drivers/clk/clk-rp1.c`, `drivers/pci/controller/pcie-brcmstb.c`, `bcm2712-rpi-5-b.dts`.
- Google Patents FR2825505B1 / WO2002097793A1; de Cheveigné & Kawahara, JASA 111(4):1917 (2002).
- GitHub REST API for repo/license metadata.

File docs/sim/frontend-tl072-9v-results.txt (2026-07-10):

Note: Starting dynamic gmin stepping
Note: Dynamic gmin stepping completed
Note: Starting dynamic gmin stepping
Note: Dynamic gmin stepping completed

Note: No compatibility mode selected!

Circuit: * guitardawliteos guitar front-end - tl072 on single 9v variant

Doing analysis at TEMP = 27.000000 and TNOM = 27.000000

Using SPARSE 1.3 as Direct Linear Solver

No. of Data Rows : 1
==== DC OP (expect vbias ~4.9V; vinl ~2.5V from ADC self-bias) ====
v(vbias) = 4.909086e+00
v(bo) = 4.909081e+00
v(feo) = 4.909056e+00
v(vinl) = 2.500000e+00
Doing analysis at TEMP = 27.000000 and TNOM = 27.000000

Using SPARSE 1.3 as Direct Linear Solver

No. of Data Rows : 761
==== AC gain (dB): expect ~9.5dB flat 20Hz-20kHz ====
gain_1k             =  9.54232e+00
gain_100            =  9.53537e+00
gain_20k            =  9.54239e+00
flo_3db             =  2.70156e+00

Error: measure  fhi_3db  when(WHEN) : out of interval
Note: Starting dynamic gmin stepping
Warning: Dynamic gmin stepping failed
Note: Starting true gmin stepping
Warning: True gmin stepping failed
Note: Starting source stepping
Note: Source stepping completed
 meas ac fhi_3db when vdb(feo)=6.54 fall=1 failed!

Reset re-loads circuit * guitardawliteos guitar front-end - tl072 on single 9v variant

Circuit: * guitardawliteos guitar front-end - tl072 on single 9v variant

Doing analysis at TEMP = 27.000000 and TNOM = 27.000000

Using SPARSE 1.3 as Direct Linear Solver

Initial Transient Solution
--------------------------

Node                                   Voltage
----                                   -------
vcc                                          9
vbias                                  4.90909
in                                           0
nbi                                    4.90909
xbuf.nint                              4.90908
bo                                     4.90908
ninv                                   4.90908
feo                                    4.90906
xgain.nint                             4.90906
aa                                         2.5
vinl                                       2.5
vrefadc                                    2.5
b.xgain.bamp#branch                9.81814e-10
b.xbuf.bamp#branch                -6.60264e-12
vrefadc#branch                     2.48262e-19
vin#branch                                   0
vcc#branch                        -0.000409091

Note: Starting dynamic gmin stepping
Warning: Dynamic gmin stepping failed
Note: Starting true gmin stepping
Warning: True gmin stepping failed
Note: Starting source stepping
Note: Source stepping completed

No. of Data Rows : 1260
==== TRAN hot-HB 1Vpp: expect feo 3.4-6.4V no clip; nbi >= 4.0V (CM) ====
vmax                =  6.40566e+00 at=  7.25134e-03
vmin                =  3.40558e+00 at=  3.74759e-03
cmmin               =  4.40838e+00 at=  5.74884e-03
cmmax               =  5.40837e+00 at=  7.25134e-03
==== ADC side: vinl should be ~2.5V +/- 1.5V (3Vpp), inside 1.0-4.0V ====
adcmax              =  3.96765e+00 at=  7.25134e-03
adcmin              =  1.01931e+00 at=  3.75259e-03
Doing analysis at TEMP = 27.000000 and TNOM = 27.000000

Using SPARSE 1.3 as Direct Linear Solver

Initial Transient Solution
--------------------------

Node                                   Voltage
----                                   -------
vcc                                          9
vbias                                  4.90909
in                                           0
nbi                                    4.90909
xbuf.nint                              4.90908
bo                                     4.90908
ninv                                   4.90908
feo                                    4.90906
xgain.nint                             4.90906
aa                                         2.5
vinl                                       2.5
vrefadc                                    2.5
b.xgain.bamp#branch                9.81814e-10
b.xbuf.bamp#branch                -6.60264e-12
vrefadc#branch                     2.48262e-19
vin#branch                                   0
vcc#branch                        -0.000409091

No. of Data Rows : 1285
==== TRAN overdrive 1.6Vpp in: x3=4.8Vpp. On 9V the TL072 does NOT ====
==== clip (that's the extra headroom vs the 5V design) - the ADC's  ====
==== 1.0-4.0V full-scale clips first; set the trim by ear/meter.    ====
od_vmax             =  7.30376e+00 at=  7.25007e-03
od_vmin             =  2.50334e+00 at=  3.74882e-03
od_adcmax           =  4.84831e+00 at=  7.25007e-03
od_adcmin           =  1.30693e-01 at=  3.74882e-03
Note: Simulation executed from .control section

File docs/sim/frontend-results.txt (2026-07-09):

==== DC OP (expect ~2.5V) ====
v(vbias) = 2.499998e+00
v(bo) = 2.499995e+00
v(feo) = 2.499983e+00
v(vinl) = 2.500000e+00
==== AC gain (dB) vs freq; input=0dB so vdb(feo)=gain ====
gain_1k             =  9.54232e+00
gain_100            =  9.53512e+00
gain_20k            =  9.54239e+00
flo_3db             =  2.60637e+00
Initial Transient Solution
==== TRAN hot-HB 1Vpp in (0.5V amp,1kHz): expect feo 1.0-4.0V, no clip ====
vmax                =  3.99669e+00 at=  7.24955e-03
vmin                =  9.96504e-01 at=  4.74924e-03
Initial Transient Solution
==== TRAN overdrive 1.6Vpp in (0.8V amp): x3=4.8Vpp should CLIP at rails ====
od_vmax             =  4.89456e+00 at=  6.25015e-03
od_vmin             =  9.44047e-02 at=  3.74780e-03

==== REALISTIC OP-AMP (VMARGIN=0.6, OPA1662 worst-case 0.6-4.4V): hot-HB 1Vpp still no clip ====
vmax                =  3.99669e+00 at=  7.24955e-03
vmin                =  9.96504e-01 at=  4.74924e-03

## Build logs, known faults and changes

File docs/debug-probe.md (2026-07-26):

# Raspberry Pi Debug Probe → Pi 5

The Debug Probe (SC0889) does **two different jobs** on the Pi 5, and they both use the
**same 3-pin JST-SH connector on the Pi**. You pick one per boot:

| Mode | Probe port | What you get | `config.txt` |
|---|---|---|---|
| **A — UART console** | **U** | Circle's log text streamed to the Mac. Read-only observation. | `enable_jtag_gpio` stays commented out |
| **B — SWD debug** | **D** | Real breakpoints, single-step, memory/register inspection, `load` over the wire, all 4 cores. | `enable_jtag_gpio=1` |

They are mutually exclusive because the Pi 5's debug connector muxes between UART and
Cortex-A76 SWD. In mode B the JST console is gone; the fallback console is GPIO14/15 on
the 40-pin header (see [Serial while in SWD mode](#serial-while-in-swd-mode)).

**Start with mode A.** It takes five minutes and proves the cable, the connector
orientation, and the probe are all good before you add OpenOCD to the list of things
that could be wrong.

**Status:** mode A ✅ verified live 2026-07-25. Mode B host side ✅ verified (OpenOCD sees
the probe, SWD interface ready); target side untested — needs `enable_jtag_gpio=1` on the
booted card. **Recommendation: stay in mode A through the M2 wiring** — mode B takes the
console away, and during first light a live frame counter beats breakpoints.

---

## Cabling (both modes)

The Pi 5's connector and the Probe's ports both follow
[RP-003139-SP, the Raspberry Pi 3-pin Debug Connector Specification](https://pip-assets.raspberrypi.com/categories/885-raspberry-pi-debug-probe/documents/RP-008189-DS-1-debug-connector-specification.pdf):

| Pin | UART signal | Serial-debug signal |
|---|---|---|
| 1 | RX | SC (serial clock) |
| 2 | GND | GND |
| 3 | TX | SD (bidirectional data) |

Signal names are **from the target's perspective**. The spec pairs them so that the
**JST-SH↔JST-SH cable in the Probe box is straight-through, pin 1 to pin 1** — the TX/RX
crossover is baked into the pin naming, so there is **nothing to swap and nothing to get
backwards**. Plug it in, both connectors are keyed.

- Probe end: the **U** port for mode A, the **D** port for mode B.
- Pi 5 end: the small 3-pin JST connector on the board edge marked **UART** — *not* the
  40-pin header.
- No VCC anywhere. 3.3 V logic on both sides, and the Pi is powered from its own supply.

Plugging a UART into a serial-debug port is explicitly safe under the spec; the reverse
can cause brief contention on pin 3 but is current-limited by the 100 Ω source-termination
resistors. So a wrong-port mistake costs you a confusing session, not hardware.

---

## Mode A — UART console

1. On the SD card, rename `cmdline.txt.uart` → `cmdline.txt`
   (it carries `logdev=ttyS11`; on Pi 5 Circle's dedicated debug UART is device number 10,
   named `ttyS11` — see `circle/doc/cmdline.txt`).
2. Probe **U** port → Pi 5 **UART** connector. Probe USB → Mac.
3. On the Mac:
   ```bash
   ls /dev/cu.usbmodem*
   ```
   The Probe is a CDC device, so it is `cu.usbmodem…` (it was `/dev/cu.usbmodem11402`
   here) — **not** `cu.usbserial…` like a generic FTDI adapter. The number changes with
   the USB port.
4. Open the console at **115200 8N1**:
   ```bash
   screen /dev/cu.usbmodem11402 115200
   ```
   Quit with `Ctrl-A` then `k`, then `y`. If `screen` leaves the terminal wedged:
   `reset`.
5. Power on the Pi. Circle's log streams out.

**✅ Verified live 2026-07-25** — `gdawcores:` / `gdawlite:` lines streaming at 115200.
Two things that cost time getting here:

- **The device name changes with the USB port** (`cu.usbmodem11402` on one port,
  `cu.usbmodem2102` on another). Re-run `ls /dev/cu.usbmodem*` after every replug.
- **A baud typo looks like a wiring fault.** `11520` instead of `115200` produces
  streams of `x!00))1)!!!` garbage — which actually *proves* the cable is fine. Garbage
  means data is arriving at the wrong rate; a genuine cabling fault gives you **silence**.

**Expected counter reading with no ADC wired: all zeros.** `cap 0 play 0 starve 0 drop 0
… laps 0/0` is correct, not a regression from the M3 bring-up that logged 48,000 frames/s
— that run predated the clock pivot, when the Pi was I²S master. As slave
([config.h:29](../src/config.h:29)) the engine produces no callbacks at all until the
PCM1808 masters the bus. **This makes the console an M2 first-light instrument: `cap`
starts counting the moment clocks arrive, and `starve`/`drop` say whether they're clean.**

> The Pi 5's debug UART tops out at 921600 baud (EEPROM-configurable), but Circle logs at
> 115200 and there is no reason to push it.

---

## Mode B — SWD debugging

Host tooling is already installed (`openocd` 0.12.0, `aarch64-elf-gdb` 17.2, both from
Homebrew). `debug/rpi5.cfg` is Circle's Pi 5 target config; `interface/cmsis-dap.cfg`
ships inside OpenOCD's own script path.

### One-time SD card change

`sdcard/config.txt.swd` is the SWD-enabled variant (`enable_jtag_gpio=1` uncommented).
Copy it onto the card **as `config.txt`**:

```bash
cp sdcard/config.txt.swd /Volumes/<YOUR_SD_NAME>/config.txt
```

Keep the stock `sdcard/config.txt` to switch back.

### Optional: the wait stub

`debug/wait-stub_2712.img` is Circle's do-nothing kernel — a single branch instruction that
parks the CPU until the debugger attaches. Copy it onto the card as `kernel_2712.img` when
you want a guaranteed-quiet target to attach to. For normal work, leave your real
`kernel_2712.img` on the card; you can halt it and `load` a fresh build over SWD anyway.

### The session

Two terminals.

**Terminal 1 — OpenOCD** (leave it running):
```bash
./debug/openocd-rpi5.sh
```
Expect it to report a CMSIS-DAP adapter and four `bcm2712.cpu0..3` targets, then listen on
3333–3336. If the DAP is flaky, slow it down: `SPEED=1000 ./debug/openocd-rpi5.sh`.

**Terminal 2 — GDB:**
```bash
aarch64-elf-gdb -x debug/gdbinit src/kernel_2712.elf
```
`debug/gdbinit` already connects to `:3333` (core 0) and defines two helpers:

- `reload` — `load` the current ELF over the wire, break at `main`, continue. **This is
  the big win: no SD-card shuffling and no power cycle between builds.**
- `coreinfo` — OpenOCD's view of all four cores.

Then the usual: `break`, `step`, `next`, `bt`, `info registers`, `x/16x`, `p`.

**Multi-core:** cores 1–3 are separate GDB instances on `:3334`, `:3335`, `:3336`. Since
[`cores.cpp`](../src/cores.cpp) pins the audio engine to its own core, that is how you
inspect the audio core without stopping the boot core.

### Serial while in SWD mode

The JST console is unavailable in mode B. Circle's documented fallback
(`circle/doc/debug-swd.txt`) is a serial adapter on **GPIO14/15** plus, in `Config.mk`:

```make
DEFINE += -DSERIAL_DEVICE_DEFAULT=0
```

and `logdev=ttyS1` (not `ttyS11`) in `cmdline.txt`.

⚠️ **Pinout conflict to remember:** [retro-deck-design.md](retro-deck-design.md) reclaims
GPIO14/15 for `ENC3_SW` / `ENC4_A`. During bring-up the encoders aren't wired, so the
header UART is free — but once the encoder harness exists, **SWD and a serial console can
no longer coexist**. Plan on SWD *or* console at that point, not both.

---

## Gotchas

- **`-O2` stepping is jumpy.** `circle/Rules.mk` compiles with `-g` (good, full DWARF is in
  `kernel_2712.elf`) but optimizes at `-O2`, so single-stepping reorders and inlines. For a
  gnarly bug, rebuild that translation unit with `OPTIMIZE="-O0 -g"` — but be aware `-O0`
  changes timing, which can mask or invent problems in the I²S/DMA path.
- **`enable_jtag_gpio=1` left on** silently kills the UART console. If mode A "stops
  working", check which `config.txt` is on the card.
- **The Pi 5 debug UART is always live** for firmware/bootloader output, independent of
  Circle. Garbage or unexpected text at power-on is usually the firmware, not your kernel.
- No documentation exists from Broadcom for the BCM2712 debug architecture; `rpi5.cfg`'s
  DBGBASE/CTIBASE addresses were reverse-engineered from the ROM table by the Raspberry Pi
  forum community and carried into Circle. If OpenOCD can't find the cores, that table is
  the first suspect.

## References

- [3-pin Debug Connector Specification (RP-003139-SP)](https://pip-assets.raspberrypi.com/categories/885-raspberry-pi-debug-probe/documents/RP-008189-DS-1-debug-connector-specification.pdf)
- [Raspberry Pi Debug Probe documentation](https://www.raspberrypi.com/documentation/microcontrollers/debug-probe.html)
- `circle/doc/debug-swd.txt` — Circle's own SWD walkthrough (the source for this one)
- `circle/doc/cmdline.txt` — `logdev` options and the `ttyS11` note

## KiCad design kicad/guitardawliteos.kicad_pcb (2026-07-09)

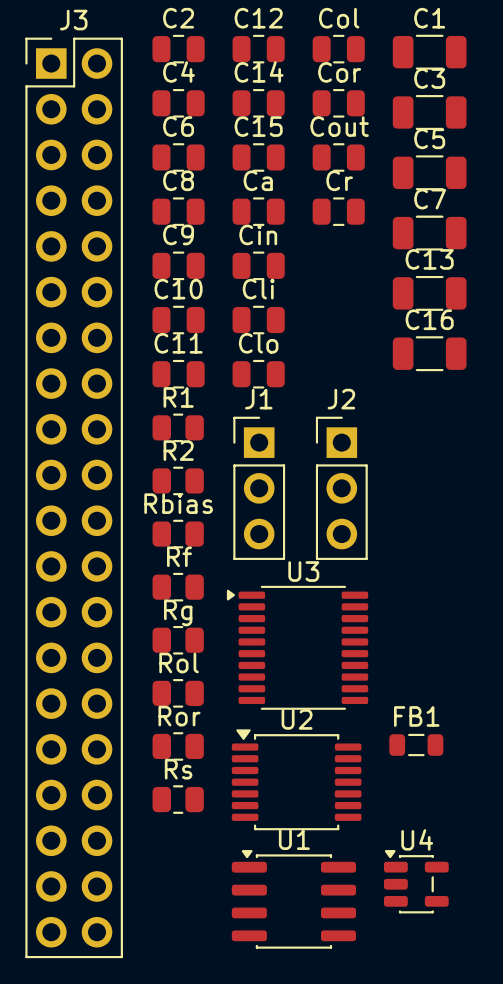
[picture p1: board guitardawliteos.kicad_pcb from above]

Board: 2 copper layers, 40 parts (0 on the bottom side), 27 nets, no tracks yet.

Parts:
C1, C3, C5, C7, C13, C16: 10uF; C_1206_3216Metric
C2, C4, C6, C8, C9, C12, C14, C15: 0.1uF; C_0805_2012Metric
C10, C11: 2.2uF; C_0805_2012Metric
Ca: 1nF; C_0805_2012Metric
Cin: 0.1uF; C_0805_2012Metric
Cli: 1uF; C_0805_2012Metric
Clo: 1uF; C_0805_2012Metric
Col: 2.2nF; C_0805_2012Metric
Cor: 2.2nF; C_0805_2012Metric
Cout: 1uF; C_0805_2012Metric
Cr: 1uF; C_0805_2012Metric
FB1: FerriteBead; L_0805_2012Metric
J1: Guitar_6.35mm; PinHeader_1x03_P2.54mm_Vertical
J2: Line_out; PinHeader_1x03_P2.54mm_Vertical
J3: RPi5_GPIO; PinHeader_2x20_P2.54mm_Vertical
R1, R2: 10k; R_0805_2012Metric
Rbias: 1M; R_0805_2012Metric
Rf: 10k; R_0805_2012Metric
Rg: 10k; R_0805_2012Metric
Rol: 470; R_0805_2012Metric
Ror: 470; R_0805_2012Metric
Rs: 1k; R_0805_2012Metric
U1: OPA1662; SOIC-8_3.9x4.9mm_P1.27mm
U2: PCM1808; TSSOP-14_4.4x5mm_P0.65mm
U3: PCM5102A; TSSOP-20_4.4x6.5mm_P0.65mm
U4: AP2112K-3.3; SOT-23-5

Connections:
+3V3: C4.1, C5.1, C9.1, C12.1, C13.1, C15.1, C16.1, Clo.1, U2.4, U3.1, U3.8, U3.17, U3.20, U4.5
+5V: C8.1, Cli.1, FB1.1, J3.2, R1.1, U1.8, U4.1, U4.3
AAO: Cout.2, Rs.1
BCLK: J3.12, U2.8, U3.13
BUF: U1.1, U1.2, U1.5
CAPDAT: J3.38, U2.9
CPM: C10.2, U3.4
CPP: C10.1, U3.2
FEO: Cout.1, U1.7
GIN: Cin.1, J1.1
GND: C1.2, C2.2, C3.2, C4.2, C5.2, C6.2, C7.2, C8.2, C9.2, C11.2, C12.2, C13.2, C14.2, C15.2, C16.2, Ca.2, Cli.2, Clo.2, Col.2, Cor.2, Cr.2, J1.2, J1.3, J2.3, J3.6, R2.2, U1.4, U2.2, U2.5, U2.10, U2.11, U2.12, U3.3, U3.9, U3.10, U3.11, U3.12, U3.16, U3.19, U4.2, U4.4
LDOO: C14.1, U3.18
LOUT: Col.1, J2.1, Rol.2
LRCLK: J3.35, U2.7, U3.15
MCLK: J3.7, U2.6
NBI: Cin.2, Rbias.2, U1.3
NINV: Rf.1, Rg.1, U1.6
OUTL: Rol.1, U3.6
OUTR: Ror.1, U3.7
PLAYDAT: J3.40, U3.14
ROUT: Cor.1, J2.2, Ror.2
VBIAS: C1.1, R1.2, R2.1, Rbias.1, Rg.2
VCC_A: C2.1, C3.1, FB1.2, U2.3
VINL: Ca.1, Rs.2, U2.13
VINR: Cr.1, U2.14
VNEG: C11.1, U3.5
VREF: C6.1, C7.1, U2.1

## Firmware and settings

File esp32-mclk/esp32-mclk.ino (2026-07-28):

// esp32-mclk.ino
//
// Standalone 12.288 MHz I2S MCLK generator for the PCM1808 ADC on the
// GuitarDAWLiteOS Pi 5 build (Spike B). Runs on an Arduino Nano ESP32
// (ESP32-S3), fully decoupled from the Pi 5's own pll_audio/clk_i2s --
// see docs/claim-verification.md ("Update 2026-07-09") for why the Pi 5
// can't generate this itself while its I2S peripheral is running BCLK.
//
// Only MCLK is used. BCLK/WS/DATA stay unconnected -- since the
// 2026-07-10 clock pivot the PCM1808 divides this MCLK into BCLK/LRCLK
// (ADC straps as bus master, Pi 5 runs I2S slave on GPIO18/19/20/21);
// this board's job is to hold GPIO5 (Nano ESP32 pin "D2") at a clean
// 256*48kHz tone.
//
// SELF-TEST / HEALTH READOUT: no scope on hand, so frequency is verified in
// hardware using the chip's own PCNT (pulse counter) peripheral instead of a
// logic analyzer. Link D2 -> D3 (GPIO6) and the serial monitor prints the
// measured frequency once a second.
//
// On the PERMANENT soldered build the D2 -> D3 link STAYS (see
// docs/solder-build.md 5), tapped on the Nano side of the 33 ohm series
// resistor so the counter reads the source while the resistor still damps the
// run to the ADC. With no scope on the bench, this 1 Hz print is the only
// continuous proof that the root of the whole audio clock domain is alive.
// (Earlier docs said to remove the jumper after bring-up -- that was right for
// a temporary bench jumper and is wrong for a soldered assembly.)
//
// SPDX-License-Identifier: GPL-3.0-or-later
//
#include "driver/i2s_std.h"
#include "driver/pulse_cnt.h"

namespace {

constexpr gpio_num_t kMclkPin = GPIO_NUM_5;      // Nano ESP32 silkscreen "D2"
constexpr gpio_num_t kCounterPin = GPIO_NUM_6;   // "D3" -- jumper to D2 for self-test
constexpr uint32_t kSampleRateHz = 48000;        // x256 = 12.288 MHz
constexpr int kPcntHighLimit = 30000;            // overflow point; accum_count folds these
                                                  // together so the 16-bit HW counter can
                                                  // track a 12.288 MHz input

i2s_chan_handle_t g_tx_chan = nullptr;
pcnt_unit_handle_t g_pcnt_unit = nullptr;

void StartMclk() {
  i2s_chan_config_t chan_cfg =
      I2S_CHANNEL_DEFAULT_CONFIG(I2S_NUM_AUTO, I2S_ROLE_MASTER);
  ESP_ERROR_CHECK(i2s_new_channel(&chan_cfg, &g_tx_chan, nullptr));

  i2s_std_config_t std_cfg = {
      .clk_cfg = I2S_STD_CLK_DEFAULT_CONFIG(kSampleRateHz),
      .slot_cfg = I2S_STD_PHILIPS_SLOT_DEFAULT_CONFIG(
          I2S_DATA_BIT_WIDTH_16BIT, I2S_SLOT_MODE_STEREO),
      .gpio_cfg =
          {
              .mclk = kMclkPin,
              .bclk = I2S_GPIO_UNUSED,
              .ws = I2S_GPIO_UNUSED,
              .dout = I2S_GPIO_UNUSED,
              .din = I2S_GPIO_UNUSED,
              .invert_flags =
                  {
                      .mclk_inv = false,
                      .bclk_inv = false,
                      .ws_inv = false,
                  },
          },
  };
  // NOTE (2026-07-09): ESP32-S3 has no APLL -- soc/clk_tree_defs.h's
  // soc_periph_i2s_clk_src_t only offers PLL_160M/PLL_240M (PLL_D2,
  // shared general-purpose SoC PLL)/XTAL/EXTERNAL. APLL is original-
  // ESP32-only; an earlier version of this file wrongly assumed S3 had
  // one too. I2S_STD_CLK_DEFAULT_CONFIG already selects I2S_CLK_SRC_DEFAULT
  // (PLL_160M) and mclk_multiple=256, so nothing to override here.

  ESP_ERROR_CHECK(i2s_channel_init_std_mode(g_tx_chan, &std_cfg));
  ESP_ERROR_CHECK(i2s_channel_enable(g_tx_chan));  // MCLK starts now
}

void StartFrequencyCounter() {
  pcnt_unit_config_t unit_cfg = {
      .low_limit = -1,
      .high_limit = kPcntHighLimit,
      .flags = {.accum_count = true},  // pcnt_unit_get_count() returns the
                                        // running total across HW overflows,
                                        // not just the raw 16-bit register.
  };
  ESP_ERROR_CHECK(pcnt_new_unit(&unit_cfg, &g_pcnt_unit));

  pcnt_chan_config_t chan_cfg = {
      .edge_gpio_num = kCounterPin,
      .level_gpio_num = -1,
  };
  pcnt_channel_handle_t chan = nullptr;
  ESP_ERROR_CHECK(pcnt_new_channel(g_pcnt_unit, &chan_cfg, &chan));
  ESP_ERROR_CHECK(pcnt_channel_set_edge_action(
      chan, PCNT_CHANNEL_EDGE_ACTION_INCREASE, PCNT_CHANNEL_EDGE_ACTION_HOLD));
  ESP_ERROR_CHECK(pcnt_channel_set_level_action(
      chan, PCNT_CHANNEL_LEVEL_ACTION_KEEP, PCNT_CHANNEL_LEVEL_ACTION_KEEP));

  ESP_ERROR_CHECK(pcnt_unit_add_watch_point(g_pcnt_unit, kPcntHighLimit));
  ESP_ERROR_CHECK(pcnt_unit_enable(g_pcnt_unit));
  ESP_ERROR_CHECK(pcnt_unit_clear_count(g_pcnt_unit));
  ESP_ERROR_CHECK(pcnt_unit_start(g_pcnt_unit));
}

}  // namespace

void setup() {
  // MCLK first, before anything that blocks. This board is the root of the whole
  // audio clock domain: until SCKI runs, the PCM1808 is powered down and the Pi's
  // I2S bus is dead. Starting the clock after Serial.begin()+delay(2000) left a
  // 2 s silent window on every reset, brownout and USB re-enumeration.
  StartMclk();

  Serial.begin(115200);
  delay(2000);  // give the serial monitor time to attach before we print

  StartFrequencyCounter();

  Serial.println();
  Serial.println("MCLK generator running: target 12.288 MHz (256x48kHz) on GPIO5 / D2.");
  Serial.println("Self-test: jumper D2 -> D3 (GPIO6), then watch the readings below.");
  Serial.println("No jumper = the count stays near 0, which is expected -- that's not a fault.");
}

void loop() {
  delay(1000);  // ~1s gate window: pulse count this window == frequency in Hz

  // Soft-fail, never ESP_ERROR_CHECK here: that panics and reboots the board, which
  // would drop MCLK and mute the whole audio chain because a *diagnostic* counter
  // hiccuped. The counter is expendable; the clock is not.
  int count = 0;
  esp_err_t err = pcnt_unit_get_count(g_pcnt_unit, &count);
  if (err != ESP_OK) {
    Serial.printf("PCNT read failed (%s) -- counter only; MCLK on D2 is unaffected.\n",
                  esp_err_to_name(err));
    return;
  }
  err = pcnt_unit_clear_count(g_pcnt_unit);
  if (err != ESP_OK) {
    Serial.printf("PCNT clear failed (%s) -- counter only; MCLK on D2 is unaffected.\n",
                  esp_err_to_name(err));
    return;
  }

  Serial.printf("Measured MCLK: %.4f MHz (target 12.288000 MHz)\n", count / 1.0e6);
}

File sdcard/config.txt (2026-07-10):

#
# Enable 64-bit mode (AArch64)
#
# This file must be copied along with the generated kernel image
# onto a SDHC card with FAT file system, if 64-bit mode is used.
#
# This file also enables the possibility to use two displays with
# the Raspberry Pi 4 and selects the required mode for the USB host
# controller of the Compute Module 4.
#

arm_64bit=1
kernel_address=0x80000
initial_turbo=0

# Enable this for JTAG / SWD debugging!
#enable_jtag_gpio=1

[pi02]
kernel=kernel8.img

[pi2]
kernel=kernel8.img

[pi3]
kernel=kernel8.img

[pi3+]
kernel=kernel8.img

[pi4]
armstub=armstub8-rpi4.bin
kernel=kernel8-rpi4.img
max_framebuffers=2

[cm4]
otg_mode=1

[pi5]
kernel=kernel_2712.img
device_tree_address=0x2000000
hdmi_force_hotplug=1
framebuffer_depth=32
framebuffer_ignore_alpha=1

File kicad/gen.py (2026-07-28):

#!/usr/bin/env python3
"""
GuitarDAWLiteOS — KiCad netlist + symbol generator (pure stdlib).

Emits, into this directory:
  guitardawliteos.net        KiCad netlist (Pcbnew "Import Netlist")
  guitardawliteos.kicad_sym  custom symbols: PCM1808, PCM5102A
  bom.csv                    bill of materials

Runs an ERC-lite (every pin on exactly one net, every net >=2 nodes, unique
refs, footprints present) and self-validates that the emitted s-expressions
parse (balanced).

Design = bare-chip carrier board: discrete OPA1662 guitar front-end +
bare PCM1808 ADC + bare PCM5102A DAC (+ AP2112 3.3V LDO) + Pi 5 40-pin header.
Datasheet-verified pinouts; matches docs/schematic.md (front-end SPICE-verified).
"""
import csv, os, sys

HERE = os.path.dirname(os.path.abspath(__file__))

FP = dict(
    soic8="Package_SO:SOIC-8_3.9x4.9mm_P1.27mm",
    tssop14="Package_SO:TSSOP-14_4.4x5mm_P0.65mm",
    tssop20="Package_SO:TSSOP-20_4.4x6.5mm_P0.65mm",
    sot235="Package_TO_SOT_SMD:SOT-23-5",
    r0805="Resistor_SMD:R_0805_2012Metric",
    c0805="Capacitor_SMD:C_0805_2012Metric",
    c1206="Capacitor_SMD:C_1206_3216Metric",
    l0805="Inductor_SMD:L_0805_2012Metric",
    trim="Potentiometer_THT:Trimmer_Bourns_3296W_Vertical",
    hdr1x3="Connector_PinHeader_2.54mm:PinHeader_1x03_P2.54mm_Vertical",
    hdr2x20="Connector_PinHeader_2.54mm:PinHeader_2x20_P2.54mm_Vertical",
)

def Rr(v): return (v, FP["r0805"], {1: "1", 2: "2"})
def Cc(v, big=False): return (v, FP["c1206"] if big else FP["c0805"], {1: "1", 2: "2"})

# ref -> (value, footprint, {pin#: pinname})
COMP = {
    # --- guitar front-end (discrete) ---
    "U1": ("OPA1662", FP["soic8"], {1:"OUTA",2:"-INA",3:"+INA",4:"V-",5:"+INB",6:"-INB",7:"OUTB",8:"V+"}),
    "J1": ("Guitar_6.35mm", FP["hdr1x3"], {1:"TIP",2:"RING",3:"SLEEVE"}),
    "Cin": Cc("0.1uF"), "Rbias": Rr("1M"),
    "Rg": Rr("10k"), "Rf": Rr("10k"), "RV1": ("100k", FP["trim"], {1:"1",2:"W",3:"3"}),
    "Cout": Cc("1uF"), "Rs": Rr("1k"), "Ca": Cc("1nF"), "Cr": Cc("1uF"),
    "R1": Rr("10k"), "R2": Rr("10k"), "C1": Cc("10uF", True), "C8": Cc("0.1uF"),
    # --- ADC: PCM1808 (bare, TSSOP-14) ---
    "U2": ("PCM1808", FP["tssop14"], {1:"VREF",2:"AGND",3:"VCC",4:"VDD",5:"DGND",6:"SCKI",
            7:"LRCK",8:"BCK",9:"DOUT",10:"MD0",11:"MD1",12:"FMT",13:"VINL",14:"VINR"}),
    "FB1": ("FerriteBead", FP["l0805"], {1:"1",2:"2"}),
    "C2": Cc("0.1uF"), "C3": Cc("10uF", True),   # VCC
    "C4": Cc("0.1uF"), "C5": Cc("10uF", True),   # VDD
    "C6": Cc("0.1uF"), "C7": Cc("10uF", True),   # VREF
    # --- DAC: PCM5102A (bare, TSSOP-20) ---
    "U3": ("PCM5102A", FP["tssop20"], {1:"CPVDD",2:"CAPP",3:"CPGND",4:"CAPM",5:"VNEG",6:"OUTL",
            7:"OUTR",8:"AVDD",9:"AGND",10:"DEMP",11:"FLT",12:"SCK",13:"BCK",14:"DIN",15:"LRCK",
            16:"FMT",17:"XSMT",18:"LDOO",19:"DGND",20:"DVDD"}),
    "C9": Cc("0.1uF"),                # CPVDD
    "C10": Cc("2.2uF"),               # CAPP-CAPM flying cap
    "C11": Cc("2.2uF"),               # VNEG
    "C12": Cc("0.1uF"), "C13": Cc("10uF", True),  # AVDD
    "C14": Cc("0.1uF"),               # LDOO
    "C15": Cc("0.1uF"), "C16": Cc("10uF", True),  # DVDD
    "Rol": Rr("470"), "Col": Cc("2.2nF"),   # OUTL filter
    "Ror": Rr("470"), "Cor": Cc("2.2nF"),   # OUTR filter
    "J2": ("Line_out", FP["hdr1x3"], {1:"L",2:"R",3:"G"}),
    # --- power ---
    "U4": ("AP2112K-3.3", FP["sot235"], {1:"VIN",2:"GND",3:"EN",4:"NC",5:"VOUT"}),
    "Cli": Cc("1uF"), "Clo": Cc("1uF"),
    # --- Pi 5 header (only used pins listed) ---
    # Pi 3V3 pin is NOT used: this board derives its own 3.3V via U4 (LDO off 5V).
    "J3": ("RPi5_GPIO", FP["hdr2x20"], {2:"5V",6:"GND",7:"GPIO4",12:"GPIO18",
            35:"GPIO19",38:"GPIO20",40:"GPIO21"}),
}

# net name -> list of (ref, pin#)
NETS = {
    "+5V":   [("J3",2),("U1",8),("C8",1),("U4",1),("U4",3),("FB1",1),("Cli",1),("R1",1)],
    "VCC_A": [("FB1",2),("U2",3),("C2",1),("C3",1)],            # PCM1808 analog 5V (post-ferrite)
    "+3V3":  [("U4",5),("Clo",1),("U2",4),("C4",1),("C5",1),
              ("U3",1),("C9",1),("U3",8),("C12",1),("C13",1),
              ("U3",20),("C15",1),("C16",1),("U3",17)],          # XSMT=H -> unmute
    "GND":   [("J3",6),("U1",4),("U4",2),("U4",4),("Cli",2),("Clo",2),
              ("J1",2),("J1",3),                                  # ring(NC) + sleeve
              ("U2",2),("U2",5),("U2",10),("U2",11),("U2",12),    # AGND,DGND,MD0,MD1,FMT
              ("C2",2),("C3",2),("C4",2),("C5",2),("C6",2),("C7",2),
              ("R2",2),("C1",2),("C8",2),("Ca",2),("Cr",2),
              ("U3",3),("U3",9),("U3",10),("U3",11),("U3",12),("U3",16),("U3",19),  # CPGND,AGND,DEMP,FLT,SCK,FMT,DGND
              ("C9",2),("C11",2),("C12",2),("C13",2),("C14",2),("C15",2),("C16",2),
              ("Col",2),("Cor",2),("J2",3)],
    "VREF":  [("U2",1),("C6",1),("C7",1)],                       # decouple-only (not driven)
    # I2S0 (RP1 alt a2) + MCLK
    "MCLK":    [("J3",7),("U2",6)],
    "BCLK":    [("J3",12),("U2",8),("U3",13)],
    "LRCLK":   [("J3",35),("U2",7),("U3",15)],
    "CAPDAT":  [("U2",9),("J3",38)],
    "PLAYDAT": [("J3",40),("U3",14)],
    # front-end signal chain
    "GIN":   [("J1",1),("Cin",1)],
    "NBI":   [("Cin",2),("Rbias",2),("U1",3)],          # +INA
    "VBIAS": [("R1",2),("R2",1),("C1",1),("Rbias",1),("Rg",2)],
    "BUF":   [("U1",1),("U1",2),("U1",5)],              # OUTA -> -INA (fb) + +INB
    "NINV":  [("U1",6),("Rg",1),("Rf",1)],              # -INB, gain set
    "MIDF":  [("Rf",2),("RV1",1)],                      # Rf 10k in series with RV1 (rheostat)
    "FEO":   [("U1",7),("RV1",2),("RV1",3),("Cout",1)], # OUTB + feedback + output
    "AAO":   [("Cout",2),("Rs",1)],
    "VINL":  [("Rs",2),("Ca",1),("U2",13)],
    "VINR":  [("U2",14),("Cr",1)],                      # Cr 1uF -> GND (AC-ground)
    # charge pump + DAC analog out
    "CPP":   [("U3",2),("C10",1)],
    "CPM":   [("U3",4),("C10",2)],
    "VNEG":  [("U3",5),("C11",1)],
    "LDOO":  [("U3",18),("C14",1)],
    "OUTL":  [("U3",6),("Rol",1)],
    "OUTR":  [("U3",7),("Ror",1)],
    "LOUT":  [("Rol",2),("Col",1),("J2",1)],
    "ROUT":  [("Ror",2),("Cor",1),("J2",2)],
}
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

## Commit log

2026-07-09 Add Phase-1 research verification, hardware review, and schematic design
    19-agent adversarial verification of 29 research claims against Circle's
    pinned source, TI/RP1 datasheets, and the HAT+ spec — 6 wrong, 3 build-
    changing (no DMA chunk cap, no pciex4_reset needed under Circle, MCLK
    generation needs a dedicated clk_i2s route). Guitar front-end SPICE-verified
    (+9.54 dB gain, flat response, no clip at hot-humbucker levels). DigiKey
    BOM priced against live listings (4 dead parts caught). Retro-deck Phase-2
    architecture (touch display, cassette tape insert, HAT+ mechanicals) and a
    9-milestone PCB-design learning path for hands-on fabrication.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
2026-07-09 Add KiCad HAT project (rev-A learning board)
    Openable KiCad 10 project (guitardawliteos.kicad_pro) generated from a
    Python netlist-as-code definition (gen.py: 41 components, 28 nets, built-in
    ERC-lite) and verified end-to-end with kicad-cli (sch erc/export, sym
    upgrade). The committed schematic is a titled blank canvas — drawing it by
    hand is the learning exercise; gen.py's netlist is the answer key, imported
    via Import > Netlist for comparison.
    [bom.csv, guitardawliteos.kicad_pcb, guitardawliteos.kicad_sch]
2026-07-09 Add Milestone-0 bring-up kernel: headless-safe boot + Active Cooler thermal management
    First-boot payload for the Pi 5, verified on real hardware:
    - Boot chain, RP1 GPIO, and active thermal management (CCPUThrottle,
    gpiofanpin=45 socmaxtemp=60) all confirmed live.
    - Fixed a real Circle gotcha: CScreenDevice::Initialize() hard-fails on
    Pi 4/5 with no HDMI monitor attached (documented in Circle's own
    doc/issues.txt), which was silently gating the entire boot past
    Initialize() and halting before Run() ever executed. Screen/serial are
    now optional and non-fatal; the logger falls back to CNullDevice so the
    thermal loop always runs regardless of what's plugged in.
    - Added an LED-encode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
    [config.txt]
2026-07-09 Resolve Spike B: internal GPCLK0 MCLK route ruled out, external Nano ESP32 generator verified
    The planned clk_i2s -> clk_gp0 -> GPIO4 MCLK route doesn't work: clk_i2s is a
    single physical clock generator already claimed exclusively by Circle's I2S
    peripheral for BCLK (64fs) the whole time audio runs, and no other RP1 clock
    generator has pll_audio as an available parent. Confirmed against Circle
    source and upstream Linux clk-rp1.c.
    Resolved by generating MCLK off-chip on an Arduino Nano ESP32, wired to the
    PCM1808's SCKI pin independent of the Pi 5. Firmware (esp32-mclk/) flashed
    and bench-verified without an oscilloscope, using the chip's own PCNT
    peripheral in a self-test loopback: measure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
    [esp32-mclk.ino]
2026-07-10 Implement Milestone 3 audio engine: I2S full-duplex monitor path, lock-free SPMC ring, 4-core split
    Core 0 runs full-duplex I2S (DeviceModeTXRX, one device object) overriding
    GetChunk/PutChunk in DMA-completion IRQ context: capture publishes to a
    broadcast ring and a monitor FIFO, playback mixes the monitor path with
    silence-padding (never returns short - that would permanently stop the
    stream). Chunk = 32 words = 16 frames = 333 us; worst-case in->out ~1.0 ms.
    The capture ring (src/ringbuffer.h) is a single-producer broadcast ring
    with independent per-reader cursors and a seqlock-style reserve/commit
    index pair; host stress tests caught a real torn-read bug in the initial
    single-index desi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
    [kernel.cpp]
2026-07-10 Preserve project config.txt in SD staging; adopt device_tree_address fix
    sdcard/config.txt now carries device_tree_address=0x2000000 (moves the
    DTB clear of the enlarged 16 MB KERNEL_MAX_SIZE region - the firmware's
    default placement can land inside the kernel BSS and get zeroed before
    Circle reads it), hdmi_force_hotplug=1, and 32-bit framebuffer settings.
    build.sh no longer clobbers it from Circle's config64.txt template; the
    template only seeds a missing file.
    [config.txt]
2026-07-10 Record first hardware boot: M0 complete, Spike A retired, M3 engine verified live
    First boot 2026-07-10 (Pi 5 2GB, HDMI): all 4 cores up, I2S TXRX running,
    capture at exactly 48,000 frames/s, starve frozen at the one-time 16-frame
    startup priming, zero drops, zero ring overruns, storage drain at exactly
    384 KB/s. Spike A retired by a stronger proof than planned - the running
    RP1 I2S DMA itself. M3's remaining gate is the 10-min soak with real
    codecs (M2 wiring).
2026-07-10 Lower fan trip to 45 C; add ADC capture hookup bench card
    socmaxtemp=45 in both cmdline variants (Circle accepts 40-78; hysteresis
    puts fan-off at 40 C) and the kernel comments. No recompile needed - the
    kernel reads it from cmdline.txt at boot.
    docs/adc-hookup.md: every wire for the Pi 5 + PCM1808 + Nano ESP32
    capture side - power (two rails, 27W PD, Nano on its own USB-C, never
    its VIN at 5V), star ground, straps-before-power, clocks/data with pin
    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
2026-07-10 Add TL072-on-9V front-end variant (SPICE-verified) + CD4053BE rev-B notes
    The classic TL072 can't run the canonical 5V front-end (min ~7V supply,
    JFET common-mode >= V-+4V, output only to ~1.5V from rails) but works on
    a 9V pedal supply with two changes: the rail itself and VBIAS raised to
    4.9V (10k/12k). SPICE-verified with the same behavioral deck pattern:
    gain 9.54dB flat, ADC pin sees 1.02-3.97V on a hot humbucker, JFET
    common-mode clears its limit by 0.41V, and the op-amp itself never clips
    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
2026-07-10 Document the CopperSound breadboard + Gator 9V bench setup for the TL072 front-end
    Guitar jack, 9V DC entry, and breadboard space all come from the
    CopperSound DIY board; the Gator PSU is the matching center-negative
    supply. Signal crosses to the ADC via the board's output jack with the
    anti-alias RC placed at the VINL pin, plus one explicit ground wire to
    the star point.
2026-07-10 Pivot clock topology: PCM1808 masters the I2S bus, Pi runs slave
    Board research for the purple CJMCU-1808 breakout surfaced a real flaw
    in the planned clocking: in slave mode the PCM1808 requires SCKI
    frequency-locked to LRCK, and the Nano ESP32 and Pi 5 free-run on
    separate crystals - tens of ppm of drift would trip the chip's
    clock-resync logic (SLES177B section 7.4.2) into mute-and-fade cycles
    every fraction of a second. An RPi engineer publicly called the async
    arrangement a non-starter; the community-standard Pi wiring is ADC-as-
    master. claim-verification.md E2 walked back accordingly.
    Change: strap MD0=MD1=HIGH (master, 256fs -> SCKI/256 = 48 kHz), the
    ADC drives BCK/LRCK, and the ke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
    [kernel.cpp]
2026-07-21 Redraw wiring diagram + schematics as-built (post-f524c7d clock pivot)
    - docs/wiring-diagram.svg: bench block wiring, ADC-as-master — Nano ESP32
    MCLK -> CJMCU-1808 (bus master) -> Pi 5 slave + GY-PCM5102; three power
    domains, star ground at J8 p6. Render-verified.
    - docs/codec-power-schematic.svg: redrawn as the as-built per-pin sheet
    (silkscreen names, strap levels, drive directions, clock-division math).
    - docs/tl072-frontend-schematic.svg: NEW drawn sheet for the 9 V TL072
    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
2026-07-22 M2 adversarial review + purge the pre-pivot docs it caught
    6-lens adversarial review of the as-built M2 bench (docs/reviews/
    2026-07-21-m2-bench-adversarial-review.md). The token limit killed 3 of 6
    finder lenses and most verifiers, so 2 findings are fully verified (3/3
    refuters) and the rest are logged as Plausible/unverified — the review
    says so honestly.
    The doc-consistency lens proved commit 40a6248's stale-doc purge was
    incomplete. Fixed every file that still told a hand-wirer to build the
    OLD Pi-as-master topology:
    - hardware-review.md: pivot banner + corrected strap/clock-direction/BOM
    tables (was MD0/MD1->GND slave, Pi I2S0 master; README bills this as
    the authoritative netlis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
2026-07-22 Apply Claude Science's M2 verdicts (+ cross-check that corrected A4)
    Science recomputed the 7 physics/datasheet findings from primary sources;
    Code independently reproduced the load-bearing ones. Net: first light
    unaffected, one confirmed noise fix, one refuted rev-B cost, one
    correction back TO Science.
    - A4 (TL072 rail rejection): Science downgraded it to "common-mode x1,
    ~-87 dBFS". CORRECTED via ngspice PSRR of the actual deck: rail->ADC is
    -31.7 dB (x3) / -16.9 dB (max trim) -- VBIAS ripple is inverting-
    amplified by Rf/Rg because Cin shunts the + input to the low-Z guitar
    at 120 Hz; the x1 case only holds for an open input. The finder's
    -66 dBFS stands. Added 100uF||0.1uF by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
2026-07-23 UI pivot: drop touch — 5 rotary encoders + sustain pedal + display-only
    Michael's decision 2026-07-23: the interface is five encoder knobs
    (with push) + a Yamaha sustain-pedal footswitch + a plain display.
    Facts verified by a 4-agent pass (pinned Circle tree + primary sources):
    - Display: TD2 works display-only first-class (bEnableTouch=FALSE, GT911
    never powered, zero-GPIO property holds; rp1dsi drives ONLY official
    panels). HDMI = proven bench fallback. SPI TFT RULED OUT: pin budget
    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
2026-07-26 Debug Probe on the Pi 5: UART console + SWD multi-core debugging
    The Probe arrived (SC0889, the part docs/parts-order.md called for). Both of
    its jobs land on the Pi 5's single 3-pin JST connector and are mutually
    exclusive per boot, so this documents the switch between them.
    - docs/debug-probe.md: mode A (UART console, "U" port) vs mode B (SWD, "D"
    port, enable_jtag_gpio=1). Cabling is straight-through pin-1-to-pin-1 per
    RP-003139-SP — the TX/RX crossover is baked into the connector spec, so
    there is nothing to swap.
    - debug/openocd-rpi5.sh + debug/rpi5.cfg (from circle/tools/template) +
    debug/gdbinit with `reload` (load over the wire, break at main — no SD-card
    swap, no powe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
2026-07-26 docs: mode A (UART console) verified live on the Pi 5
    First working serial console on this project — the "no HDMI, no serial" handicap
    that forced LED-blink-code diagnosis since Milestone 0 is over.
    Recorded from the bench session:
    - device name tracks the USB port (cu.usbmodem11402 vs cu.usbmodem2102) — re-check
    ls /dev/cu.usbmodem* after every replug
    - a baud typo (11520 vs 115200) reads as a wiring fault but isn't: garbage output
    proves the cable is good, since a real cabling fault gives silence
    - all-zero counters (cap 0 / play 0 / laps 0/0) are CORRECT with no ADC wired, not a
    regression from the M3 48kHz verification — that predated the clock pivot. As slave
    the engine p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
2026-07-28 Freeze the M2 wiring for a solder-first build
    Michael is soldering the M2 audio board rather than breadboarding it, so
    every decision the docs deferred to "measure it on the bench first" had to
    be made now. docs/solder-build.md is the new authoritative spec; where it
    conflicts with adc-hookup.md, breadboard-build.md, hardware-review.md or
    schematic.md, it wins.
    Design changes (not just documentation):
    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
2026-07-28 Ignore the generated wiring preview page
    Rendered on demand from the SVG sheets for review in the browser pane; the
    sheets themselves are the source of truth.
2026-07-28 kicad: add rev-B netlist variant behind GDAW_REV=B (#3)
    Encodes the 2026-07-10 pivot as a GDAW_REV=B variant:
    - PCM1808 becomes I2S bus master: MD0/MD1 move from GND to +3V3
    - MCLK from Nano ESP32 (J4.1 = D2/GPIO5) through a 33R damping resistor
    into SCKI; GPIO4 removed from the J8 header (clk_i2s is claimed by BCLK)
    - 3.3V rail from Pi J8 pin 1; onboard AP2112K LDO not populated
    - Both Nano grounds land on the star ground
    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
    [bom-revB.csv]
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2026-07-31 power: restore bench config as current, 18V as target; KiCad GUI review (#5)
    PR #4 rewrote the bench cards as though the single-18V tree were built,
    but no 18V source exists yet. Restores the three-supply bench as the
    current configuration with 18V documented as the target.
    Restored for bench work: the Nano->Pi->Gator power-up ordering (down in
    reverse), and the load-bearing star-ground jumper warning -- with
    independent supplies a dropped ground jumper routes MCLK return plus
    inter-supply Y-cap leakage through the PCM1808's SCKI clamp. Both are
    relieved only by having a single source. The 45W PSU is in use, not
    dropped, and the parts list is corrected from the 27W SC1158.
    adc-hookup.md no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
    [check_pcb.py, render_pcb.py]
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
